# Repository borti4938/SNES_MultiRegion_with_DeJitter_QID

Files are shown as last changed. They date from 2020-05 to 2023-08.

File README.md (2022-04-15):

## Multi-Region Mod for any SNES

**Free your SNES**

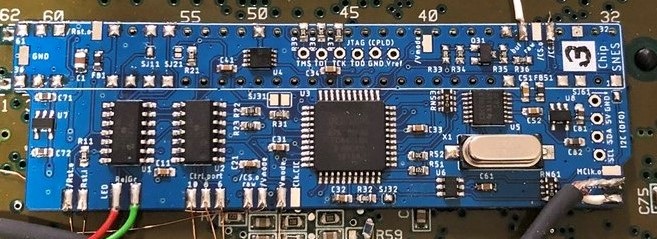
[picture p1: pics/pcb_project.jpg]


(picture shows last prototype PCB installed on a SNS-CPU-RGB-01)

### Acknowledgement and Licensing

This PCB, its idea and design, is a confluence of multiple projects. All credits and rights are going to their respective creators:

- **SuperCIC-lock** by Ikari_01
  Copyright (c) 2010 by Maximilian Rehkopf under GNU GPLv2
  Source: [sd2snes homepage](https://sd2snes.de/blog/cool-stuff/supercic)
- **uIGR** by Ikari_01 and borti4938
  Copyright (c) 2010 by Maximilian Rehkopf under GNU GPLv2,
  and modifications copyright (c) 2015 by Peter Bartmann under GNU GPLv2
  Source: [sd2snes homepage](https://sd2snes.de/blog/cool-stuff/in-game-reset), [this repository](./fw/uIGR)
- **Region Patch** built in SNES by Ikari_01 (initial idea and detection using SuperCIC-lock) and borti4938 (schematic refinement and CPLD implementation)
  Initial idea (c) 2012 ikari_01, CPLD implementation as used here covered in DeJitter license
  Source: [sd2snes homepage](https://sd2snes.de/files/supercic-213f.pdf)
- **DeJitter** by marqs85
  Copyright (c) 2017-2018 Markus Hiienkari under MIT
  and modifications and additions copyright (c) 2019 Peter Bartmann under MIT
  Source: [Original GitHub Repository](https://github.com/marqs85/snes_dejitter), [this repository](./fw/Logic)
- **DFO** by micro
  Copyright / created 2015 by Jakob Schäfer without licensing (but given to retro community)
  Source: mirror in [this repository](./fw/dfo), with minor adaptations and with several original sources noted [in the Source.md file](./fw/dfo/SOURCE.md)
- **PCB design** by borti4938
  Copyright (c) 2019 by Peter Bartmann under GNU GPLv3

### Features and Functions

##### In short

- **SuperCIC:** lockout chip replacement 50Hz/60Hz switch cabability
- **uIGR:** controller input sniffing to perform certain actions like reset or 60Hz and 50Hz switch up on certain combinations
- **Region Patch:** overrides region protection based on picture processing status reads
- **DeJitter:** removes jitter on sync for NTSC mode
- **DFO:** dual frequency oscillator, here used to switch between base clocks for 50Hz, 60Hz video-modes

##### SuperCIC

Hold down the reset button in order to swipe through 50Hz (green LED), 60Hz (red LED) or Auto-Region (yellow LED).

With the sd2snes you are able to pair the SuperCIC with the flash card. Then you'll be able to switch between 60Hz and 50Hz mode. However, you need to have the uIGR, which is master for the region setting, in SuperCIC pass through mode. Some more information is given [below](https://github.com/borti4938/SNES_MultiRegion_with_DeJitter_QID#using-a-modded-snes-with-flashcards).

##### uIGR

The uIGR sniffs the controller inputs directly at the controller port. Therefor it is able to detect certain button combinations. All button combinations are collected in an overview PDF, which is available in [German](https://github.com/borti4938/SNES_MultiRegion_with_DeJitter_QID/blob/master/fw/uIGR/Manuals/uIGR_Anleitung.pdf) and [English](https://github.com/borti4938/SNES_MultiRegion_with_DeJitter_QID/blob/master/fw/uIGR/Manuals/uIGR_Manual.pdf). Here are the most important ones:

- Region forcing:
  - 60Hz: L + R + Select + A
  - 50Hz: L + R + Select + Y
  - Auto: L + R + Select + B
  - S-CIC pass through: L + R + Select + D-pad left OR L + R + Select + D-pad right
- Reset:
  - simple reset: L + R + Select + Start
  - double reset (back to main menu of sd2snes): L + R + Select + X

##### Region Patch

Overwrites region if game request register $213F, where bit 4 represents the region. Region patching can be disabled (see [uIGR PDFs](https://github.com/borti4938/SNES_MultiRegion_with_DeJitter_QID/tree/master/fw/uIGR/Manuals)). You also have to consider switching off the region patch if using non-original cartridges or [flash cards](https://github.com/borti4938/SNES_MultiRegion_with_DeJitter_QID#using-a-modded-snes-with-flashcards) (sd2snes with Pairmode with SuperCIC is not a problem).

##### DeJitter

In NTSC mode the SNES outputs a shorter scanline in non-visible area. This might be an issue for certain TVs if you use pure analog to digital conversion without frame buffer like the OSSC does. DeJitter 'removes' this shorter line by pausing the clock for a few cycles.

As drawback this mechanic varies output timing a bit, however the inaccuracy is neglectable when comparing it to clock variations throughout different consoles.

At the moment, DeJitter is enabled by default and can only be disabled by setting jumper _SJ31_.

##### DFO

Short for dual frequency oscillator. Actually in combination with the CPLD this allows to switch between three output clocks plus two color carrier clocks. If modding board is correctly installed, there is nothing special to consider here.

### PCB Description

#### Solder Pads

These are just general descriptions of the in- and outputs. Please refer to the installation instructions for each [specific mainboard version](./installation/) (if exists) for suitable connections.

- **/Rst.o:** (output (2x))
  Low-active reset output. This has to be connected with CIC-lock pad 10 / S-APU pin 100. Connect either pad.
- **Rst.i:** (input)
  High-active reset input. This pad has to be connected with the CIC-lock pad 8 (reset button).
- **LED.Re:** (output)
  LED driver for replacement LED; usually red. Output is active on 60Hz and auto video mode and off on 50Hz (or vice versa if SJ21 is set (common anode LED))
- **LED.Gr:** (output)
  LED driver for replacement LED; usually green. Output is active on 50Hz and auto video mode and off on 60Hz (or vice versa if SJ21 is set (common anode LED))
- **Ctrl.port.10:** (input)
  Input for controller 1 sniffing (data latch signal). _Port_ refers to flat cable connector of the whole controller panel, i.e. pin is equivalent for controller connector pin 3.
- **Ctrl.port.8:** (input)
  Input for controller 1 sniffing (data clock signal). _Port_ refers to flat cable connector of the whole controller panel, i.e. pin is equivalent for controller connector pin 2.
- **Ctrl.port.6:** (input)
  Input for controller 1 sniffing (serial data signal). _Port_ refers to flat cable connector of the whole controller panel, i.e. pin is equivalent for controller connector pin 4.
- **Vmode:** (output)
  Output sets the PPU video mode at S-PPU1 pin 24 and S-PPU2 pin 30 or at the S-CPUN pin 111. Output is active on 50Hz mode and inactive on 60Hz mode.
- **/Vmode:** (output (2x))
  Output sets the video encoding at the video encoder, which is pin 19 of the S-ENC and pin 9 of the S-RGB. Connect just on of the pads!
- **Clk.CIC:** (input)
  Input for the SuperCIC-lock clock, which comes from CIC pad 7.
- **MClk.o:** (output)
  Output for the (de-jittered) master clock of the SNES. This is approx. 21.477MHz in NTSC mode and appr. 17.734MHz (1Chip-SNES, SJ32 not set) or appr. 21.281MHz (non-1Chip, SJ32 set) in PAL mode. Please refer to the general installation note to see whether and how to connect this pad properly.
- **CClk.o:** (output)
  Output of the color carrier, which is appr. 3.380MHz in NTSC mode and appr. 4.433MHz in PAL mode. Please refer to the general installation note to see whether and how to connect this pad properly.
- **/CS.i:** (input (2x since SMR20190813)
  Input of the 'original' (non-de-jittered) composite sync. This comes from pin 100 S-PPU2 or pin 151 S-CPUN.
- **/CS.o buf:** (output)
  Buffered (de-jittered) composite sync output. This is meant to be connected directly to the multiout pin 3. Note: The PAL SNES has 12V connected to this pin, which has to be removed.
- **/CS.o raw:** (output (2x))
  Raw output of the CPLD, which has 3.3V high and 0V low level. Connect it to the video encode, which is pin 8 of the S-ENC or pin 7 of the S-RGB (both chips allows 2.0V for input high, so 3.3V high is sufficient.)

#### Jumper

- **SJ11:** alternative clock for the SuperCIC; close this jumper if you don't connect the _Clk.CIC_ pad in order to use the clock meant for the CIC-key
- **SJ21:** close this jumper if you use a LED with a common anode. Otherwise leave this jumper untouched
- **SJ31:** closing this jumper permanently disables the de-jitter function. This solder jumper is a bit larger to give the installer the option to connect a slide switch here (_speed-runner discussions_).  
   - There is also an issue opened in [marqs85 DeJitter repository](https://github.com/marqs85/snes_dejitter/issues/9) reported by [BambooShadow](https://github.com/BambooShadow), which states that composite video and s-video becomes flickery. This is probably related to the S-RGB encoder chip on SNS-CPU-RGB-01 and later models (PAL: SNSP-CPU-1CHIP-01 and later). In any case, you can disable DeJitter if this is also an issue for you.  
   - I personally recommend to turn DeJitter off. Turn DeJitter only on if you use simple line doublers like the OSSC and if you have any issue on getting a proper picture.
- **SJ32:** short this jumper if the board is installed in a non-1Chip-SNES (SNES Jr. / SNES2 are also 1Chip-SNES)
- **SJ61:** distributes clock output to cartridge slot pin 1. This jumper **must not** be closed in 1Chip-SNES. Side note: if SJ32 is open, SJ61 has to open, too.
- **SJ63:** (since SMR20200323) decides which color carrier is forwarded to output. This jumper has two option; you must not close both jumpers!
  - SJ63.1: (marked with a dot) outputs color carrier derived from non-dejittered clock.  
    Use this if you have a problem with discoloring on composite video or S-Video ([issue thread at shmups](https://shmups.system11.org/viewtopic.php?p=1389666#p1389666))  
    Btw: this is default for all earlier version of the modding board flashed with the current firmware. If you need the other color carrier, just go back to a previous version.
  - SJ63.2: outputs color carrier derived from dejittered clock.  
    (I personally need to use this clock as my TV does not like the color carrier from non-dejittered clock)
  - Again: **You must not close both jumpers!**
- **SJ93**: (since SMR20200323) controls sync level of buffered csync output. Sync level:
  - opened: appr. 1.87V @ 75ohm termination i.e. needs a resistor inside the sync wire further attanuating the signal. Designed to work for cables with 470 ohm resistor inside resulting in appr. 450mV @ 75ohm termination
  - closed: appr. 300mV @ 75ohm termination suitable for pass through wired cables at sync, works with standard TV / scaler setup

#### Firmware

U1, U2, U3 and U5 need a firmware flashed to the chip. U1 and U2 have to be programmed prior to assembly whereas the PCB provides ICSP headers for the other ones.

- **U1:** PIC 16F630 microcontroller with - [SuperCIC-lock firmware](http://sd2snes.de/files/supercic.zip)
- **U2:** PIC 16F684 microcontroller with [uIGR firmware](https://raw.githubusercontent.com/borti4938/SNES_MultiRegion_with_DeJitter_QID/master/fw/uIGR/snes_uigr_684_with_lock.hex)

Use a PICKit, TL866CS or similar programmer.

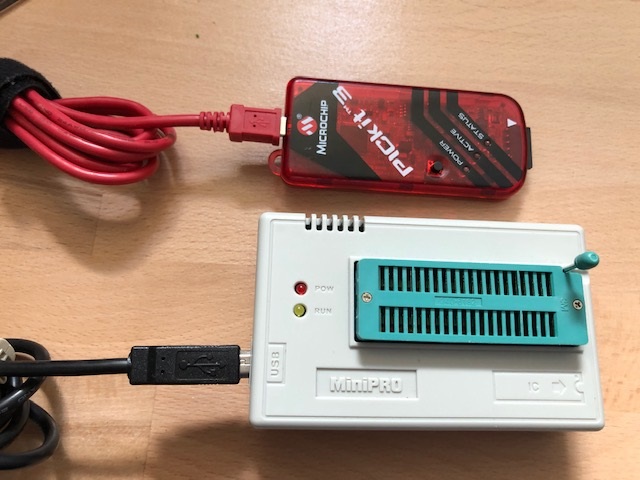
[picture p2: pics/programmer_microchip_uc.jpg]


- **U3:** _ATMEL_ CPLDs: ATF1502ASV or ATF1504ASV(L) CPLD with clock switch, region patch and de-jitter firmware. Pre-build firmware only supports SMR20190813 (and later) modding boards.

  - [ATF1502ASV](https://github.com/borti4938/SNES_MultiRegion_with_DeJitter_QID/raw/master/fw/Logic/output_files/multi_func_atmel/multi_function.svf)
  - [ATF1504ASV(L)](https://github.com/borti4938/SNES_MultiRegion_with_DeJitter_QID/raw/master/fw/Logic/output_files/multi_func_atmel/multi_function_64.svf)
  
Use an OpenOCD compatible JTAG programmer. I tested the workflow with an [Adafruit FT232H Breakout Board](https://www.adafruit.com/product/2264), yet you can use any other JTAG programmer that supports 3.3V IO signal levels.

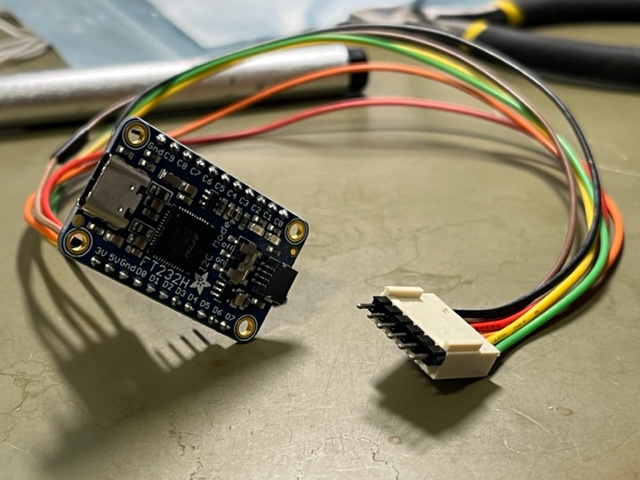
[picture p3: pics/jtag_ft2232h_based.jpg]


1. Create an openocd.conf that matches your JTAG programmer. A configuration files for FT2232-based and FT2232H programmers are found in the [firmware folder](./fw/Logic/output_files/multi_func_atmel/). They use following standard pinout for data signals:  
  - ADBUS0 -> TCK
  - ADBUS1 -> TDI
  - ADBUS2 -> TDO
  - ADBUS3 -> TMS
2. Connect the JTAG programmer the modding board, except for Vref! Power the board via 5V during programming.  This can be done by using the DFO programmer connected with V_target set to 5V (or 3.3V) if the modding board is not installed yet (other power solutions are possible, but please use the 5V power supply rail to not harm the DC converters. Or you can simply switch on the SNES for programming. Of course, the CPLD can be also flashed prior to assembly if you have a proper adapter at hand.
3. Initialize the JTAG connection:  
~~~~
openocd -f openocd-ft2232h.conf
~~~~  
OpenOCD should detect the JTAG chain without any errors. If you have any, just double-check if everything is well connected and the CPLD is powered.

4. When successful, open another terminal to interact with openocd and program the chip:  
~~~~
telnet localhost 4444
> svf <full_path_to_svf_file>
~~~~  
Wait for the program to be finished.

- **U3:** _obsolete Altera / intelFPGA CPLDs_: EPM7032 or EPM7064 CPLD with clock switch, region patch and de-jitter firmware. You have to choose the right one depending on your modding board version.

  - [Version SMR20190813 (and later), EPM7032](https://github.com/borti4938/SNES_MultiRegion_with_DeJitter_QID/raw/master/fw/Logic/output_files/multi_func/multi_function.pof)
  - [Version SMR20190813 (and later), EPM7032](https://github.com/borti4938/SNES_MultiRegion_with_DeJitter_QID/raw/master/fw/Logic/output_files/multi_func/multi_function_64.pof)
  - [Version SMR20190603 and earlier](https://github.com/borti4938/SNES_MultiRegion_with_DeJitter_QID/raw/master/fw/Logic/output_files/multi_func_legacy/multi_func_legacy.pof)

Use an Altera USB Blaster (or clone) for flashing the firmware.

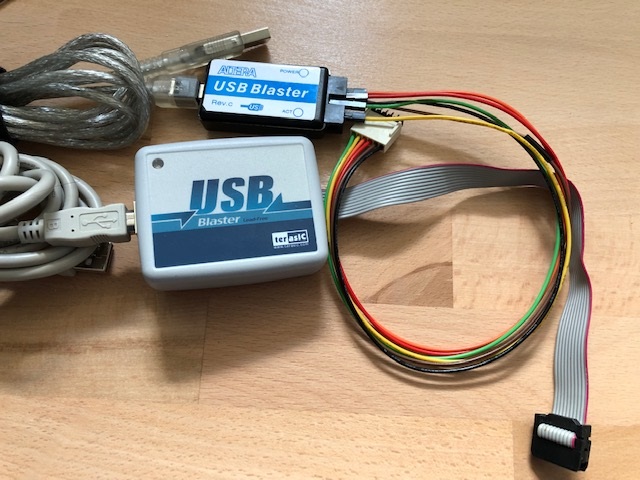
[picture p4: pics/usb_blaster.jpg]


After assembly, the modding board has to be powered for flashing the firmware. This can be done by using the DFO programmer connected with V_target set to 5V (or 3.3V) if the modding board is not installed yet (other power solutions are possible, but please use the 5V power supply rail to not harm the DC converters. Or you can simply switch on the SNES for programming. Of course, the CPLD can be also flashed prior to assembly if you have a proper adapter at hand.

- **U5:** CDCE913 with [appropriate configuration](https://raw.githubusercontent.com/borti4938/SNES_MultiRegion_with_DeJitter_QID/master/fw/dfo/clockpro/snes_multi_region.hex)

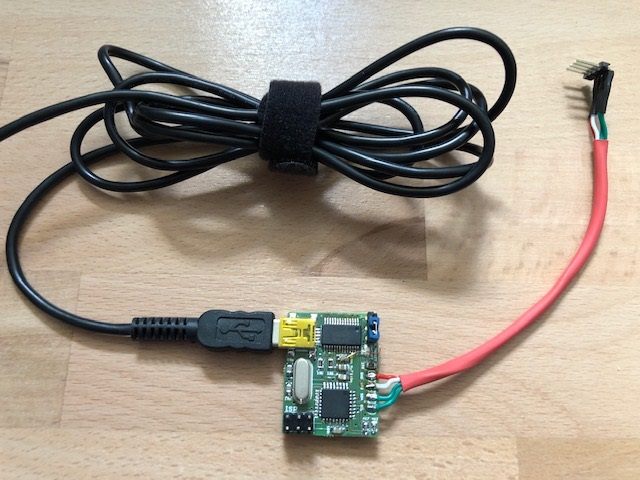
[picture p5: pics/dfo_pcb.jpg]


Use the DFO programmer to flash the PLL. The [DFO readme](./fw/dfo/SOURCE.md) describes how to properly perform the flashing.
I alternatively wrote a [program for Arduino boards](./fw/dfo/arduino/) to flash the CDCE913 with the I2C interface of the Arduino.
I tested the code with an Arduino Nano and Arduino Nano Every.

### Installation Notes

#### Manufacturing the PCB

You can choose any manufacturer which you prefer. All files for manufacturing including the design files are provided in subfolder [pcb/gerber/pcb/](./pcb/gerber/pcb/). As the PCB is designed in EAGLE (current version 7.4.2), gerbers are exported in the actual format. However, some services have problem while automatically analyze those like OSHPark or JCLPCB. Please try the older format in [pcb/gerber/pcb.eagle_legacy_export/](./pcb/gerber/pcb.eagle_legacy_export/).

**IMPORTANT**
Please use a substrate thickness of 0.8mm in order to make installation easier.

#### Assembly

##### Sourcing the Parts

For sourcing the parts, please be referred to the [Bill Of Materials](https://github.com/borti4938/SNES_MultiRegion_with_DeJitter_QID/blob/master/pcb/BOM.xlsx?raw=true)

##### Soldering

The PCB is designed with having hand soldering in mind. Most complicated footprints are probably the 44TQFP package of the CPLD or the 14TSSOP of the CDCE913.

However, if you plan to use a stencil, you can use the [stencil gerber file](./pcb/gerber/stencil/SNES_MR_DeJitter_QID.GTP). All SMDs are placed in top layer.

**IMPORTANT**
SuperCIC (PIC16F630-I/SL) and uIGR (PIC16F684-I/SL) need firmware flashed prior to soldering as mentioned later in this document.

#### Installation

This is not a complete installation manual. It's moreover a general overview on _'HowTo'_. Installation manuals are provided in the [subfolder installation](./installation/) once ready. I cannot test every single mainboard revision (there are too many out there), so the installation folder will grow from time to time once I see a proper report of an installation or I did an installation on a specific mainboard version on my own.

##### Preparation of SNES

###### General Steps

- remove original CIC-lock (or at least lift pins 1, 2, 10 and 11)
- remove LED from front panel (large SNES only)

###### Specific Steps for 1Chip-SNES

- lift pin 111 from S-CPUN
- remove X1
- lift pin 9 from S-RGB (or cut encoding mode jumper at bottom side of SNES mainboard (NTSC board revisions))

###### Specific Steps for Non-1Chip-SNES

- lift pin 24 of S-PPU1 and pin 30 of S-PPU2
- disconnect Master-Clock
  - SNSP-CPU-01/02: lift pin 4 of the S-CLK or remove R73 (0ohm jumper)
  - different methods for NTSC mainboards
- lift CSYNC input pin of the video encoder
  - pin 8 of S-ENC
  - pin 7 of S-RGB
- if you want to switch color carrier:
  - PAL: lift pin 5 of the S-CLK
  - NTSC: lift pin 3 of the S-PPU2
  - SNES with S-ENC: lift pin 19 (or cut encoding mode jumper at bottom side of SNES mainboard (NTSC board revisions))
  - SNES with S-RGB: lift pin 9 (or cut encoding mode jumper at bottom side of SNES mainboard (NTSC board revisions)) 

##### Installation of PCB

###### General Steps

- Solder PCB in place under the cartridge slot. Be aware of the orientation (pin marking must match)
- put the replacement dual LED where the original was (use a small piece of hot glue if needed)...  
... or in SNES2 / Jr. think of a good place where the replacement LED can be if you want to use it...  
... and connect the common pole to either _Ground_ or _Vcc_ (common cathod or anode, respectively)
- connect pads _Rst.o, Rst.i, LED.Re, LED.Gr, Ctrl.port.10-6, Vmode, /CS.i, /CS.o (raw)_ according to their description
- either connect _Clk.CIC_ pad (preferable) or close jumper _SJ11_
- close jumper _SJ21_ if you use a LED with common anode

###### Specific Step for 1Chip-SNES

- connect _MCLK.o_ to X1 (the side which is connected to S-CPUN pin 9)
- connect _/Vmode_ to S-RGB pin 9
- (color carrier is switched by S-CPUN so there is no need to connect _CClk.o_)

###### Specific Step for Non-1Chip-SNES 

- close _SJ32_ and _SJ61_
- if you plan to switch color carrier:
  - connect _CClk.o_ to either pad 3 of S-PPU2 (NTSC) or to pad 5 of S-CLK (PAL)
  - connect _/Vmode_ to S-ENC pin 19 / S-RGB pin 9 

### Using a Modded SNES with Flashcards

In general, using flashcards like the sd2snes, SuperEverdrive and PowerPak together with the **region patching** activated is not a good idea. I try to explain why!

First of all, one has to understand how a region patch works. In the S-PPU2 register $213F bit 4 shows whether the SNES is running in NTSC-mode or in PAL-mode (set up using S-PPU2 pin 30 or S-CPUN pin 111). Many games are checking this register on start-up (or during the gameplay) and check the value on bit 4. NTSC-games expect a '0' whereas PAL-games a '1'. If the bit does not return the required value, the game ends with _'This gamepak is not designed for your SFC/SNES'_ or similar.
A region patch observes the address bus B and recognizes a request of $213F. Then the patch forces on the data bus bit 4 GND or Vcc by simply 'beating'/'overdriving' the output of the S-PPU2.

An important point is how the region patch 'knows' which value has to be written.
On this modding PCB the SuperCIC-lock outputs the value on pin 3. The bit is determined using the CIC-key found on the cartridge. And this is the point where flash-cards become 'critical' for the region patch. As the SuperCIC-lock only checks the region of the cartridge using the CIC-key, the SuperCIC-lock CANNOT know which region the loaded ROM is. The overwritten value on bit 4 during a $213F request might be incorrect!
As flashcards have there own region patching (at least the sd2snes; I don't own a SuperEverdrive or PowerPak) you can simply switch off the region patch of the modding PCB (using Sel+L+R+Dw; LED-code: red-off-red).

#### A very last remark to the sd2snes:
As the SuperCIC-lock is part of the sd2snes project, there is another solution: the so-called 'Pairmode'.
The pairmode is available with the firmware v0.1.7 preview 4 or later. In the Pairmode the SuperCIC-lock goes into a pairmode-loop with the sd2snes. In this loop, forced region, LED status and the ROM region is constantly updated.

To change the forced region (and thus the LED-state) using the sd2snes (via the config.yml or the option GUI -> SuperCIC Settings), the uIGR has to be in the SuperCIC-mode (using Sel+L+R+Le / Sel+L+R+Ri) as the uIGR is master and the SuperCIC-lock slave regarding the region set to the SNES.
As the ROM region is updated constantly, the region patch on the modding PCB can be left on. I recommend to switch the sd2snes-own region patch off in this case (via the config.yml or the option GUI -> In-game Settings).

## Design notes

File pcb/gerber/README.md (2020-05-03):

(text copied from main [README](../README.md))

#### Manufacturing the PCB

You can choose any manufacturer which you prefer. All files for manufacturing including the design files are provided in subfolder [pcb/](./pcb/). As the PCB is designed in EAGLE (current version 7.4.2), gerbers are exported in the actual format. However, some services have problem while automatically analyze those like OSHPark or JCLPCB. Please try the older format in [pcb.eagle_legacy_export/](./pcb.eagle_legacy_export/).

For using the OSHPark service, you can also use my [uploaded project](https://oshpark.com/shared_projects/6n0e1VDd).

##### Soldering

The PCB is designed with having hand soldering in mind. Most complicated footprints are probably the 44TQFP package of the CPLD or the 14TSSOP of the CDCE913.

However, if you plan to use a stencil, you can use the [stencil gerber file](./stencil/SNES_MR_DeJitter_QID.GTP). All SMD are placed in top layer.

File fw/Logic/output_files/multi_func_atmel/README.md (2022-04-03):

Use this firmware for SNES [Multi Region Boards](https://github.com/borti4938/SNES-AddOn-PCBs/tree/master/MultiRegion_with_DeJitter_QID) of version V20190813 (and later).

These firmware files are for the Atmel CPLD equivalents and introduced in this repository as the Altera CPLDs became obsolete.

Conversion of the Altera firmware build to the Atmel ATF1502ASV or ATF1504ASV(L):

- Use [pof2jed](http://www.microchip.com/design-centers/programmable-logic/spld-cpld/tools/software/pof2jed) conversion tool to convert \*.pof from Quartus output to \*.jed usable with the Atmel CPLD. Use the settings as shown
- Use [ATMISP](http://www.microchip.com/design-centers/programmable-logic/spld-cpld/tools/software/atmisp) software to convert the JED file to a SVF file, which can be used with OpenOCD
  - Create a new device chain via File->New
  - Set number of devices to 1
  - Set device to ATF1502ASV or ATF1504ASV(L)
  - Set JTAG instruction to "Program/Verify"
  -  Select .jed file from previous step as JEDEC file
  - Click "OK"
  - Tick "Write SVF file" and click "Run"

##### Setting for WinPOF2JED tool:

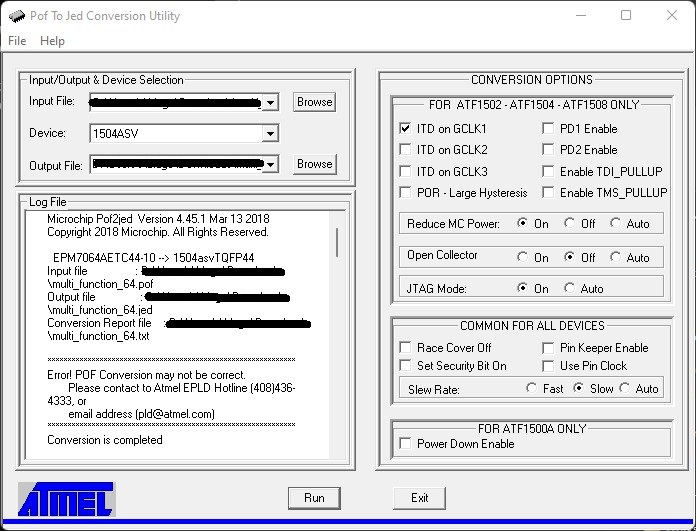
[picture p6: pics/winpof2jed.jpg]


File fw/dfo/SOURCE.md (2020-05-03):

### DFO

#### Acknowledgement and Licensing

Original source by community user _micro_. All rights goes to him.

- Source @ Circuit-Board.de: [Link](https://circuit-board.de/forum/index.php/Thread/18016-DFO-Dual-Frequency-Oscillator/)
- Source @ NFGgames: [Link](https://nfggames.com/forum2/index.php?topic=5744.0)
- Source @ OSHPark: [Link](https://oshpark.com/shared_projects/SeJLCY52)

Source links will forward you to original source codes. Source codes provided in this repository are just mirrors.

#### Modifications Compared to Original Source

Modifications made by Peter Bartmann aka borti4938 in 2019:

- PCB: remove slide switch and replace it with pin header
- Allow V_target to be at 5V (right position shorted)

#### Firmware for Programmer

Microcontroller on the programmer PCB needs a firmware (written by micro) in order to work properly. Use the firmware provided in [this subfolder](./CDCE9XX_PROGRAMMER_FW_v1) or the one in the original source. Please make sure to set the [fusebytes](./CDCE9XX_PROGRAMMER_FW_v1/fusebytes.txt) correctly. 

#### Program the CDCE913 (DFO) on the MultiRegion PCB

Use the [GUI](./CDCE9XX_Programmer_GUI_v1.1/CDCE9XX_PROGRAMMER.exe) (software written by micro) in order to program the PLL. This is required in order to get the DeJitter and on-board color carrier switch working. To program the PLL perform the following steps:

##### modding board not installed

- Set V-target jumper on programmer to 5V
- Connect programmer to modding board
  (make sure that the connector is matched otherwise you may harm your modding board!)
- Connect USB cable to Windows PC
- Launch [programmer app](./CDCE9XX_Programmer_GUI_v1.1/CDCE9XX_PROGRAMMER.exe)
- Load [hex-file](./clockpro/snes_multi_region.hex) for the CDCE913 by clicking on _Load Configuration File_
- Click on _Program CDCE9xx_ button
- Disconnect everything once finished

##### modding board installed in SNES

- Leave V-target jumper open
- Connect programmer to modding board
  (make sure that the connector is matched otherwise you may harm your modding board and/or the DFO programmer!)
- Connect USB cable to Windows PC
- Switch on SNES
- Launch [programmer app](./CDCE9XX_Programmer_GUI_v1.1/CDCE9XX_PROGRAMMER.exe)
- Load [hex-file](./clockpro/snes_multi_region.hex) for the CDCE913 by clicking on _Load Configuration File_
- Click on _Program CDCE9xx_ button
- Disconnect everything once finished

#### Picture



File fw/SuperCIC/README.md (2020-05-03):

##### Source Code

... can be downloaded at [sd2snes.de](https://sd2snes.de/blog/cool-stuff/supercic) [direct download link](http://sd2snes.de/files/supercic.zip)

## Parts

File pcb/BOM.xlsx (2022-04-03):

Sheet: SMR20200325
Version: | SMR20200325
Number of PCBs: |  |  | 3
Designator | MPN | QTY/PCB | QTY | DESCRIPTION | VALUE | PACKAGE | NOTES | Digikey | Mouser | Firmware
U1 | PIC16F630-I/SL | 1 | 3 | 8bit Microcontroller |  | SOIC-14 | needs SuperCIC-lock firmware preflashed |  |  | http://sd2snes.de/files/supercic.zip
U2 | PIC16F684-I/SL | 1 | 3 | 8bit Microcontroller |  | SOIC-14 | needs uIGR FW preflashed |  |  | https://github.com/borti4938/Switchless-Mods/tree/master/SNES/uigr_16f684
U3 | ATF1502ASV-15AU44 | 1 | 3 | CPLD, 32MCs, 3.3Vcc, 5V tolerant I/Os |  |  | fw can be flashed using JTAG header |  |  | https://github.com/borti4938/snes_dejitter/tree/regionpatch%2Bdejitter/output_files/multi_func_atmel/multi_function.svf
 | ATF1504ASV-15AU44 / ATF1504ASVL-20AU44 |  |  | CPLD, 64MCs, 3.3Vcc, 5V tolerant I/Os |  |  | alternative for U3 / fw can be flashed using JTAG header |  |  | https://github.com/borti4938/snes_dejitter/tree/regionpatch%2Bdejitter/output_files/multi_func_atmel/multi_function_64.svf
 | EPM7032AETC44-10N |  |  | CPLD, 32MCs, 3.3Vcc, 5V tolerant I/Os |  | TQFP44 | alternative for U3, obsolete cpld, yet can be found on Aliexpress / fw can be flashed using JTAG header |  |  | https://github.com/borti4938/SNES_MultiRegion_with_DeJitter_QID/blob/master/fw/Logic/output_files/multi_func/multi_function.pof
 | EPM7064AETC44-10N |  |  | CPLD, 64MCs, 3.3Vcc, 5V tolerant I/Os |  | TQFP44 | alternative for U3, obsolete cpld, yet can be found on Aliexpress / fw can be flashed using JTAG header |  |  | https://github.com/borti4938/SNES_MultiRegion_with_DeJitter_QID/blob/master/fw/Logic/output_files/multi_func/multi_function_64.pof
U4 | 74HCT2G125DP | 1 | 3 | IC BUFFER NON-INVERT with /OE |  | TSSOP8, SOT505-2
U5 | CDCE913PWR | 1 | 3 | IC PROG PLL VCXO CLK SYN |  | 14TSSOP | I2C accessable over PCB header |  |  | https://github.com/borti4938/SNES-AddOn-PCBs/tree/master/MultiRegion_with_DeJitter_QID/dfo/clockpro
U6 | SN74LVC2G17DBVR | 1 | 3 | IC BUFFER NON-INVERT, Schmitt Trigger |  | SOT-23-6
U7 | TLV70033DDCR | 1 | 3 | LDO 3.3V |  | SOT-23-5
U8 | TLV70018DDCR | 1 | 3 | LDO 1.8V |  | SOT-23-5
U9 | TSH122ICT | 1 | 3 | Video Driver, 6dB, 1 Ch. |  | SC-70-6
X1 | 9C-27.000MAAJ-T | 1 | 3 | CRYSTAL 27.0000MHZ 18PF | 27MHz | HC-49/US
C1,C94 | (22uF cap 0603) | 2 | 6 | Ceramic capacitor, X5R | 22uF / 16V | SMD0603
C11,C21,C31,C32,C33,C34,C41,C51,C52,C61 | (100nF cap 0603) | 10 | 30 | Ceramic capacitor, X7R | 0.1uF / 50V | SMD0603
C71,C72,C81,C82 | (1uF cap 0603) | 4 | 12 | Ceramic capacitor, X5R | 1uF / 6.3V | SMD0603
C91 | (10uF cap 0603) | 1 | 3 | Ceramic capacitor, X5R | 10uF / 25V | SMD0603
C92 | (10nF cap 0603) | 1 | 3 | Ceramic capacitor, X7R | 0.01uF / 50V | SMD0603
C93 | (33uF cap 0805) | 1 | 3 | Ceramic capacitor, X5R | 33uF / 5V | SMD0805
FB1,FB51 | MPZ1608S221A | 2 | 6 | Ferrit bead, power line |  | SMD0603
R11,R21,R32,R38,R39,R52,R63 | RC0603FR-0710KL | 7 | 21 | Resistor | 10k | SMD0603
R22,R23 | RC0603FR-07180RL | 2 | 6 | Resistor | 180 | SMD0603
R31,R37 | RC0603FR-071KL | 2 | 6 | Resistor | 1k | SMD0603
R51 | RC0603FR-0722KL | 1 | 3 | Resistor | 22k | SMD0603
R53,R54,R61 | RC0603FR-0739RL | 3 | 9 | Resistor | 39 | SMD0603
R62 |  | 0 | 0 | Resistor / Jumper |  | SMD0805 | resistor taken from SNES mainboard / jumper closed, if CClk.o directly connected to SNES
R91 | RC0603FR-074K7L | 1 | 3 | Resistor | 4.7k | SMD0603
R92 | RC0603FR-076K19L | 1 | 3 | Resistor | 6.19k | SMD0603
R93 | RC0603FR-07523RL | 1 | 3 | Resistor | 523 | SMD0603
R94 | RC0603FR-0775RL | 1 | 3 | Resistor | 75 | SMD0603
Optional components
(LED) | WP59SURKSGW | 1 | 3 | example replacement LED bi-color with common cathode | red / green
(pin header for LED connection) | 61900211021 | 1 | 3 | pin header for LED connection
 | 61900211621 | 1 | 3 | connector housing 2-pos. Female 2.54mm
 | 61900113722DEC | 2 | 6 | connector socket for 22-28AWG crimp

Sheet: SMR20190813
Version: | SMR20190813
Number of PCBs: |  |  | 3
Designator | MPN | QTY/PCB | QTY | DESCRIPTION | VALUE | PACKAGE | NOTES | Digikey | Mouser | Firmware
U1 | PIC16F630-I/SL | 1 | 3 | 8bit Microcontroller |  | SOIC-14 | needs SuperCIC-lock firmware preflashed |  |  | http://sd2snes.de/files/supercic.zip
U2 | PIC16F684-I/SL | 1 | 3 | 8bit Microcontroller |  | SOIC-14 | needs uIGR FW preflashed |  |  | https://github.com/borti4938/Switchless-Mods/tree/master/SNES/uigr_16f684
U3 | ATF1502ASV-15AU44 | 1 | 3 | CPLD, 32MCs, 3.3Vcc, 5V tolerant I/Os |  |  | fw can be flashed using JTAG header |  |  | https://github.com/borti4938/snes_dejitter/tree/regionpatch%2Bdejitter/output_files/multi_func_atmel/multi_function.svf
 | ATF1504ASV-15AU44 / ATF1504ASVL-20AU44 |  |  | CPLD, 64MCs, 3.3Vcc, 5V tolerant I/Os |  |  | alternative for U3 / fw can be flashed using JTAG header |  |  | https://github.com/borti4938/snes_dejitter/tree/regionpatch%2Bdejitter/output_files/multi_func_atmel/multi_function_64.svf
 | EPM7032AETC44-10N |  |  | CPLD, 32MCs, 3.3Vcc, 5V tolerant I/Os |  | TQFP44 | alternative for U3, obsolete cpld, yet can be found on Aliexpress / fw can be flashed using JTAG header |  |  | https://github.com/borti4938/SNES_MultiRegion_with_DeJitter_QID/blob/master/fw/Logic/output_files/multi_func/multi_function.pof
 | EPM7064AETC44-10N |  |  | CPLD, 64MCs, 3.3Vcc, 5V tolerant I/Os |  | TQFP44 | alternative for U3, obsolete cpld, yet can be found on Aliexpress / fw can be flashed using JTAG header |  |  | https://github.com/borti4938/SNES_MultiRegion_with_DeJitter_QID/blob/master/fw/Logic/output_files/multi_func/multi_function_64.pof
U4 | 74HCT2G125DP | 1 | 3 | IC BUFFER NON-INVERT with /OE |  | TSSOP8, SOT505-2
U5 | CDCE913PWR | 1 | 3 | IC PROG PLL VCXO CLK SYN |  | 14TSSOP | I2C accessable over PCB header |  |  | https://github.com/borti4938/SNES-AddOn-PCBs/tree/master/MultiRegion_with_DeJitter_QID/dfo/clockpro
U6 | SN74LVC2G17DBVR | 1 | 3 | IC BUFFER NON-INVERT, Schmitt Trigger |  | SOT-23-6
U7 | TLV70033DDCR | 1 | 3 | LDO 3.3V |  | SOT-23-5
U8 | TLV70018DDCR | 1 | 3 | LDO 1.8V |  | SOT-23-5
Q31 | 2SC2412KT146R | 1 | 3 | TRANS NPN 50V 0.15A |  | TO-236-3, SC-59, SOT-23-3
X1 | 9C-27.000MAAJ-T | 1 | 3 | CRYSTAL 27.0000MHZ 18PF | 27MHz | HC-49/US
C1 | (22uF cap 0805) | 1 | 3 | Ceramic capacitor, X5R | 22uF / 16V | SMD0805
C11,C21,C31,C32,C33,C34,C41,C51,C52,C61 | (100nF cap 0603) | 10 | 30 | Ceramic capacitor, X7R | 0.1uF / 50V | SMD0603
C71,C72,C81,C82 | (1uF cap 0603) | 4 | 12 | Ceramic capacitor, X5R | 1uF / 6.3V | SMD0603
FB1,FB51 | MPZ1608S221A | 2 | 6 | Ferrit bead, power line |  | SMD0603
R11,R21,R32,R34,R38,R39,R52 | RC0603FR-0710KL | 7 | 21 | Resistor | 10k | SMD0603
R22,R23 | RC0603FR-07180RL | 2 | 6 | Resistor | 180 | SMD0603
R31,R33,R37 | RC0603FR-071KL | 3 | 9 | Resistor | 1k | SMD0603
R35 | RC0603FR-07300RL | 1 | 3 | Resistor | 300 | SMD0603
R36 | RC0603FR-07100RL | 1 | 3 | Resistor | 100 | SMD0603
R51 | RC0603FR-0722KL | 1 | 3 | Resistor | 22k | SMD0603
R53,R54,R61 | RC0603FR-0739RL | 3 | 9 | Resistor | 39 | SMD0603
R62 |  | 0 | 0 | Resistor / Jumper |  | SMD0805 | resistor taken from SNES mainboard / jumper closed, if CClk.o directly connected to SNES
Optional components
(LED) | WP59SURKSGW | 1 | 3 | example replacement LED bi-color with common cathode | red / green
(pin header for LED connection) | 61900211021 | 1 | 3 | pin header for LED connection
 | 61900211621 | 1 | 3 | connector housing 2-pos. Female 2.54mm
 | 61900113722DEC | 2 | 6 | connector socket for 22-28AWG crimp

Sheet: SMR20190603
Version: | SMR20190603 | (and earlier)
Number of PCBs: |  |  | 3
Designator | MPN | QTY/PCB | QTY | DESCRIPTION | VALUE | PACKAGE | NOTES | Digikey | Mouser | Firmware
U1 | PIC16F630-I/SL | 1 | 3 | 8bit Microcontroller |  | SOIC-14 | needs SuperCIC-lock firmware preflashed |  |  | http://sd2snes.de/files/supercic.zip
U2 | PIC16F684-I/SL | 1 | 3 | 8bit Microcontroller |  | SOIC-14 | needs uIGR FW preflashed |  |  | https://github.com/borti4938/Switchless-Mods/tree/master/SNES/uigr_16f684
U3 | EPM7032AETC44-10N | 1 | 3 | CPLD, 32MCs, 3.3Vcc, 5V tolerant I/Os |  | TQFP44 | fw can be flashed using JTAG header |  |  | https://github.com/borti4938/SNES_MultiRegion_with_DeJitter_QID/blob/master/fw/Logic/output_files/multi_func_legacy/multi_func_legacy.pof
U4 | 74HCT2G125DP | 1 | 3 | IC BUFFER NON-INVERT with /OE |  | TSSOP8, SOT505-2
U5 | CDCE913PWR | 1 | 3 | IC PROG PLL VCXO CLK SYN |  | 14TSSOP | I2C accessable over PCB header |  |  | https://github.com/borti4938/SNES-AddOn-PCBs/tree/master/MultiRegion_with_DeJitter_QID/dfo/clockpro
U6 | SN74LVC2G17DBVR | 1 | 3 | IC BUFFER NON-INVERT, Schmitt Trigger |  | SOT-23-6
U7 | TLV70033DDCR | 1 | 3 | LDO 3.3V |  | SOT-23-5
U8 | TLV70018DDCR | 1 | 3 | LDO 1.8V |  | SOT-23-5
Q31 | 2SC2412KT146R | 1 | 3 | TRANS NPN 50V 0.15A |  | TO-236-3, SC-59, SOT-23-3
X1 | 9C-27.000MAAJ-T | 1 | 3 | CRYSTAL 27.0000MHZ 18PF | 27MHz | HC-49/US
C1 | (22uF cap 0805) | 1 | 3 | Ceramic capacitor, X5R | 22uF / 16V | SMD0805
C11,C21,C31,C32,C33,C34,C41,C51,C52,C61 | (100nF cap 0603) | 10 | 30 | Ceramic capacitor, X7R | 0.1uF / 50V | SMD0603
C71,C72,C81,C82 | (1uF cap 0603) | 4 | 12 | Ceramic capacitor, X5R | 1uF / 6.3V | SMD0603
FB1,FB51 | MPZ1608S221A | 2 | 6 | Ferrit bead, power line |  | SMD0603
R11,R21,R32,R34,R38,R39,R52 | RC0603FR-0710KL | 7 | 21 | Resistor | 10k | SMD0603
R22,R23 | RC0603FR-07180RL | 2 | 6 | Resistor | 180 | SMD0603
R31,R33,R37 | RC0603FR-071KL | 3 | 9 | Resistor | 1k | SMD0603
R35 | RC0603FR-07300RL | 1 | 3 | Resistor | 300 | SMD0603
R36 | RC0603FR-07100RL | 1 | 3 | Resistor | 100 | SMD0603
R51 | RC0603FR-0722KL | 1 | 3 | Resistor | 22k | SMD0603
RN53,RN61 | CAY16-39R0F4LF | 2 | 6 | Resistor-Array | 39 | SMD1206 | Alternatives with 5% tolerance are sufficient
Optional components
(LED) | WP59SURKSGW | 1 | 3 | example replacement LED bi-color with common cathode | red / green
(pin header for LED connection) | 61900211021 | 1 | 3 | pin header for LED connection
 | 61900211621 | 1 | 3 | connector housing 2-pos. Female 2.54mm
 | 61900113722DEC | 2 | 6 | connector socket for 22-28AWG crimp

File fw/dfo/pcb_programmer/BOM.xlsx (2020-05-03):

QTY | Description | mouser.com part-no | optional
1x | FT232RL USB UART interface IC | 895-FT232RL
1x | ATMEGA48A microcontroller | 556-ATMEGA48A-AU
1x | Mini USB socket | 587-690-005-299-143
1x | Vt pin header 3pos. 2.54mm | 571-826936-3 | x
1x | Vt shunt 2pos. 2.54mm | 571-8815452 | x
1x | Prog pin header 4pos. 2.54mm | 571-826936-4 | x
1x | uC ICSP pin header 2x3pos. 2.54mm | 571-4-146262-1 | x
1x | 8 MHz crystal | 774-ATS080B
3x | 100 nF capacitor | 80-C0805C104K5R
1x | 4.7 uF capacitor | 581-08053D475K
2x | 18 pF capacitor | 77-VJ0805A180GXJCBC
1x | 330 Ohm resistor | 71-CRCW0805-330-E3
2x | 10 kOhm resistor | 71-CRCW0805J-10K-E3
2x | 4.7 kOhm resistor | 71-CRCW0805-4.7K-E3
1x | LED | 720-LSR976-NR-1
EXAMPLES

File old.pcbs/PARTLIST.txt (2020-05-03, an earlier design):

List of parts needed  
====================  
  
common parts (both designs):  
----------------------------  
- 1x PIC16F630-I/SL (SOIC14 package; flashed with program for the SuperCIC-Lock)  
- 1x PIC16F684-I/SL (SOIC14 package; flashed with program for the uIGR V2)  
  
- 74*27 (SOIC14 package; * = LS, HC or HCT family)  
- 74*30 (SOIC14 package; * = LS, HC or HCT family)  
- 74HC(T)125 (SOIC14 package; use HC or HCT family)  
  
- 5x 0.1uF ceramic capacitor (SMD 0805 package; rated 25V or more)  
  
- 2x 180 Ohms resistor (SMD 0805 package; 1/8 watts should be fine)  
- 1x 10k Ohms resistor (SMD 0805 package; 1/8 watts should be fine)  
  
- 1x Dual-LED (replacement for the red LED; a red/green-LED with 5mm diffuse lens is recommended)  
  
additional parts for the 1Chip-SNES design:  
-------------------------------------------  
- 74*00 (SOIC14 package; * = LS, HC or HCT family)  
- 74HCU04 (SOIC14 package; U = unbuffered!!!)  
  
- 4x 22pF ceramic capacitor (SMD 0805 package; rated 25V or more)  
- 2x 0.1uF ceramic capacitor (SMD 0805 package; rated 25V or more)  
  
- 2x 330 Ohms resistor (SMD 0805 package; 1/8 watts should be fine)  
- 2x 1M Ohms resistor (SMD 0805 package; 1/8 watts should be fine)  
  
- 1x 17.734475MHz crystal (HC49 package; either SMD or THT) [*]
- 1x 21.477273MHz crystal (HC49 package; either SMD or THT) [*]  

[*] Small Hint:  
Isolate the bottom of the crystals if you use a THT resistor without an isolator attached. This avoids a short between both pins.

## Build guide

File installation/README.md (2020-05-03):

### Some General Notes

- Installation guides might be incomplete
- Guides does not include _open_ and _close_ the SNES housing
- When routing wires, keep in mind that the SNES housing might not allow the shortest route especially if you route a wire from bottom to top side
- Take your time
- Please read the main [readme](../README.md) first for general notes and explanations.

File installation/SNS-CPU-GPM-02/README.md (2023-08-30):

## SNS-CPU-GPM-02

The following instructions are specifically tailored towards the SNS-CPU-GPM-02
mainboard version of the Super Famicom (Japanese SNES).

While they should also apply to the SNS-CPU-GPM-01 version for the most part
(if not entirely), I do not have that version at hand to verify.

### Disassembly

- Open the case and carefully remove all moving parts of the cartridge eject
  mechanism.
- Unscrew the power slide switch. You may leave it connected, but be careful
  while handling the mainboard.
- Unscrew and remove the metal shield covering the lower half of the mainboard
  near the controller panel.
- Unscrew and remove the cartridge slot as it also holds the mainboard in place.
- Disconnect the ribbon cable to the controller panel from the mainboard.
- Unscrew and remove the mainboard from the case.

### Mainboard Preparation

- Remove the original CIC-lock (or just lift pins 1, 2, 10 and 11).  
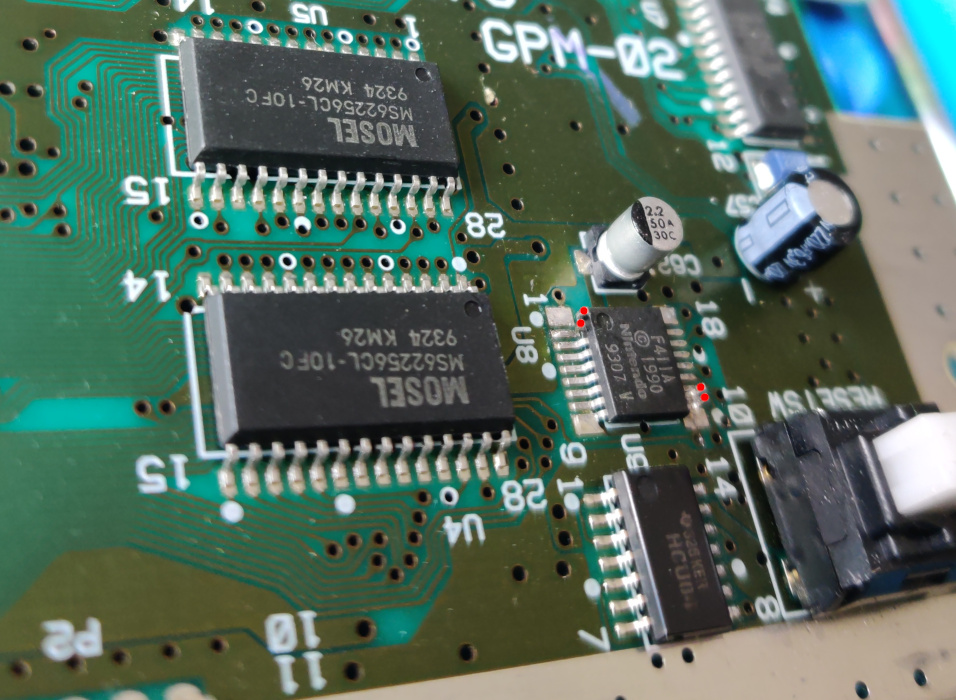
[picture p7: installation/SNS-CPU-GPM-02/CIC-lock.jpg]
  
- Lift pin 24 of S-PPU1 and pin 30 of S-PPU2. See the picture at the very end
  for additional reference.
- Disconnect the Master-Clock by removing R5, which is located near the reset
  switch. You can solder one leg back for easier mod-reverse. 
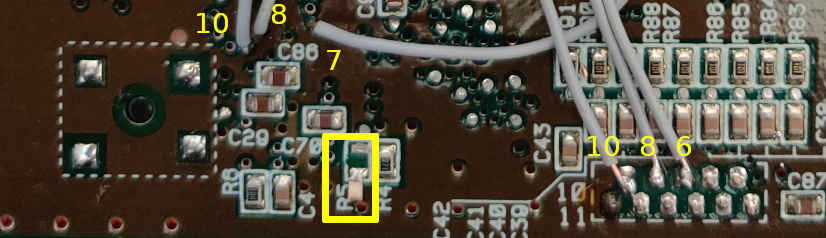
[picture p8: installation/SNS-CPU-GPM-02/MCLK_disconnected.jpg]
    
  (Disregard the wires and numbers for now, they are covered in later steps)
- Lift pin 8 of S-ENC.  
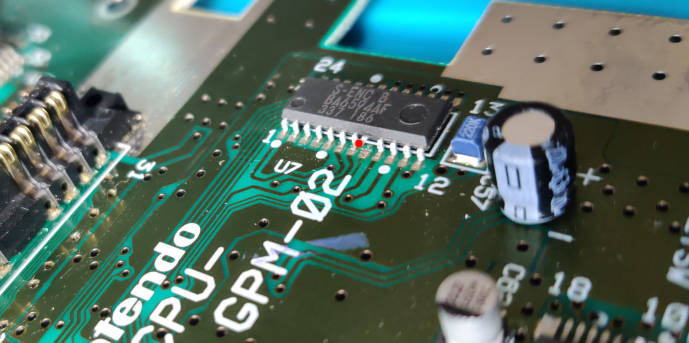
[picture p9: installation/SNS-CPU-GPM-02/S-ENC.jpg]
  
- Remove R25, which is located slightly below the MultiOut on the right, **if**
  you are going to use a RGB cable with sync on raw CSYNC (if you are using an
  RGB SCART cable, that is probably the case). Again, consider soldering one leg
  back for easier mod-reverse.  
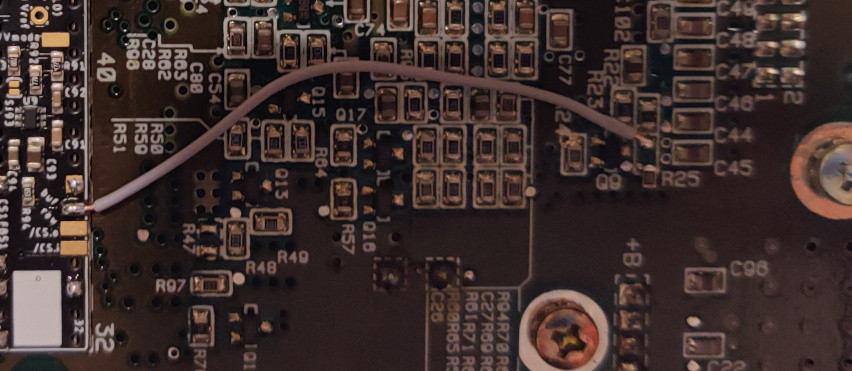
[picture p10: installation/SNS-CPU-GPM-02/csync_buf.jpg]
    
  (Note that the wire is attached in a later step)
- If you plan on moving R29, consider doing so now. Check the section on
  [Switching](#Switching) below for more details.

### Installation of PCB

- Place the PCB under the cartridge slot. Ensure that the pin markings match and
  pins 31 and 63 remain uncovered.
- Solder the PCB to the top of the slot pins so that there is a small gap
  between the PCB and the mainboard. If your PCB is thicker than 0.8 mm or you
  just wish to be on the safe side, insulate the bottom of the PCB with tape.
- Ensure all connections are well flowed. Especially pin 5 and 36 might be
  difficult or need more power due to the large heat capacity of the underlying
  GND plane.
- Connect _Rst.i_ and _/Rst.o_ (either pad) to CIC-lock footprint pin 8 and 10,
  respectively. There are vias to access them from the other side, see below.
  Ensure they are properly attached.
- Connect _Clk.CIC_ to CIC-lock footprint pin 7. There is via to access it from
  the other side, see below. Alternatively, close _SJ11_ (not preferable).
- Connect _Ctrl.port.6_, _Ctrl.port.8_, and _Ctrl.port.10_ to the respective
  controller panel connector pins, see below.  
    
  (CIC-lock vias and controller panel connectors. Disregard R5 from earlier.)
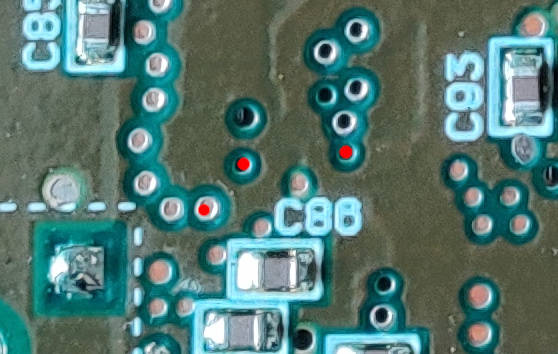
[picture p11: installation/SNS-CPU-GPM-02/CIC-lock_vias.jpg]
    
  (Exact location of the CIC-lock vias)
- Connect _Vmode_ to **both** S-PPU1 lifted pin 24 and S-PPU2 lifted pin 30.
  Running one wire around the mainboard to one pin and then connecting that pin
  to the other using a shorter wire is sufficient. See the picture at the very
  end for a possible routing solution.
- Connect _/CS.i_ (either pad since SMR20190813) to S-PPU2 pin 100. Make sure to
  leave enough room for the cartridge slot when reinstalled.
- Connect either _/CS.o raw_ pad to S-ENC lifted pin 8. See the picture at the
  very end for a possible routing solution.
- Connect _/CS.o buf_ to the left footprint of R25 as shown in the photo of
  the R25 removal above.
- Close _SJ93_ **only** if you plan on using an RGB cable that does **not** have
  a 470 ohm resistor to lower the voltage built in. If you leave the jumper open
  and use a cable without one, you could damage SCART equipment. Note however
  that since the higher voltage is the default for NTSC models, all cables
  designed for those should have one. If you want to be really sure your cable
  works as intended, check the voltage on your cable's CSYNC (SCART: pin 20): if
  it is approx. 450 mV, you are fine. If it is around 1.87 V, you want a
  different cable or to close the jumper.
  You also have to close this jumper if you opt for having _CS.o buf_ replace
  luma (pin 7 of MultiOut) or composite video (pin 9 of MultiOut), but likely
  you don't (also not covered here).
- Leave _SJ31_ open unless you wish to disable the dejitter function. If you
  are using a zero-lag upscaler like the OSSC with HDMI output in your setup,
  chances are you wish to keep the dejitter function enabled to fix lost signal
  or image issues you may encounter with this mainboard version. If however you
  are using a CRT, there is not really anything to gain from it.
  You may wish to connect a slide switch to allow toggling it on and off. See
  [top-level README](../../README.md) for more details.
- Close _SJ32_ since this mainboard version is not a 1-chip model.
- Close _SJ61_ since this mainboard version is not a 1-chip model.

### Switching

With the help of the modding PCB you can switch between PAL and NTSC color
carriers. I highly suggest using a shielded cable for connecting the color
carrier as described below.

- Cut the SCLN jumper in the middle and verify with a multimeter that the two
  pads are no longer connected.
- Connect one _/Vmode_ pad to the lower/left pad of SCLN (which itself is
  connected to S-ENC pin 19).  
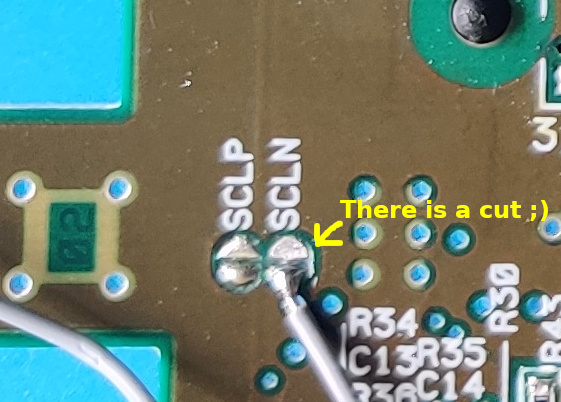
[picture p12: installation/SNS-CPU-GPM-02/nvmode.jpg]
  
- Modding boards **with** _R62_ footprint (since SMR20190813) only:
  - Move R29 (located above the reset switch) from the mainboard to the modding
  board _R62_ footprint.
  - Connect _CClk.o_ using a shielded cable to the **left** footprint of R29
    (former location). Note that this is different from models where another
    resistor is removed instead.
- Modding boards **without** _R62_ footprint only:
  - Lift S-PPU pin 3.
  - Connect _CClk.o_ using a shielded cable with the pad below S-PPU pin 3.
- Solder the GND shielding of the cable to _GND_ of the modding board. You may
  also connect the GND shielding on the other end to the right footprint of R29
  (former location), but this is not needed.  
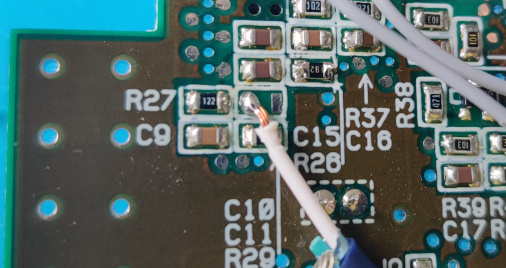
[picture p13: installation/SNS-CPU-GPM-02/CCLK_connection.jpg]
    
  (Picture shows the installation with R29 moved to the PCB and without GND
  shielding soldered to the other footprint)
- Modding boards **with** _SJ63_ (since SMR20200323):
  Close **exactly one** of _SJ63.1_ (marked with a dot) **or** _SJ63.2_. You may
  want to close _SJ63.2_ (no dot) to derive the color carrier signal from the
  dejittered clock. See [top-level README](../../README.md) for more details.

### Power LED

- Determine whether your replacement power LED has a common anode or cathode.
  If the middle pole must always be connected to ground for either color, it is
  the common cathode. If it is the other way round, it is the common anode.
- Note down which pole responds to which color.
- Close _SJ21_ *only* if you are using an LED with a common anode.
- Remove the original power LED. Desolder its legs to detach it and then pull it
  out. You may have to shorten and bend its legs quite a bit to get it out.
- Put the replacement power LED where the original was. Use a little bit of hot
  glue, if needed, but soldering the middle pole should give it enough hold, see
  the picture below.
- Connect the common pole to either Ground or Vcc of the power LED pads (common
  cathode or anode, respectively).  
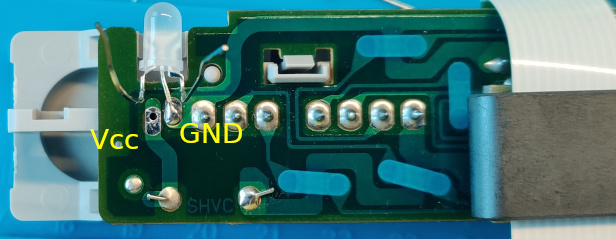
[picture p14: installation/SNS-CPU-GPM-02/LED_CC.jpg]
    
  (Picture shows a bi-color LED with a common cathode)
- Connect _LED.Re_ and _LED.Gr_ to the respective poles of the LED. You may wish
  to add resistors to lower its brightness. Note that once assembled again, the
  case only leaves a gap right below the controller panel connector. It might be
  helpful to solder colored or marked wires to the pads first and put the
  mainboard back into the case before connecting the LED.
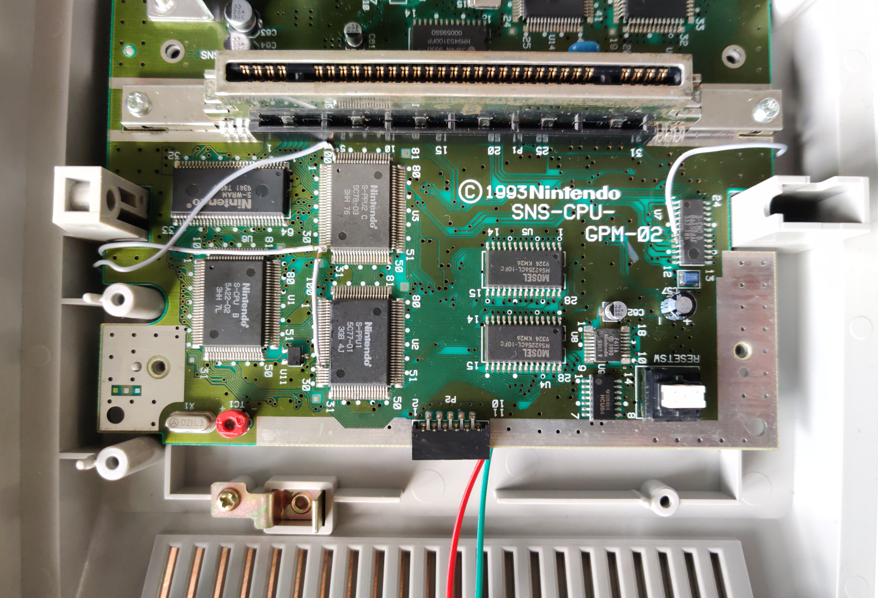
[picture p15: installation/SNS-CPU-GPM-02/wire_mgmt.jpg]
    
  (Picture shows the console partially assembled again but before connecting the
  LED or re-attaching the controller panel ribbon cable)

### Closing Remarks

- Leave _MClk.o_ unconnected since this mainboard version is not a 1-chip model.
- When experimenting with the uIGR button combinations, note that these may not
  work while you are in a game's region incompatibility screen.

**Have fun!!!**

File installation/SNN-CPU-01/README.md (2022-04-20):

## SNN-CPU-01

### Preparation

- remove original CIC-lock (or at least lift pins 1, 2, 10 and 11), which sits behind the cartridge port between S-RGB and S-MIX  
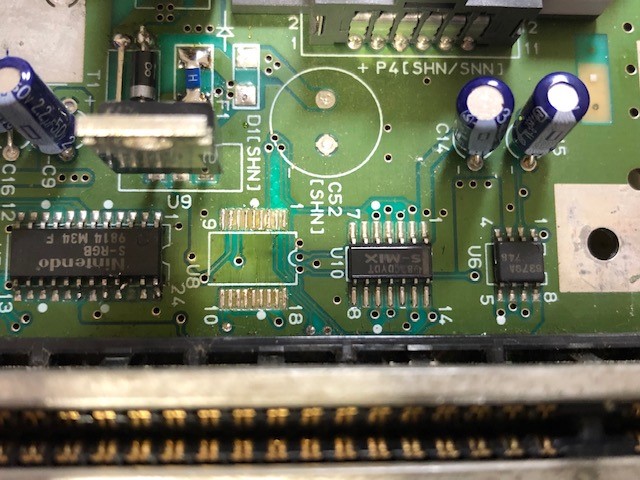
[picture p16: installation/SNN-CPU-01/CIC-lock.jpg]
  
  - if you remove the CIC-lock, you can also remove C9  
  - **Please note that the picture shows the US version and not the Jap. version of the console.** The US version does not have the large 1000uF capacitor C52 installed - the picture might be confusing. **Do not remove C52 if you have a Jap. console!**

- lift pin 111 of S-CPUN  
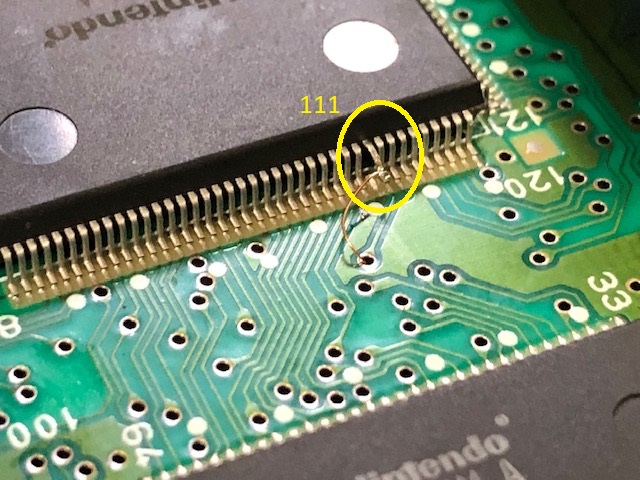
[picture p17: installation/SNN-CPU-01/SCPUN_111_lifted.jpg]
  

- remove X1  
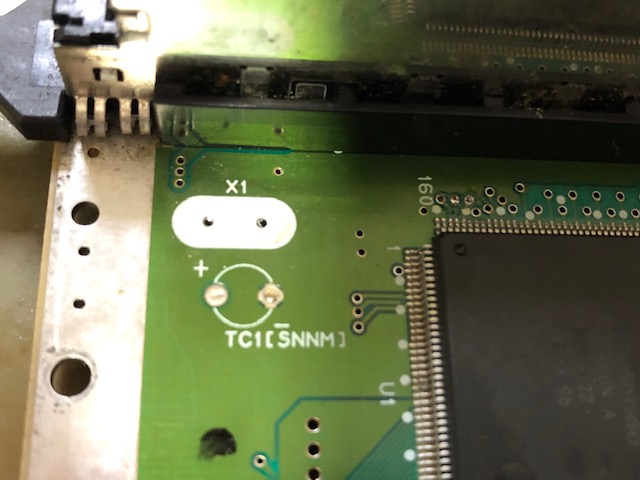
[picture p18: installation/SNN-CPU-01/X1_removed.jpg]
  

- lift pin 7 and pin 9 of S-RGB  
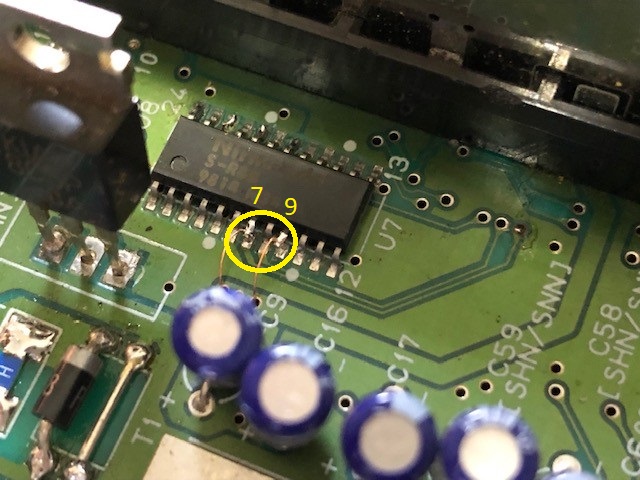
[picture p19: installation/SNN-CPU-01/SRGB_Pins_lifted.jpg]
  

### Installation of PCB

- Solder PCB in place under the cartridge slot. Be aware of the orientation (pin marking must match)
  
  - If you have large brightness correcting resistors installed, you may have to reinstall / reroute due to possible fitting collisions. I personally removed them (it's not mine SNES2) and replaced [R3](https://github.com/borti4938/SNES-AddOn-PCBs/tree/master/RGB%20Bypass#brightness-and-ghosting-issues) instead
  - solder the PCB to the top of the slot pins such that there is a small between SNES mainboard and modding board  
    (which is easy to do if you ordered the PCB in 0.8mm thickness)  
    (or simply insulate the PCB with some tape at the bottom)
  - make sure that all connections are well flowed
  - especially pin 5 and 36 might be difficult or need more power due to large heat capacity of the underlying GND plane
- connect _Rst.i_  to CIC-lock footprint pin 8; connect _/Rst.o_ (either pad) to CIC-lock footprint pin 10. There are two vias directly above the cartridge slot, which you can use  
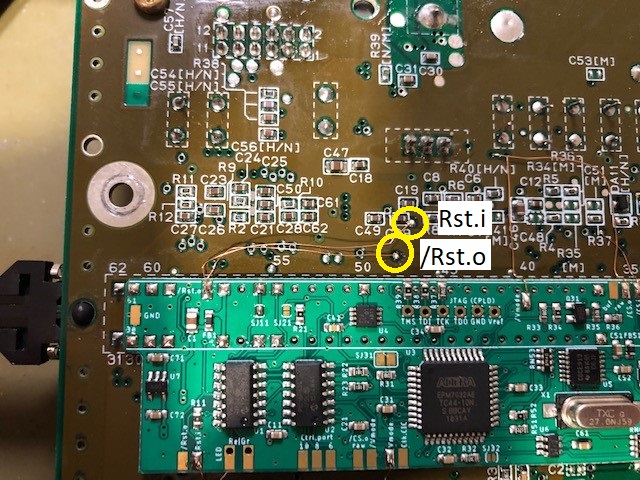
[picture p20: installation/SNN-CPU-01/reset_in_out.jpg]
    
- connect _Ctrl.port.10, 8_ and _6_ to controller one connector pin 3, 2 and 4 respectively  
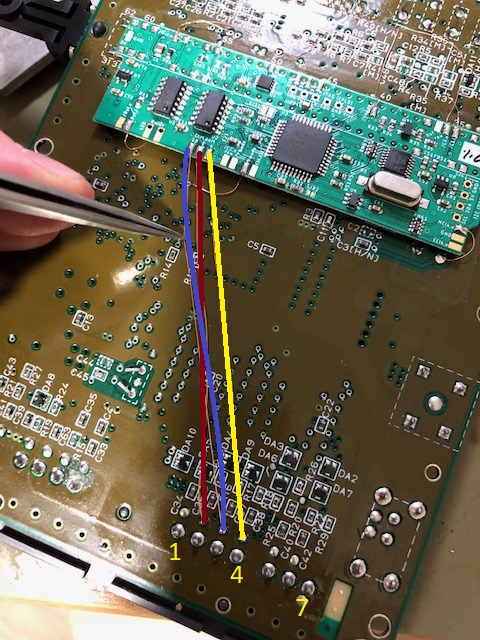
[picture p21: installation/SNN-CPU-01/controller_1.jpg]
     
  Note that the term _Ctrl.port_ on the silkscreen corresponds to the panel connector of the big model SNES 
- connect _Vmode_ to lifted pin 111 of the S-CPUN  
  Be aware of the housing if you route the wire around the housing
- either close _SJ11_ or connect _Clk.CIC_ to the via between C49 and C29  
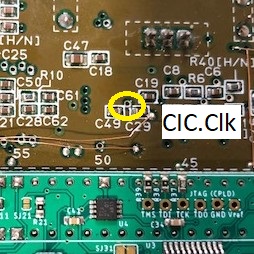
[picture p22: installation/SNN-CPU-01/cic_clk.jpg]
  
- connect _MCLK.o_ to X1 (the side, which goes to S-CPUN pin 9)  
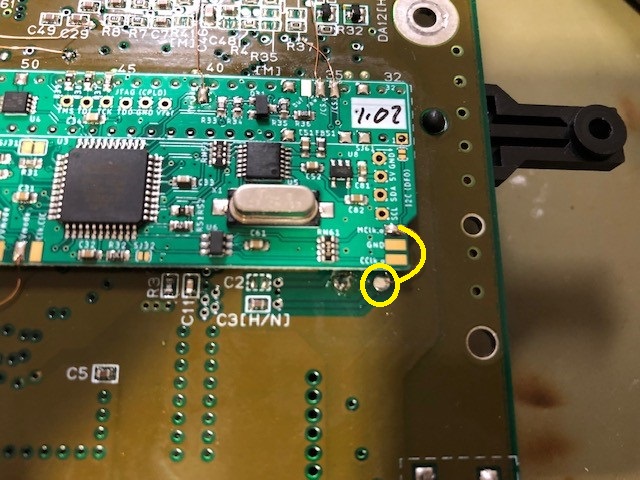
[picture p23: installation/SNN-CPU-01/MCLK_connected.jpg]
  
- connect _/CS.i_ to the pad of the lifted pin 7 of the S-RGB; connect one of the _/CS.o (raw)_ pads to the lifted pin 7 of the S-RGB  
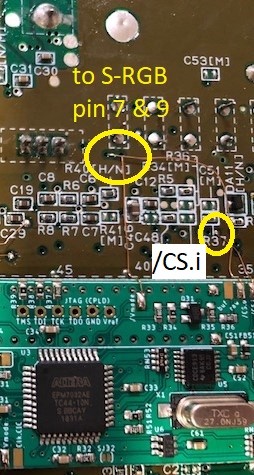
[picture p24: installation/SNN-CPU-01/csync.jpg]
  
- connect one of the _/Vmode_ pad to the lifted pin 9 of the S-RGB
- Connect _/CS.o (buf)_ to pin 3 of the MultiOut
  - leave _SJ93_ open if you have an attenuation resistor in your RGB cable for csync (which is usually the case in CSYNC cables)
  - (not documented) close _SJ93_ if you opt for having _CS.o (buf)_ replacing luma (pin 7 of MultiOut) or composite video (pin 9 of MultiOut)
- leave _SJ32_ and _SJ61_  open!

### Color Carrier

Color carrier is switched within the S-CPUN. There is no need to do anything in addition to the steps above.

### CSYNC and 'my' RGB bypass PCB

I do have an RGB bypass PCB in this repository. Just take a [look](../../../RGB Bypass/). If you use a version with CSYNC you can connect _/CS.o (raw)_ to this PCB to use it. However, you have to adopt some resistor values:

- R41: 4.7kohm
- R42:
  - 475ohm for 39ohm/75ohm compatible setup
  - 10.7kohm for TTL compatible setup

Please also take a look into the [readme](../../../RGB Bypass/README.md) and the [BOM](../../../RGB Bypass/BOM_SNES_RGB_bypass.xlsx) of that project.

### Have fun!!!

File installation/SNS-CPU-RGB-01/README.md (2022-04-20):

## SNS-CPU-RGB-01

### Preparation

- remove power LED
- remove original CIC-lock (or at least lift pins 1, 2, 10 and 11)  
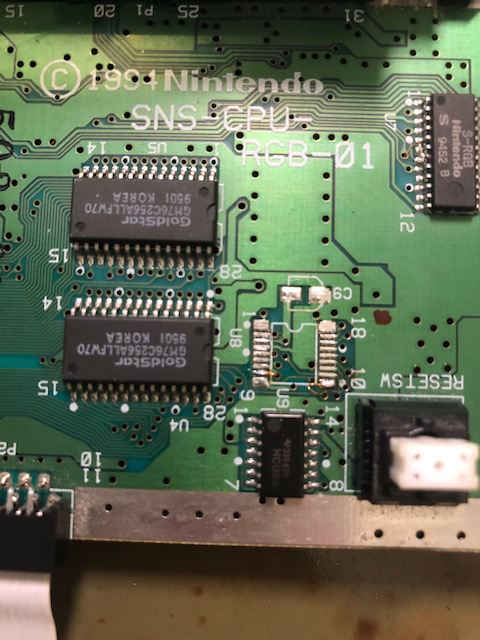
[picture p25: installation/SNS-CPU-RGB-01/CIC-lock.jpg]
  
  
- if you remove the CIC-lock, you can also remove C9
  
- lift pin 24 of S-PPU1 and pin 30 of S-PPU2  
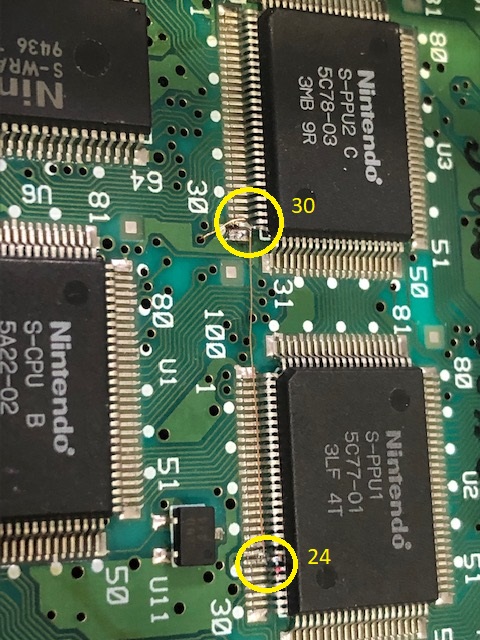
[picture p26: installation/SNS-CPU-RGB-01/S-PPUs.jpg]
  

- disconnect Master-Clock by remove R55  
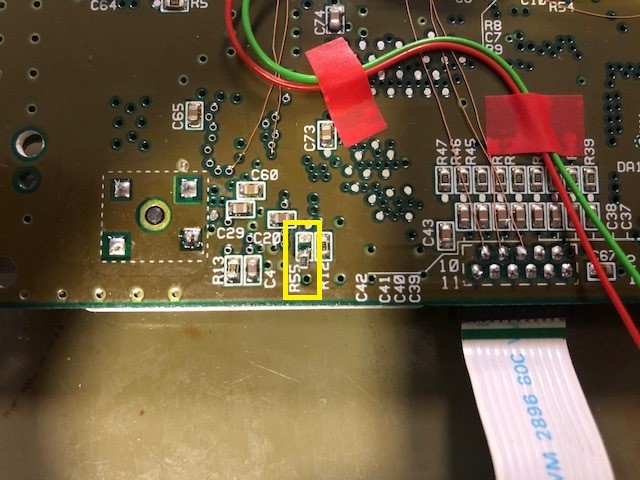
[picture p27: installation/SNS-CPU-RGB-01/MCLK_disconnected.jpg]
  

  (I soldered one leg of the resistor back to a footprint side to save it for possible mod-reverse)

- lift pin 7 of S-RGB  
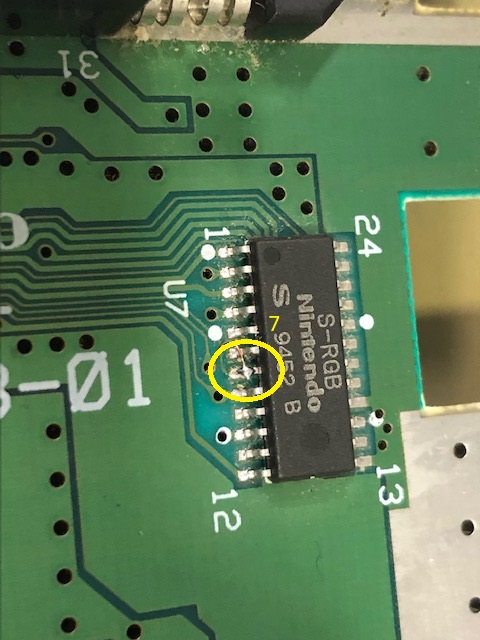
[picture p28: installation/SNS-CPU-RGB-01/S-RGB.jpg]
  

- remove R17 if you are going to use a RGB cable with sync on raw csync  
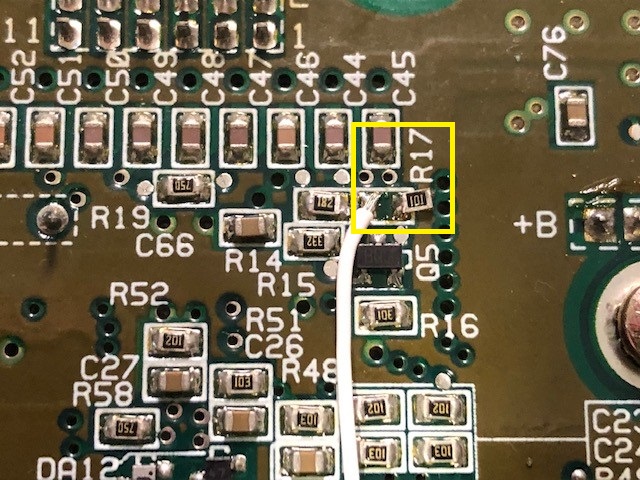
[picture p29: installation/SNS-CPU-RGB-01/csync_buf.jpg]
  

### Installation of PCB

- Solder PCB in place under the cartridge slot. Be aware of the orientation (pin marking must match)
  - solder the PCB to the top of the slot pins such that there is a small between SNES mainboard and modding board  
    (which is easy to do if you ordered the PCB in 0.8mm thickness)  
    (or simply insulate the PCB with some tape at the bottom)
  - make sure that all connections are well flowed
  - especially pin 5 and 36 might be difficult or need more power due to large heat capacity of the underlying GND plane
- put the replacement dual LED where the original was (use a small piece of hot glue if needed) and connect the common pole to either _Ground_ or _Vcc_ (common cathod or anode, respectively)  
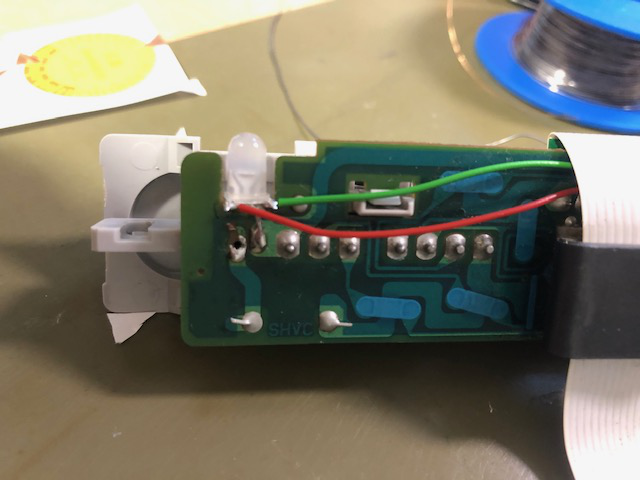
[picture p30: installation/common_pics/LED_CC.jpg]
    
  (Picture shows a bi-color LED with common cathode and cables for red and green attached)
  - it's a good idea to connect red and green to _LED.Re_ and _LED.Gr_ once everything is finished
  - be aware of the SNES housing (if you still use the original one of this SNES mainboard), where a stability bridge is placed at the SNES mainboard front with just a cut out under the front panel connector
- connect _Rst.i_ and _Rst.o_ (either pad) to CIC-lock footprint pin 8 and 10, respectively
- connect _Ctrl.port.10-6_ to front panel connector pins 10 - 6
- connect _Vmode_ to lifted pins 24 and 30 of the S-PPUs
- connect _/CS.i_ to pin 100 of S-PPU2  
  (since SMR20190813 you have a second _/CS.i_ pad which you can use)
- connect one of the _/CS.o (raw)_ pads to the lifted pin 7 of the S-RGB
- connect _/CS.o (buf)_ to left footprint of R17 as shown in picture of R17 removal above
- either close _SJ11_ or connect _Clk.CIC_ to CIC-lock footprint pin 7
  - leave _SJ93_ open if you have an attenuation resistor in your RGB cable for csync (which is usually the case in CSYNC cables)
  - (not documented on preparation part) close _SJ93_ if you opt for having _CS.o (buf)_ replacing luma (pin 7 of MultiOut) or composite video (pin 9 of MultiOut)
- close _SJ32_ and _SJ61_  
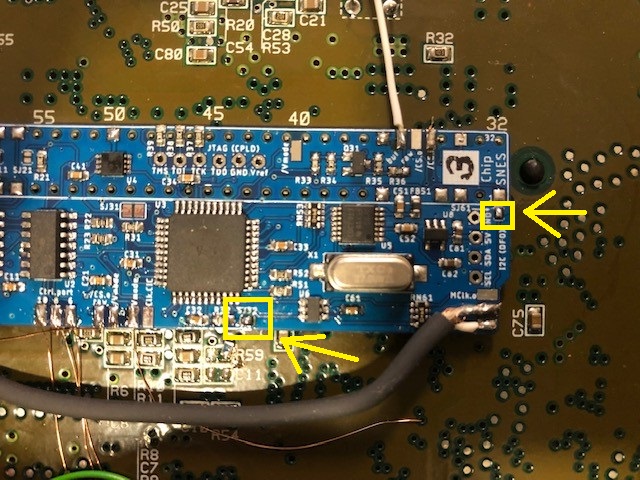
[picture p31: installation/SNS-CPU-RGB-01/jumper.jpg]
  

### Color Carrier

#### Remove 

Often it is suggested to remove the color carrier completely as this type of SNES mainboard. It interferes to the RGB output. To do so

- either lift pin 3 of the S-PPU2...
- or remove R59 from SNES mainboard (a 470ohm resistor)  
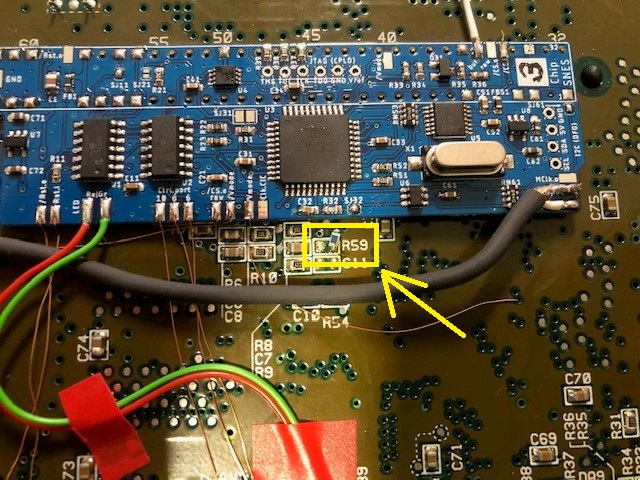
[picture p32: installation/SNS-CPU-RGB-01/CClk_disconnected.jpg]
    
  (note that in the picture a 0ohm jumper is placed as I exchanged it with R4)

### Switching

With the help of the modding PCB you can switch between PAL and NTSC color carrier. I highly suggest you to use a shielded cable for connecting the color carrier.

- cut SCLN jumper in the middle and connect one _/Vmode_ pad as shown  
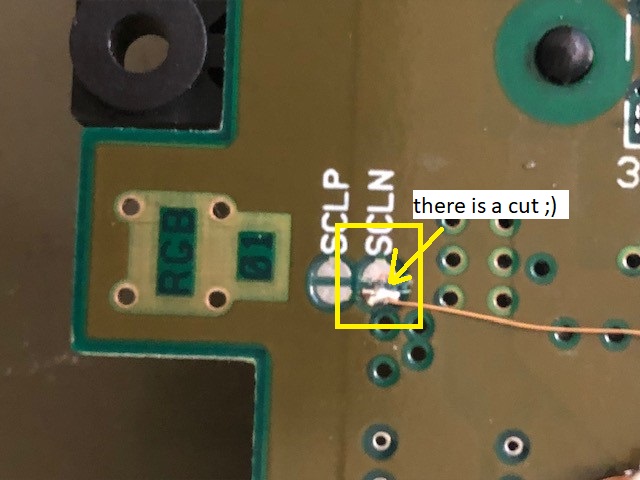
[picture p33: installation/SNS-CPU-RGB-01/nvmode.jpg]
  
- remove R4 and R59, which are a 0ohm jumper and a 470ohm resistor. You need the 470ohm resistor of R59
- connect the _CClk.o_ pad over the 470ohm resistor (or any replacement resistor) to the right pad of R4 footprint as shown  
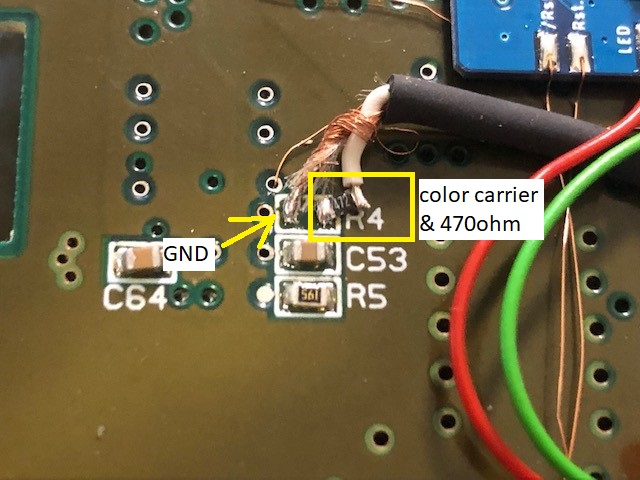
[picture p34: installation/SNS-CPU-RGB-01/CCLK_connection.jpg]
    
  **Note:** Since modding board version SMR20190813 you can place the 470ohm resistor on the modding board. The footprint it labeled _R62_.
- solder the GND shielding to _GND_ pad of the modding board
  (I also soldered the GND shielding to the left pin of R4, which is not needed at all (it's just the connection between R4 and R59))

### Have fun!!!

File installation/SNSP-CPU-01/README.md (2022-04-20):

## SNSP-CPU-01 and SNSP-CPU-02

### Preparation

- remove power LED
- remove original CIC-lock (or at least lift pins 1, 2, 10 and 11)  
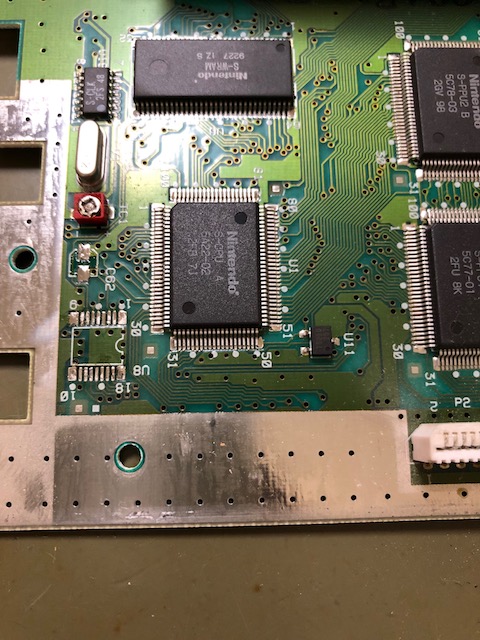
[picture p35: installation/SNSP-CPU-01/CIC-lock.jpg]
  
  
- if you remove the CIC-lock, you can also remove C62
  
- lift pin 24 of S-PPU1 and pin 30 of S-PPU2  
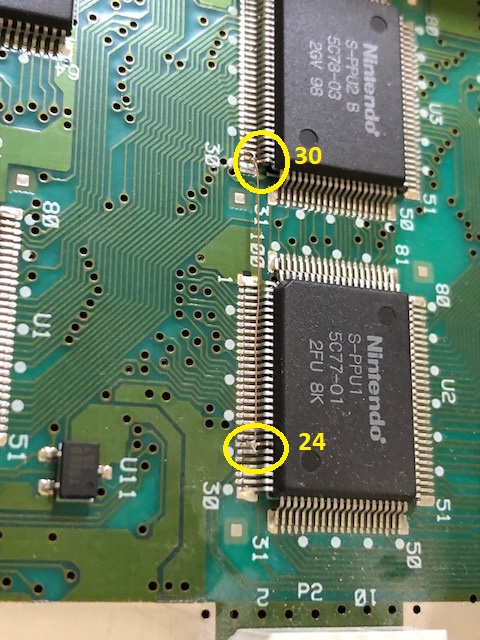
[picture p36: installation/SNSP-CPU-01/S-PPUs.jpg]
  

- disconnect Master-Clock by remove R73, which is just a jumper  
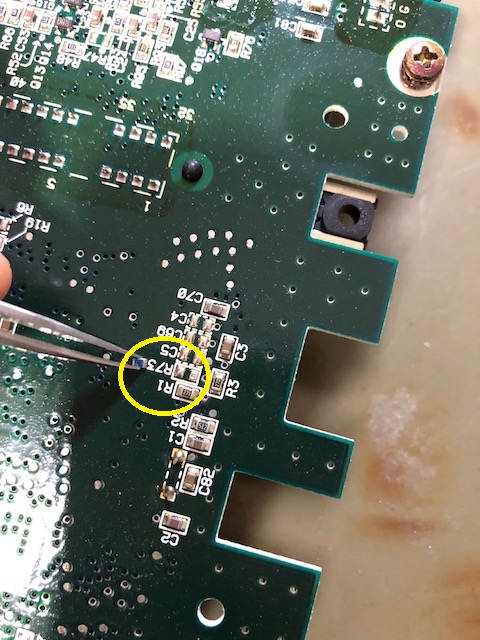
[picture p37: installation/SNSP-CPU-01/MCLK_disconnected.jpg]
  

  (I soldered one leg of the resistor back to a footprint side to save it for possible mod-reverse)

- lift pin 8 of S-ENC   
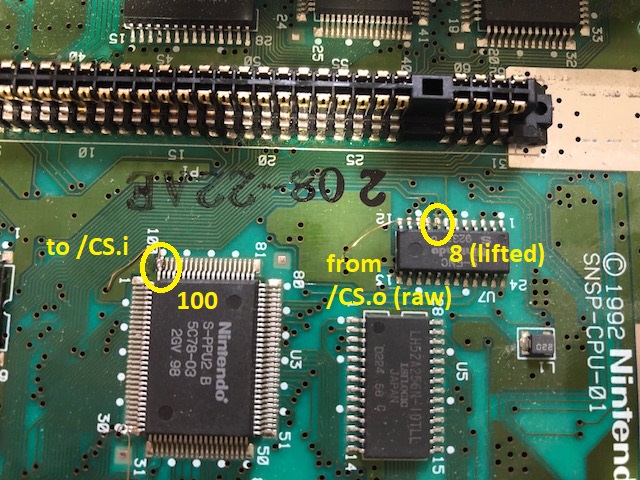
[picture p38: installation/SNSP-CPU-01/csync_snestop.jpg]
  

### Installation of PCB

- Solder PCB in place under the cartridge slot. Be aware of the orientation (pin marking must match)
  - solder the PCB to the top of the slot pins such that there is a small between SNES mainboard and modding board  
    (which is easy to do if you ordered the PCB in 0.8mm thickness)  
    (or simply insulate the PCB with some tape at the bottom)
  - make sure that all connections are well flowed
  - especially pin 5 and 36 might be difficult or need more power due to large heat capacity of the underlying GND plane
- put the replacement dual LED where the original was (use a small piece of hot glue if needed) and connect the common pole to either _Ground_ or _Vcc_ (common cathod or anode, respectively)  
    
  (Picture shows a bi-color LED with common cathode and cables for red and green attached)
  - it's a good idea to connect red and green to _LED.Re_ and _LED.Gr_ once everything is finished
  - be aware of the SNES housing (if you still use the original one of this SNES mainboard), where a stability bridge is placed at the SNES mainboard front with just a cut out under the front panel connector
- connect _Rst.i_ and _Rst.o_ (either pad) to CIC-lock footprint pin 8 and 10, respectively  
  on this mainboard version, it's a good idea to connect _Rst.i_ and _Rst.o_ to the reset button and a test-point as shown
- connect _Ctrl.port.10-6_ to front panel connector pins 10 - 6
- connect _Vmode_ to lifted pins 24 and 30 of the S-PPUs
- connect _/CS.i_ to pin 100 of S-PPU2 (see picture above)  
  (since SMR20190813 you have a second _/CS.i_ pad which you can use)
- connect one of the _/CS.o (raw)_ pads to the lifted pin 8 of the S-ENC (see picture above)
- either close _SJ11_ or connect _Clk.CIC_ to CIC-lock footprint pin 7 or right pad of C4 as shown  
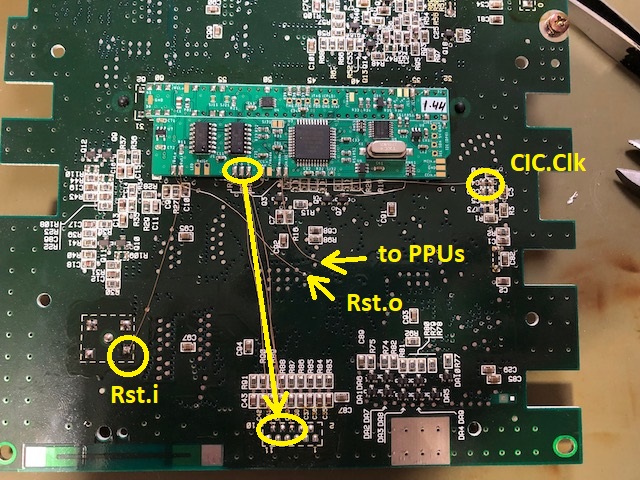
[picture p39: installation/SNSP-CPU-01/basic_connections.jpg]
  
- close _SJ32_ and _SJ61_  
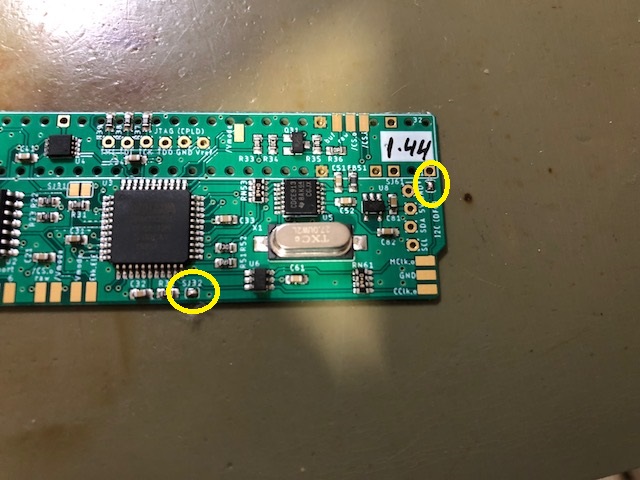
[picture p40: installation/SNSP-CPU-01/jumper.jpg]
  

### CSYNC at the MultiOut

Personally, I prefer having csync at pin 7 of the MultiOut. By default, this is the luma-output. However, S-Video is hardly used in PAL region.

- remove R25 from the SNES mainboard  
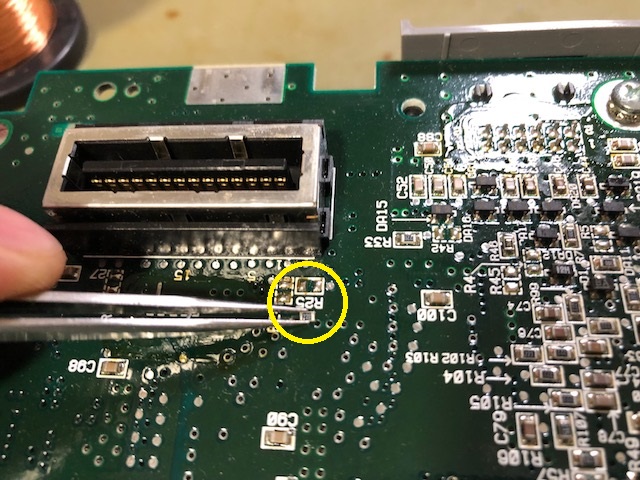
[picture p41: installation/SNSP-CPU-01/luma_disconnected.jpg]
  
- Connect _/CS.o (buf)_ to the MultiOut pin 7  
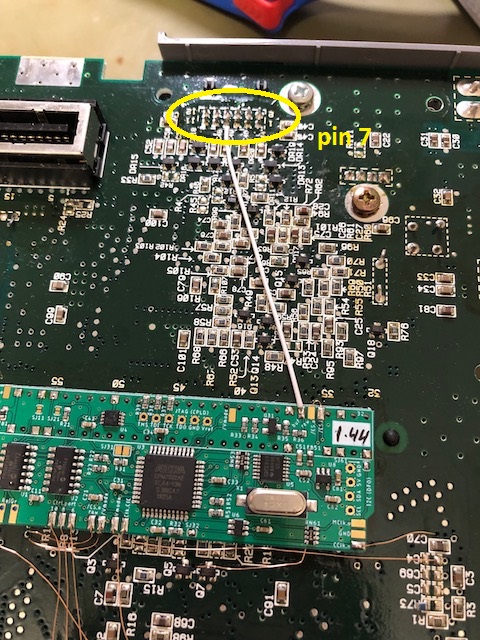
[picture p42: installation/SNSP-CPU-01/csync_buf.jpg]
  
- close _SJ93_ for proper signal attenuation

### Switching Color Carrier

With the help of the modding PCB you can switch between PAL and NTSC color carrier. 

- lift pin 19 of the S-ENC
- connect either  _/Vmode_ pad to the lifted pin as shown  
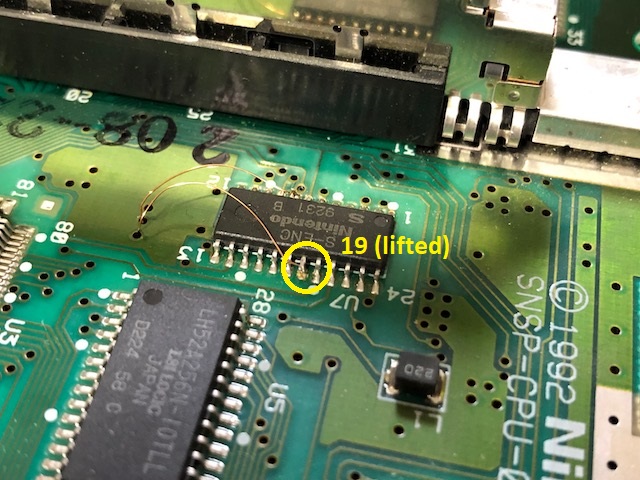
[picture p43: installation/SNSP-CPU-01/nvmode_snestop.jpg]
  
- lift pin 5 of the S-CLK
- connect the _CClk.o_ pad to the pad of the lifted pin  
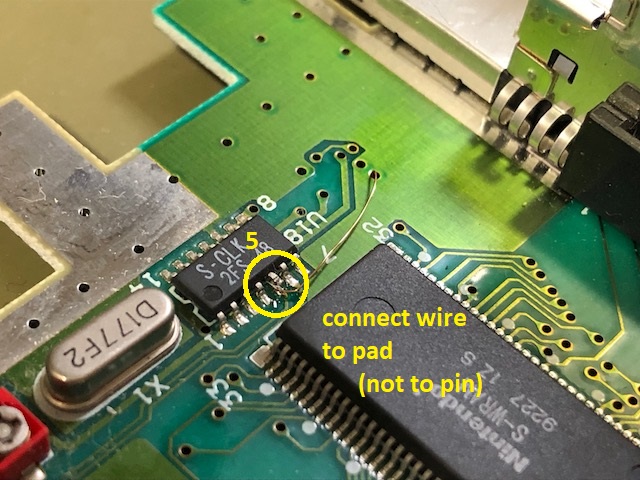
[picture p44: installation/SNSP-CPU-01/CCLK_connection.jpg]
  
- since SMR20190813 you have to short R62

### C59 Fix on SNSP-CPU-01 Mainboard

SNSP-CPU-01 mainboards have a 'normal' polarized electrolyte capacitor at C59 (10uF/50V). However, this is a design mistake. I highly recommend to replace it with a non-polatized bipolar electrolyte capacitor (10uF/25V)!

### Use of NTSC Game Pads

Earlier PAL models were equipped with special game pad connector panels, which does not allow the user to use NTSC game pads. There are four diodes placed inside the traces of pad 1 and 2, which need PAL game pads to have two additional resistors inside. However, there is an easy fix to make it universal for all game pads. 

- Just short all diodes on the panel  
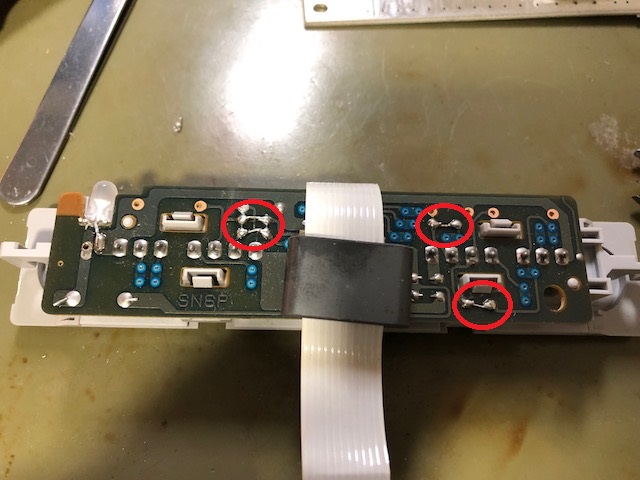
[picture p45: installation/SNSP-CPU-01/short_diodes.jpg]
  

### Have fun!!!

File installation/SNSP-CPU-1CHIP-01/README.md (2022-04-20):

## SNSP-CPU-1CHIP-01 and SNSP-CPU-1CHIP-02

Note that this installation guide shows pictures with a prototype version of the modding PCB where some pads are placed differently and others are simply not present compared to the final version.

### Preparation

- remove power LED
- remove original CIC-lock (or at least lift pins 1, 2, 10 and 11)  
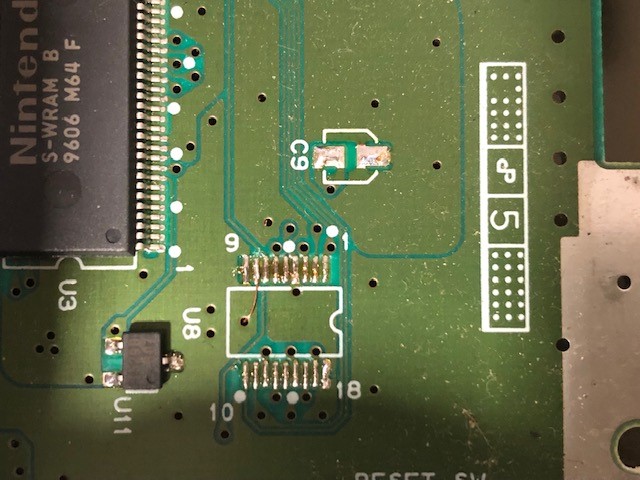
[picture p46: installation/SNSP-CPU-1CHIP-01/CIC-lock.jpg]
  
  - if you remove the CIC-lock, you can also remove C9

- lift pin 111 of S-CPUN  
  

- remove X1  
  

- lift pin 7 and pin 9 of S-RGB  
  

### Installation of PCB

- Solder PCB in place under the cartridge slot. Be aware of the orientation (pin marking must match)
  - solder the PCB to the top of the slot pins such that there is a small between SNES mainboard and modding board  
    (which is easy to do if you ordered the PCB in 0.8mm thickness)  
    (or simply insulate the PCB with some tape at the bottom)
  - make sure that all connections are well flowed
  - especially pin 5 and 36 might be difficult or need more power due to large heat capacity of the underlying GND plane
- put the replacement dual LED where the original was (use a small piece of hot glue if needed) and connect the common pole to either _Ground_ or _Vcc_ (common cathod or anode, respectively)  
    
  (Picture shows a bi-color LED with common cathode and cables for red and green attached)
  - it's a good idea to connect red and green to _LED.Re_ and _LED.Gr_ once everything is finished
  - be aware of the SNES housing (if you still use the original one of this SNES mainboard), where a stability bridge is placed at the SNES mainboard front with just a cut out under the front panel connector
- connect _Rst.i_  to CIC-lock footprint pin 8
- connect _Rst.o_ (either pad) to S-APU pin 100 / CIC-lock footprint pin 10. There is a via directly in front of the S-APU pin 100  
    
  
- connect _Ctrl.port.10-6_ to front panel connector pins 10 - 6
- connect _Vmode_ to lifted pin 111 of the S-CPUN
- either close _SJ11_ or connect _Clk.CIC_ to the footprint of C74 (left pad)  
  
- connect _MCLK.o_ to X1 (the side, which goes to S-CPUN pin 9)  
  
- connect _/CS.i_ to the pad of the lifted pin 7 of the S-RGB  
  (there is a via next to it - just follow the trace)   
  (from bottom the silk screen mark of C6 is next to the via; see picture below (section csync to multiout))
- connect one of the _/CS.o (raw)_ pads to the lifted pin 7 of the S-RGB
- connect _/Vmode_ to the lifted pin 9 of the S-RGB
- leave _SJ32_ and _SJ61_  open!

### Color Carrier

Color carrier is switched within the S-CPUN. There is no need to do anything in addition to the steps above.

However, if you wish to use the color carrier derived from the continuous clock, you have to perform the following steps:

- move R4 from SNES mainboard to _R62_ on the modding board
- connect pad _CClk.o_ with right pad of R4 footprint
- Close SJ63.2 jumper



### Buffered CSYNC to the MultiOut

Other than the NTSC variant of the SNES, the PAL version has 12V at the MultiOut pin 3 instead of CSYNC. However, it's not a big deal to change that.

- remove R28 and optionally D1
- Connect the upper pin of _/CS.o (buf)_ to the top footprint pad of R28 (or to the MultiOut pin 3)  
  - leave _SJ93_ open if you have an attenuation resistor in your RGB cable for csync (which is usually the case in CSYNC cables)   
  

You can also connect the buffered output to pin 7 (for use with _sync-on-luma_ cables). Just remove R19 instead of R28. Same if you want to wire the buffered output to pin 9 (for use with _sync-on-composite video_ cables). Just remove R18 instead of R28.  
In both cases, close _SJ93_ for proper signal attenuation.

### CSYNC and 'my' RGB bypass PCB

I do have an RGB bypass PCB in this repository. Just take a [look](../../../RGB Bypass/). If you use a version with CSYNC you can connect _/CS.o (raw)_ to this PCB to use it. However, you have to adopt some resistor values:

- R41: 4.7kohm
- R42:
  - 475ohm for 39ohm/75ohm compatible setup
  - 10.7kohm for TTL compatible setup

Please also take a look into the [readme](../../../RGB Bypass/README.md) and the [BOM](../../../RGB Bypass/BOM_SNES_RGB_bypass.xlsx) of that project.

### Have fun!!!

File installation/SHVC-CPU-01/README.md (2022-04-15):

## SNSP-CPU-01 and SNSP-CPU-02

### Preparation

- remove power LED
- remove original CIC-lock (or at least lift pins 1, 2, 10 and 11)  
  
  
- if you remove the CIC-lock, you can also remove C62
  
- lift pin 24 of S-PPU1 and pin 30 of S-PPU2  
  

- disconnect Master-Clock by removing R6  
  

  (I soldered one leg of the resistor back to a footprint side to save it for possible mod-reverse)

- lift pin 8 of S-ENC   
  

### Installation of PCB

- Solder PCB in place under the cartridge slot. Be aware of the orientation (pin marking must match)
  - solder the PCB to the top of the slot pins such that there is a small gap between SNES mainboard and modding board  
    (which is easy to do if you ordered the PCB in 0.8mm thickness)  
    (or simply insulate the PCB with some tape at the bottom)
  - make sure that all connections are well flowed
  - especially pin 5 and 36 might be difficult or need more power due to large heat capacity of the underlying GND plane
- put the replacement dual LED where the original was (use a small piece of hot glue if needed) and connect the common pole to either _Ground_ or _Vcc_ (common cathod or anode, respectively)  
    
  (Picture shows a bi-color LED with common cathode and cables for red and green attached)
  - it's a good idea to connect red and green to _LED.Re_ and _LED.Gr_ once everything is finished
  - be aware of the SNES housing (if you still use the original one of this SNES mainboard), where a stability bridge is placed at the SNES mainboard front with just a cut out under the front panel connector
- connect _Rst.i_ and _Rst.o_ (either pad) to CIC-lock footprint pin 8 and 10, respectively  
  on this mainboard version, it's a good idea to connect _Rst.i_ and _Rst.o_ to the test-points as shown below
- connect _Ctrl.port.10-6_ to front panel connector pins 10 - 6
- connect _Vmode_ to lifted pins 24 and 30 of the S-PPUs
- connect _/CS.i_ to pin 100 of S-PPU2 (see picture above)  
  (since SMR20190813 you have a second _/CS.i_ pad which you can use)
- connect one of the _/CS.o (raw)_ pads to the lifted pin 8 of the S-ENC (see picture above)
- either close _SJ11_ or connect _Clk.CIC_ to CIC-lock footprint pin 7 or to the test point close to the reset button   
    
    
- close _SJ32_ and _SJ61_  
  

### CSYNC at the MultiOut

#### Pin 3 (CSYNC Pin)
In NTSC regions it is common to use cables with raw CSYNC, which is pin 3 on the MultiOut. Here is how to connect CSYNC buf to pin 3.

- remove R25 from the SNES mainboard  
- Connect _/CS.o (buf)_ to the MultiOut pin 3 
- Leave SJ93 untouched as virtually all cables using pin 3 CSYNC sync have attenuation resistors inside

#### Pin 7 (Luma Pin)
Personally, I prefer having csync at pin 7 of the MultiOut. By default, this is the luma-output. However, S-Video is hardly used in PAL region.

- remove R42 from the SNES mainboard  
- Connect _/CS.o (buf)_ to the MultiOut pin 7  
- Close _SJ93_ for proper sync attenuation

  
(picture shows pin 7 method)

### Switching Color Carrier (optional)

With the help of the modding PCB you can switch between PAL and NTSC color carrier. 

- lift pin 19 of the S-ENC
- connect either  _/Vmode_ pad to the lifted pin as shown  
  
- since SMR20190813:
  - move R29 from SNES mainboard to modding board footprint R62
  - Connect _CClk.o_ with the R29 footprint top pad
  - Close on of _SJ63_ jumper
- earlier modding boards:
  - lift pin 3 of the S-PPU2
  - short footprint R62 on the modding board
  - Connect CClk.o to C69 on the SNES mainboard (right below the modding board / CPLD U3) top pad



### Have fun!!!

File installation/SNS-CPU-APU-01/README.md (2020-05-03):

## SNS-CPU-APU-01

This SNES mainboard version is very similar to the [SNS-CPU-RGB-01](../SNS-CPU-RGB-01/), which is one of the predecessor model. Consequentially, installation is very similar. Except for the optional Color Carrier Switching part, the reader is referred to the installation manual on a [SNS-CPU-RGB-01](../SNS-CPU-RGB-01/) mainboard.

### Color Carrier

#### Remove 

Often it is suggested to remove the color carrier completely as this type of SNES mainboard. It interferes to the RGB output. To do so

- either lift pin 3 of the S-PPU2...
- or remove R59 from SNES mainboard (a 470ohm resistor)  
    
  (note that this resistor can be used at R4 in the following)

### Switching

With the help of the modding PCB you can switch between PAL and NTSC color carrier. I highly suggest you to use a shielded cable for connecting the color carrier.

- cut SCLN jumper in the middle and connect one _/Vmode_ pad as shown  
  
- remove R4 and R59, which are a 0ohm jumper and a 470ohm resistor. You need the 470ohm resistor of R59
- connect the _CClk.o_ pad over the 470ohm resistor (or any replacement resistor) to the right pad of R4 footprint as shown  
    
  **Note:** Since modding board version SMR20190813 you can place the 470ohm resistor on the modding board. The footprint it labeled _R62_.
- solder the GND shielding to _GND_ pad of the modding board
  (I also soldered the GND shielding to the left pin of R4, which is not needed at all (it's just the connection between R4 and R59))

### Overview

Once you are done, the installation may look like that.  


### Have fun!!!

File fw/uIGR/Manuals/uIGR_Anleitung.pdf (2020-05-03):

# Super Nintendo – InGameReset Kurzanleitung

L + R + Select + Y; L + R + Select + A; L + R + Select + B

Region 50Hz (PAL) (LED Grün)

Region 60Hz (NTSC) (LED Rot)

Region des Moduls (LED Gelb)

Umschalten zum Modus des SCIC (für kommendes Feature des sd2snes)

L + R + Select + Pfeil nach links oder rechts

### Normaler Reset der Konsole

### L + R + Select + Start


### Doppel-Reset der Konsole (Zurück ins sd2snes-Hauptmenü)

### L + R + Select + X


### Regionentimeout ein-/ausschalten

- Regionentimeout: Bei Start der Konsole, nach Reset und nach dem Long-Reset wird 9s die Region des Moduls genommen, danach auf den zuletzt eingestellten Modus gewechselt
- LED bestätigt bei Einschalten mit: aus -> rot -> gelb -> grün -> aus -> "LED Farbe vom aktuellen Modus"
- LED bestätigt bei Ausschalten mit: aus -> grün -> gelb -> rot -> aus -> "LED Farbe vom aktuellen Modus"

### L + R + Select + Pfeil nach oben


### Regionenpatch ein-/ausschalten

- Regionenpatch, auch $213f-D4-Patch: verhindert, dass „This Gamepack is not designed for […]“ angezeigt wird, wenn das Register $213f vom eingestecktem Modul gelesen wird
- LED bestätigt mit bei Einschalten: aus -> grün -> aus -> grün -> aus -> "LED Farbe vom aktuellen Modus" LED bestätigt mit bei Ausschalten: aus -> rot -> aus -> rot -> aus -> "LED Farbe vom aktuellen Modus"

### L + R + Select + Pfeil nach unten


### Sperre (Typ 1) ein-/ausschalten

- Sperre (Typ 1): Alle anderen Kombinationen werden gesperrt. Entsperren ist nur durch die gleiche Tastenkombi möglich. Die Sperre (Typ 1) wird gespeichert und ist auch nach Neustart oder Reset der Konsole vorhanden.
- LED bestätigt bei Einschalten mit schnellem Auf- und Abblinken von rot
- LED bestätigt bei Ausschalten mit schnellem Auf- und Abblinken von grün

### Pfeil nach links + Pfeil nach oben + L + R + X + A


### Sperre (Typ 2) einschalten

- Sperre (Typ 2):Alle Tastenkombinationen werden gesperrt. Ein Wechsel des Modis ist damit nur noch über den SuperCIC möglich (Resetknopf oder sd2snes-Menü). Entsperren ist nur durch Reset (über Resetknopf, nicht durch sd2snes-IGRs) oder durch Aus- und wieder Einschalten der Konsole möglich
- LED bestätigt bei Einschalten mit schnellem Auf- und Abblinken von rot

### Pfeil nach unten + Pfeil nach links + L + R + A+ B


(Die Sperrkombinationen sind nur vorhanden, wenn das entsprechende *with_lock.hex-file auf den PIC-Microcontroller geflasht wurde)

### Support von drahtlosen Controller Retro-Bit ein-/ausschalten

- Der drahtlose Controller von Retro-Bit hat eine große Verzögerung beim Umschalten der Daten. Also muss der PIC im allgemeinen ‚langsamer‘ auslesen. Bei Spielen, die nicht das AJR (Auto Joypad Read) Feature des SNES nutzen, könnte es zu Problemen kommen, wenn der PIC immer so langsam ausliest (muss nicht). Deswegen ist der Support von diesen Controllern optional.
- LED bestätigt bei Einschalten mit: aus -> grün -> gelb -> grün -> aus -> "LED Farbe vom aktuellen Modus"
- LED bestätigt bei Ausschalten mit: aus -> rot -> gelb -> rot -> aus -> "LED Farbe vom aktuellen Modus"

### L + R + Start + A+ B + Y + X


Defaultwerte: 60Hz, Regiontimeout: aus, Regionpatch: an, Sperren: aus, Support von WRBC: aus

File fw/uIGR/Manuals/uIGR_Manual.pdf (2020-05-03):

# Super Nintendo – InGameReset Functionalities

L + R + Select + Y; L + R + Select + A; L + R + Select + B

Force region 50Hz (PAL) (LED green)

Force region 60Hz (NTSC) (LED red)

Force region of cartridge (LED yellow)

Change to SCICs forced region (e.g. for pairmode with sd2snes)

L + R + Select + D-Pad left OR right

### Simple reset of console

### L + R + Select + Start


### Double reset (change to main menu of sd2snes)

### L + R + Select + X


### Toggle region timeout on and off

- Regionen timeout:force cartridge region after consoles start-up, reset and double reset for approximately 9s afterwards change to forced region
- LED confirms with off -> red -> yellow -> green -> off -> "LED normal" on switching on
- LED confirms with off -> green -> yellow -> red -> off -> "LED normal" on switching off

### L + R + Select + D-Pad up


### Toggle region patching on and off

- Region patching, also $213f-D4-Patch:suppresses cartridge error "This Gamepack is not designed for […]" after reading register $213f by overriding bit 4 (region bit)
- LED confirms with off -> green -> off -> green -> off -> "LED normal" on switching on
- LED confirms with off -> red -> off -> red -> off -> "LED normal" on switching off

### L + R + Select + D-Pad down


### Toggle lock (type 1) on and off

- Lock (type 1): locks all combinations except this one. Lock can be removed using the same combination again. This lock state is stored during powering off and on the SNES.
- LED confirms with fast flashing red on switching lock on
- LED confirms with fast flashing green on switching the lock off

### D-Pad left + D-Pad up + L + R + X + A


### Set lock (type 2)

- Lock (type 2): locks all combinations. The lock can only be unset using a reset or switching off and on the console. Reset using the sd2snes’ IGRs is not supported; one has to use the reset button.
- LED confirms with fast flashing red

### D-Pad down + D-Pad left + L + R + A+ B


(These locking combinations are only available if you have flashed the right *.hex-file to the PIC-microcontroller)

### Toggle support of wireless controller by Retro-Bit on and off

- These controllers have a long delay for switching the serial date. Hence the PIC microcontroller has to read slower than normal. Some games, which do not use the AJR (Auto Joypad Read) feature of the SNES, might cause problems if the PIC reads that slow (or not). Thus the support is optional.
- LED confirms with off -> green -> yellow -> green -> off -> "LED normal" on switching on
- LED confirms with off -> red -> yellow -> red -> off -> "LED normal" on switching off

### L + R + Start + A+ B + Y + X


### Defaults: 60Hz, Regiontimeout: off, Regionpatch: on, Locks: off, Support of WRBC: off

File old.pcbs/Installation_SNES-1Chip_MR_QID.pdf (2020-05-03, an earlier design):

Preparation of the SNES:
- Remove X1
- Remove CIC (or lift at least pin 1, 2, 10 and 11)
- Lift pin 111 at the S-‐CPUN
- Remove LED from the controller panel (normal SNES only)
- Optional: lift pin 9 at the S-‐RGB
(in NTSC-‐systems, there is a jumper on bottom side of the mainboard, which can be cutted)

to CIC pad 10
or S-‐APU pin 100

to S-‐RGB
lifted pin 9


10
11

2
1
Port of the ribbon cable
(normal SNES)

to S-‐CPUN
lifted pin 111
1 | 7
4

5

Controller Jack Player 1 (SNES mini / SFC Jr.)

Installation:
- Solder the PCB directly to the bottom side of the cartridge port (be aware of the orientation)
- Place wires as depicted here (pad-‐design is optimized for the normal SNES):

to CIC
pad 8

to X1 / S-‐CPUN pin 9
(from bottom side with controller port facing you it is the
- Left solder joint of X1 in normal SNES
- Right solder joint of X1
in SNES mini / SFC Jr.)

Installation (continue):
* LED *
- Close jumper EITHERon left for using a LED with common anode (e.g. typical for RGB-‐LEDs) OR on right for using a LED with common cathode (e.g. typical for RG-‐LEDs)
- NEVER close both together!!!
- Solder the common base to the controller port where the old LED took place (normal SNES only)
- Short the old pre-‐resistor if you use a common anode LED type
- Connect the red pin with the LED-‐60Hz pad and the green one with LED-‐50Hz pad
(or use another color combination)

# J:SCIC and Pad SCIC Clk #

- Close EITHER the jumper OR wire the pad to CIC pad 7
(tip for normal SNES: there is a capacitor place on bottom marked with C72 (NTSC system) or C74 (PAL system), where you can get the connection to CIC pad 7 (left solder joint))
- NEVER close the jumper and wire the pad!!!
- If you close the jumper, the SuperCIC uses the clock source for the CIC-‐key
- If you wire the pad to CIC pad 7, the SuperCIC uses the clock source for the CIC-‐lock (use this option if you observe problems with closing the jumper; e.g. SA-‐1 game doesn‘t boot or SuperCICs cannot go into pairmode)

(tip for normal SNES:
there is a via right in front of the pad; you may find it if you follow the wire comming from S-‐APU pin 100)

(tip for normal SNES (NTSC): use the jumper instead of
lifting the pin)

Tip:
CIC pad 8 is connected with
the reset button
(of course – the pad says Rst (in) ;) from bottom side with controller port facing you it is the
- Lower right pin in normal SNES
- Upper left pin in SNES mini / SFC Jr.)

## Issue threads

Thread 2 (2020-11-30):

DFO programming via Arduino verify fails.

ArcadeTV, 2020-11-30:
I get this error on both UNO and NANO boards, testing with 2 different PCBs.
Of course this could be a user issue.
Value read at reg 0x1E: 0x2 (0x72 expected) looks suspicious.

This is my first SNES_MultiRegion_with_DeJitter_QID install and I wanted to say thanks and give a big hug!

```
Wait for CDCE913: ... Found! (CDCE913 I2C Address: 0x65)
Write registers: ................................ done!
Verify registers: ...
 - Number of bytes returned: 32
 - Value read at reg 0x0: 0x81 (not evaluated as reg is read only)
 - Value read at reg 0x1: 0x1 (0x1 expected)
 - Value read at reg 0x2: 0xBC (0xBC expected)
 - Value read at reg 0x3: 0x6 (0x6 expected)
 - Value read at reg 0x4: 0x1 (0x1 expected)
 - Value read at reg 0x5: 0x90 (0x90 expected)
 - Value read at reg 0x6: 0x40 (0x40 expected)
 - Value read at reg 0x7: 0x40 (not evaluated as reg is read only)
 - Value read at reg 0x8: 0x40 (not evaluated as reg is read only)
 - Value read at reg 0x9: 0xCF (not evaluated as reg is read only)
 - Value read at reg 0xA: 0xFF (not evaluated as reg is read only)
 - Value read at reg 0xB: 0xFF (not evaluated as reg is read only)
 - Value read at reg 0xC: 0xFF (not evaluated as reg is read only)
 - Value read at reg 0xD: 0xFF (not evaluated as reg is read only)
 - Value read at reg 0xE: 0xFF (not evaluated as reg is read only)
 - Value read at reg 0xF: 0xFF (not evaluated as reg is read only)
 - Value read at reg 0x10: 0x0 (0x0 expected)
 - Value read at reg 0x11: 0x0 (0x0 expected)
 - Value read at reg 0x12: 0x0 (0x0 expected)
 - Value read at reg 0x13: 0x1 (0x1 expected)
 - Value read at reg 0x14: 0x6B (0x6B expected)
 - Value read at reg 0x15: 0x1 (0x1 expected)
 - Value read at reg 0x16: 0x18 (0x18 expected)
 - Value read at reg 0x17: 0x5 (0x5 expected)
 - Value read at reg 0x18: 0x4F (0x4F expected)
 - Value read at reg 0x19: 0x55 (0x55 expected)
 - Value read at reg 0x1A: 0x53 (0x53 expected)
 - Value read at reg 0x1B: 0xEC (0xEC expected)
 - Value read at reg 0x1C: 0x96 (0x96 expected)
 - Value read at reg 0x1D: 0xF1 (0xF1 expected)
 - Value read at reg 0x1E: 0x2 (0x72 expected)
... VERIFICATION ERROR!
Number of Bytes not as expected!
First register error at 0x1E!
```

ArcadeTV, 2020-12-01:
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

Getting the same failure with any combination of arduinos and dfo's.

borti4938, 2020-12-01:
I'm not very experienced with Arduino either. So I'm not quite sure what's exactly going on. Just a broad guess, which might be completely wrong: It seems like that the total number of values read and write with the Wire library is limited. (which was not the case when I tested it..???).
Could you please try the following implementation where I cut both writes and reads in half pieces.

[Test code for Alex](https://1drv.ms/u/s!AosQhmNoM7qSjVq8mv0kHfOZXwAa?e=feOmjE)

Not sure if it runs correctly as I cannot test it at the moment.

Good luck!

ArcadeTV, 2020-12-01:
That did the trick :-)
It's soo nice to have this alternative for programming!
Thanks my dear!

```
Wait for CDCE913: ... Found! (CDCE913 I2C Address: 0x65)
Write registers: ................................ done!
Verify registers: ...
 - Value read at reg 0x0: 0x81 (not evaluated as reg is read only)
 - Value read at reg 0x1: 0x1 (0x1 expected)
 - Value read at reg 0x2: 0xBC (0xBC expected)
 - Value read at reg 0x3: 0x6 (0x6 expected)
 - Value read at reg 0x4: 0x1 (0x1 expected)
 - Value read at reg 0x5: 0x90 (0x90 expected)
 - Value read at reg 0x6: 0x40 (0x40 expected)
 - Value read at reg 0x7: 0x40 (not evaluated as reg is read only)
 - Value read at reg 0x8: 0x40 (not evaluated as reg is read only)
 - Value read at reg 0x9: 0x40 (not evaluated as reg is read only)
 - Value read at reg 0xA: 0x0 (not evaluated as reg is read only)
 - Value read at reg 0xB: 0x0 (not evaluated as reg is read only)
 - Value read at reg 0xC: 0x0 (not evaluated as reg is read only)
 - Value read at reg 0xD: 0x0 (not evaluated as reg is read only)
 - Value read at reg 0xE: 0x0 (not evaluated as reg is read only)
 - Value read at reg 0xF: 0x0 (not evaluated as reg is read only)
 - Value read at reg 0x10: 0x0 (0x0 expected)
 - Value read at reg 0x11: 0x0 (0x0 expected)
 - Value read at reg 0x12: 0x0 (0x0 expected)
 - Value read at reg 0x13: 0x1 (0x1 expected)
 - Value read at reg 0x14: 0x6B (0x6B expected)
 - Value read at reg 0x15: 0x1 (0x1 expected)
 - Value read at reg 0x16: 0x18 (0x18 expected)
 - Value read at reg 0x17: 0x5 (0x5 expected)
 - Value read at reg 0x18: 0x4F (0x4F expected)
 - Value read at reg 0x19: 0x55 (0x55 expected)
 - Value read at reg 0x1A: 0x53 (0x53 expected)
 - Value read at reg 0x1B: 0xEC (0xEC expected)
 - Value read at reg 0x1C: 0x96 (0x96 expected)
 - Value read at reg 0x1D: 0xF1 (0xF1 expected)
 - Value read at reg 0x1E: 0x72 (0x72 expected)
 - Value read at reg 0x1F: 0x69 (0x69 expected)
... done!
Store registers in EEPROM: ... requested ... done!
SUCCESS!
```

borti4938, 2020-12-01:
thank you for your feedback 👍
fix is in commit 0936e4b19fc30c70eed8a8d232697d76a9ff9820

Closed 2020-12-01.

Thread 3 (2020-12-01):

Flashing the CPLD with 3.3V

ArcadeTV, 2020-12-01:
This is more of a question than an issue...
I have an Altera USB-Blaster that I kept for flashing updated firmwares to the nesrgb. On my DIY-adapter I connect a 3.3V power supply.
Since you mentioned "please use the 5V power supply rail to not harm the DC converters" in the readme I'm unsure if it's safe to use the 3.3V instead of 5V while the pcb is not installed into the console yet.

ArcadeTV, 2020-12-01:
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

The flashing was reported successful, while powering with 3.3V and pcb not installed yet.

borti4938, 2020-12-01:
Personally I power the board over the I2C header of the CDCE913. It is 5V 'global' board power there.
By doing so, you will have the reference voltage of the CPLD set and can use the USB Blaster.

Powering the board just over the JTAG header might dagerous as you are 'behind' the 3.3V LDO. I cannot recommend that.

ArcadeTV, 2020-12-01:
I will do so, thanks for clearing that up!

Closed 2020-12-01.

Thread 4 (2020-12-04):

Documentation help offer

ArcadeTV, 2020-12-04:
I had a hard time figuring out all possible combinations of parts and connections when using the SMR20200325 and SNES_RGBAmp_wCSYNC into a SNSP-CPU-1CHIP-02, so I made this flowChart:

https://www.dropbox.com/s/7jbngqexuoay9ys/FlowChart_-_SMR20200325_and_SNES_RGBAmp_wCSYNC.pdf?dl=1

_alternative download/view link:
https://drive.google.com/file/d/19KD6h5U29KIDaIiM5uR2cwm81-4a2RUT/view?usp=sharing_

If you find the time to review it and leave some feedback for improvements, I'd like to offer to make a chart for all SNES models, so you can add them to the repository for others that may have trouble gathering all the info on both projects.

ArcadeTV, 2020-12-04:
I just updated the PDF to fix some typos and fixed some alignment.

ArcadeTV, 2020-12-06:
Also I found that google forms is a great tool for conditional steps of an install guide.

https://forms.gle/T5UTCCGdLv6wvKRK8 (mockup, incomplete)

duncan1111, 2021-05-25:
on your documentation, when you talk about the RGB bypass. You say:
NTSC > Populate R13,R23,R33 with 39Ω
PAL > Populate R13,R23,R33 with 75Ω

Should this not be the other way around, in the BOM its 75Ω for NTSC and 39Ω for PAL?

borti4938, 2024-04-24:
Thank you my lovely Alex :)

Closed 2024-04-24.

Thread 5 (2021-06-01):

DFO programmer 5V?

whf789, 2021-06-01:
When programming the DFO, the readme says "Set V-target jumper on programmer to 5V"
(here: https://github.com/borti4938/SNES_MultiRegion_with_DeJitter_QID/blob/master/fw/dfo/SOURCE.md)

I am using this DFO programmer https://oshpark.com/shared_projects/SeJLCY52 which is recommended, but it only outputs 3.3V. How did you modify the DFO programmer output 5V for this process?

Thanks for this project! 👍

borti4938, 2021-06-02:
Hey :)

If I were you I would simply test with 3.3V first. If you are lucky it works. At least you cannot break anything.
If it does not work, you can get 5V from the 100nF ceramic capacitor right next to the FT232 chip (lower pad). Make sure that the slider is turned off and then connect 5V from the cap with Vtg (LED should turn on although slider is off).

Best Regards and good luck :)

whf789, 2021-06-02:
Hi Borti,

I have tried with 3.3V and it said "CDCE913 successfully programmed" in the CDCEXX Programmer, so I assume it worked :)

Thanks for your reply & help.

borti4938, 2021-06-02:
Great 👍 Good luck with installation and have fun with the mod 😃

Closed 2021-06-02.

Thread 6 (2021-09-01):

Feature Request: Enable/Disable dejitter with ulGR

FixingGlobe, 2021-09-01:
Adding a sliding switch is not always an elegant solution to enable/disable dejitter via SJ31.
I think it should be possible to add a transistor to enable/disable dejitter. SJ31 should still remain because of backwards compatibility. Of course it will need a circuit to prevent SJ31 and the transistor to both be enabled and disabled at the same time. In any case if SJ31 is closed, this should count as master. This will require a new pcb.
For the button combination I would suggest the retrobit combination and switch Start with Select.
This is mostly for speedrunners and I even try to come up with a circuit and software by myself.

borti4938, 2022-04-15:
This needs redesign as the PIC does not have a pin free for that. Sorry - no chance at the moment. But it is on my todo since I was designing this board. But my personal interest was not high enough ;)

borti4938, 2024-04-24:
May never happen... Closed for the moment

Closed 2024-04-24.

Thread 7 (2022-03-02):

CPLD (U3) replacement?

whf789, 2022-03-02:
Hello,

Is there any suitable replacement for U3 = EPM7032AETC44-10N ?

The chip is now obsolete.

Thanks!

borti4938, 2022-03-29:
As far as I see it, the ATF15xx series by microchip should be a drop in replacement.
There are 3.3V Vcc varaints (ATF1502ASV), which can be used directly, and 5V variants (ATF1502AS), which need a slight PCB modification.
I bought some ATF1504ASV (ATF1502ASV was not available) and see how it goes. Afterwards I can update instructions.

duncan1111, 2022-03-30:
https://www.digikey.co.uk/en/products/detail/microchip-technology/ATF1504ASVL-20AU44/1008357

this one?

borti4938, 2022-03-31:
> https://www.digikey.co.uk/en/products/detail/microchip-technology/ATF1504ASVL-20AU44/1008357
>
> this one?

exactly. They arrived today. I will let you know once I found the time.

> Now to find some CDCE913... They're out of stock everywhere and there seems to be no suitable replacement without changing the package.

Actually, I don't know if I have some spares at home. But I defenitely have some spare CPLDs (ten or so) if this helps.

duncan1111, 2022-03-31:
Is the "marqs85" dejitter code the same as your one?

I ask as i want to know if i can take the ATF1502AS off a marqs85 snes dejitter and install on the AIO cic board?

I also have some EPM7032STC44-10N. are these suitable also?

borti4938, 2022-04-03:
> I ask as i want to know if i can take the ATF1502AS off a marqs85 snes dejitter and install on the AIO cic board?

Unfortunately, marqs85 uses the 5V variant, I use the 3.3V variant as I initially went for the Altera CPLDs, which were only available in 3.3V. Using the 5V variants would need to modify the PCB a bit.

> EPM7032STC44

Same here, also a 5V chip.

> exactly. They arrived today. I will let you know once I found the time.

Good news: I successfully tested one :) Just have to write instructions - maybe this evening.

borti4938, 2022-04-03:
fw builds and instructions are ready

Closed 2022-04-03.

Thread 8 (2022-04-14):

SHVC-CPU-01 installation

RamsesUTL, 2022-04-14:
Hi ... I bought the mod from VGP and did not check upfront which board version I have (stupid I know).
Turns out I have a first generation US SNES (with the discrete audio card) and the SHVC-CPU-01 board and there is no installation guide listed here for that :-(
Because it was my first own console back in the days I'm emotionally attached to that US device and would really love to use it with the mod, but I'm not sure if I'm good enough to just follow the general installation instructions and figure everything out by myself.

Has anyone experience with the installation in that SNES model and can provide instructions or pictures?
Or is there maybe someone in Germany that could offer installation service?
Thanks!

borti4938, 2022-04-14:
OK, good news I guess. I also bought the mod from VGP and successfully modded today a SHVC-CPU-01 board today. I think I will have the description ready in a few days. So you should be good to go then such that you can try it on your own. :) Otherwise I can also offer installation service. Just contact me if you like to take that offer.
Best regards :)

RamsesUTL, 2022-04-14:
You are a lifesaver. Thanks for the offer. I'll take a look at your instructions and if I'm not starting to sweat right away I'll give it a try. Otherwise you'll get a cry for help mail from me ;-)

borti4938, 2022-04-15:
Here you are :) [Installation for SHVC-CPU-01](https://github.com/borti4938/SNES_MultiRegion_with_DeJitter_QID/tree/master/installation/SHVC-CPU-01)

Closed 2022-04-15.

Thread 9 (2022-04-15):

Help with Color Carrier Switching on Non-Documented Models

borti4938, 2022-04-15:
Someone wrote me on Twitter the following.

> I still trying install that board on SNS-CPU-GPM-02. And i almost finished. But not sure about CCLK_output. Due to [schematics](https://wiki.superfamicom.org/uploads/snes_schematic_color.pdf) i should be in chain before 14 pin of S-Enc (VCXO Input), right?
> Can you help me what i should?
> Same as with SNS-CPU-RGB-01 remove R29 or R27, and solder through 470 ohm resistor? P.S. I use 8 pin of s-enc, not 7 as in s-rgb. Others seems the same.

> Or if you have good schematics of SNS-CPU-RGB-01, with s-rgb and right names of caps and res, please share. Thanks.

>Or just explain, where in schematic R4 from your installation manual on SNS-CPU-RGB-01. Right after 3 pin of S-PPU2, or right before VCXO input on S-RGB?

> I need to know where exactly R4 in chain between PPU2 and S-RGB.

Later I also received this picture
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

borti4938, 2022-04-15:
First of all - I also do not have any other schematics out of nowhere. It also seems to me that the requester mixed up **S-ENC** and **S-RGB**. These two chips are completely different encoders and have different connections from PPU to encoder.

### SNS-CPU-GPM-02
The picture shows a model with **S-ENC** (probably SNS-CPU-GPM-02), however, he referenced to an instruction (SNS-CPU-RGB-01) with an S-RGB encoder.

Ok, by his picture, the following things have to be done
- modding boards with R62 footprint:
  - move R29 from SNES mainboard to the modding board R62 footprint.
  - Check, which footprint side of R29 is connected to S-PPU2 pin 3
  - Connect _CClk.o_ pad on the modding board to the R29 footprint pad, which is NOT connected to S-PPU pin 3
  - Solder _SJ63_
- modding boards without R62 footprint:
  - lift S-PPU pin 3
  - Connect _CClk.o_ pad on the modding board with the pad below S-PPU pin 3

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

### SNS-CPU-RGB-01
On the mentioned SNS-CPU-RGB-01 mainboard R4 directly connected to S-PPU2 pin 3. In the [instructions](https://github.com/borti4938/SNES_MultiRegion_with_DeJitter_QID/tree/master/installation/SNS-CPU-RGB-01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) I already mentioned R59, but this 'resistor' does not count as it is just a 0 ohm jumper.

R59 is removed to clear up the picture on this model. R4 is actually the first resistor which is part of the color carrier circuit to the S-RGB chip. By the instructions it is rerouted such that R4 will sit between modding board and S-RGB instead of between S-PPU2 and S-RGB.

As mentioned, I don't have a schematic on that. I found that by checking with a continuity test (digital multimeter; never draw a cicrcuit diagram for that) and comparing with [PCB scans](https://www.dropbox.com/sh/33886pwfi08kvxg/AAA2sP6PGiJ3dz11Phxk48-Ea/NINTENDO/SNES_SFC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).

Hope this helps!

borti4938, 2022-04-15:
Closed for the moment - reopen for any additional questions possible :)

Closed 2022-04-15.

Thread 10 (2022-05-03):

CSYNC / RGB Bypass Board Clarification

bryanveloso, 2022-05-03:
I just got my board and I'm attempting to install it in a SNES Mini (following the SNN-CPU-01 instructions) that already has Voultar's RGB Bypass. According to the instructions:

> I do have an RGB bypass PCB in this repository. Just take a [look](../../../RGB Bypass/). If you use a version with CSYNC you can connect /CS.o (raw) to this PCB to use it.

I can connect `/CS.o (raw)` to the bypass board. If I do this, am I taking CSYNC from the CPUN? Or am I taking it from S-Video as per the provided instructions?

borti4938, 2023-08-30:
Sorry for the late reply.

I'm actually not 100% sure how Voultars board deals with CSync. But working with the /CS.o (raw) output should work.
As input for the modding board, use CSync from CPUN, yes.

Closed 2024-04-24.

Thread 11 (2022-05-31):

SMR20190813 Questions

SonnoOcea, 2022-05-31:
Hi,
I have some SMR20190813 boards left since I made one some time ago.
Since I want to make another pair but don't want to throw the left over PCBs away, am I missing some major features/fixes?
Like, looking at the BOM I've seen that it's missing Video Drivers.

Also, I need to install it to a PAL 1CHIP, do I need to do something else since it's PAL?

Have a nice day,
Sonno

borti4938, 2023-08-30:
Sorry for the late reply.
There were no major changes. You can still use your old PCBs. IIRC the only difference should be the replacement of a transistor with a TSH122 as video driver for buffer csync. Not a big deal.

Closed 2023-08-30.

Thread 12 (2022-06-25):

New Atmel CPLD Issue

whf789, 2022-06-25:
Hi,
I am trying to program the new ATMEL CPLD part no. ATF1504ASV(L) as per the instructions on the GitHub page but am having a bit of trouble.

When initializing the jtag connection, I get the error:

`C:\Users\X>openocd -f openocd-ft2232h.conf
Open On-Chip Debugger 0.11.0
Licensed under GNU GPL v2
For bug reports, read
        http://openocd.org/doc/doxygen/bugs.html
C:/msys64/mingw64/bin/../share/openocd/scripts/openocd-ft2232h.conf:3: Error: invalid command name "ftdi"
in procedure 'script'
at file "embedded:startup.tcl", line 26
at file "C:/msys64/mingw64/bin/../share/openocd/scripts/openocd-ft2232h.conf", line 3`

I was told elsewhere to "Not to use some out-of-tree way to init JTAG adapter and instead source ftdi/minimodule.cfg."

Moreover, I was also told "This odd script isn't suitable for this version of OpenOCD, use scripts that come with the binary you got there."

Any help would be appreciated, I must say it was much more straightforward when I programmed two boards in the past using the EPM7032.

borti4938, 2022-06-25:
Can you use a build later than July 29th 2021? At least this version works for me. Afaik some commands were changed.

This is my first project where I worked with opencd. I didn't want to write "please go and buy an expensive Atmel programmer" in the documentation.

Side note:

> I was told elsewhere to "Not to use some out-of-tree way to init JTAG adapter and instead source ftdi/minimodule.cfg."
>
> Moreover, I was also told "This odd script isn't suitable for this version of OpenOCD, use scripts that come with the binary you got there."

I know that I'm not an expert, but at least I think that I'm somehow not a noob. I cannot understand what the two trolls want you to do. The first one is somehow ok, but he should have mentioned where to source and what to do then (use out of box, some adaptations needed, what ever)

The second is just a troll. Sounds to me: "The script is odd or just crap, but I don't say why..."

whf789, 2022-06-26:
Borti, thanks for your reply.

Firstly please allow me to apologize. I simply copied and pasted their reply as I thought it may somewhat be helpful incase there was a problem with the .conf file, but it seems that is not the problem at all.

Back to the issue on hand... I followed your advice as I was previously using the "latest"/stable release 07 Mar 2021 v0.11.0. After updating to the pre-release from two days ago, it seems to have now detected successfully!

However, when following your instructions to open another terminal to interact with openocd:

`telnet localhost 4444
> svf <full_path_to_svf_file>`

I cannot get it to work. Here is what it says on my command prompt:

Command prompt to initialize JTAG:

`C:\Users\X>openocd -f openocd-ft2232h.conf
Open On-Chip Debugger 0.11.0+dev-00748-ga70bab9e5 (2022-06-24-21:57)
Licensed under GNU GPL v2
For bug reports, read
        http://openocd.org/doc/doxygen/bugs.html
adapter speed: 1000 kHz

Info : Listening on port 6666 for tcl connections
Info : Listening on port 4444 for telnet connections
Info : clock speed 1000 kHz
Warn : There are no enabled taps.  AUTO PROBING MIGHT NOT WORK!!
Info : JTAG tap: auto0.tap tap/device found: 0x0151403f (mfg: 0x01f (Atmel), part: 0x1514, ver: 0x0)
Warn : AUTO auto0.tap - use "jtag newtap auto0 tap -irlen 3 -expected-id 0x0151403f"
Warn : gdb services need one or more targets defined
Info : accepting 'telnet' connection on tcp/4444
svf [-tap device.tap] <file> [quiet] [nil] [progress] [ignore_error]
xsvf (tapname|'plain') filename ['virt2'] ['quiet']`

telnet localhost 4444 command prompt:

`C:\Users\Will>telnet localhost 4444
Trying ::1...
Connection failed: Connection refused
Trying 127.0.0.1...
Connected to localhost.
Escape character is '^]'.
Open On-Chip Debugger
> svf <C:\Users\X\Downloads\SNES_MultiRegion_with_DeJitter_QID-master (3)\SNES_MultiRegion_with_DeJitter_QID-master\fw\Logic\output_files\multi_func_atmel\multi_function_64.svf>
svf [-tap device.tap] <file> [quiet] [nil] [progress] [ignore_error]
xsvf (tapname|'plain') filename ['virt2'] ['quiet']`

Any ideas what to try next? I cannot get it to initiate the programming.

whf789, 2022-07-17:
Worked this out btw.
If anyone using windows has the same issue, before openocd, cd to the path then use svf <filename> directly and it will work.

borti4938, 2022-07-18:
Sorry that I missed that. Glad that you found a solution for you. Otherwise you have to use the slash " /" in the path name instead of backslash "\" when connected to the OpenOCD although you are running it on Windows.

Closed 2022-07-17.

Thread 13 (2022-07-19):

BOM Substitutions

meisenbarth, 2022-07-19:
Is the CDCEL913 a valid substitute for CDCE913? The main differences appears to be Vddout max.

I'm also assuming the PIC16F18324 will be a valid sub for the older PIC16F684.

borti4938, 2022-07-21:
You cannot use the CDCEL913 as VDDOUT is connected to 3.3V.

For the 16F18324: you can go ahead and port the code. The hex file for the 16F684 will probably not work.

Razer41, 2022-08-02:
A follow up question on BOM substitutions if that's ok... Is there any drop in replacements for the following?
TSH122ICT
9C-27.000MAAJ-T

borti4938, 2022-08-07:
For thd TSH122ICT you can use the OPA360AIDCKR. For the 9C-27.000MAAJ-T you may use the HC49USM-FF3F18-27.000MHZ or HC49USM-FF5F18-27.000MHZ.

I should update the BOM, I know

meisenbarth, 2022-09-17:
For the TSH122ICT can you confirm the part orientation on the newest board (pin1)? I tried to view the brd file and was unable to get it to load.

borti4938, 2022-09-17:
Pin 1 is bottom left

~~~~
        +-------+
R92 <-  | 6 5 4 |  -> to C93
SJ93 <- | 1 2 3 |  -> to C94
        +-------+
~~~~

Razer41, 2022-09-21:
There is no other substitutions for ATF1502ASV or ATF1504ASV(L)? Both sadly out of stock until next years.
Only package remaining for this parts is PLCC variant which has different pin pitch so cannot be used

borti4938, 2022-09-25:
It is possbily suitable to replace the CPLD with a XCR3064XL. But it is also difficult to source one, here.

Scenz, 2023-01-27:
@borti4938 do you think a EPM3064A could also work as they are good available and also 5V tolerant

borti4938, 2023-01-28:
Might be possible, but you have to change the PCB layout first

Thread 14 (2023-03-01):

Is the TSH122ICT required?

Nidhoegger, 2023-03-01:
I cannot get my hand on TSH122ICT Chips. Are they required if I do not use the bufferd output line? I am fine with the raw line, can I just leave the Chip out of the design? I cannot see why not when looking at the schematics, but I am not too familiar with it.

borti4938, 2023-08-30:
The TSH122 buffers the CSync output. It is recommended if you want to forward sync through an RGB cable. A good pinout compatible replacement is the OPA360, which should be easier to get.

Last alternative is to go back in the history of this repository and build the PCB version with a transistor instead of the TSH122.

Closed 2023-08-30.

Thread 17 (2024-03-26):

Controller sniff suddenly stopped working

kirkegaard, 2024-03-26:
Hi, Ive had my board installed for a couple of weeks now and its been working great. But today while playing the key combinations stopped working. It wont let me region switch, or reset the console. I can still change the region using the reset button which makes me think the uIGR is good. As i understand it its both the input sniffer and what holds the region?

Is it possible to disable the input sniff accidentally maybe? Or do you have any other clues for what i need to check? Maybe theres a test point i can probe to see if the inputs are registered?

borti4938, 2024-04-01:
https://github.com/borti4938/SNES_MultiRegion_with_DeJitter_QID/blob/master/fw/uIGR/Manuals/uIGR_Manual.pdf

Page no. 3 - lock types

kirkegaard, 2024-04-01:
Oh my god! That was it! Thank you thank you thank you!

Ive been poking around for at least one week now and couldnt figure out what i did wrong. I cant believe i missed the lock types! The board has been working great on my SNSP-CPU-02 SNES! Thank you for all your work on this board

Closed 2024-04-01.

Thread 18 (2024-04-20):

SuperCIC + FXPAK PRO pairing mode not working

DerElefant69, 2024-04-20:
Hey, first of all thanks for this awesome work!

I have a PAL SNES with a SNSP-CPU-02 mainboard. Yesterday I put in the modchip according to the documentation on this site and everything seems to be okay. My PAL cartridges work fine and the modchip is detecting the Game as PAL 50Hz in Auto Mode (unfortunately I don't have NTSC cartridges to test with). I can also switch the modes manually with the reset button and with the Controller Inputs that come with the uIGR, so everything ok.

Now with my FXPAK PRO on the latest Firmware there is a strange behavior (didnt test other firmware). I have done all settings as described to turn on the pairing mode for the SuperCIC and the FXPAK PRO. Now when I turn on the console, I get 60Hz, but when I start a PAL rom it changes to 50Hz for some miliseconds and then jumps back to 60Hz. I can't switch the mode with the reset button anymore, only with Controller Inputs over uIGR, but this should normally not be necessary in pairing mode? Do you have any idea why this happens? I didn't find anything on the net and any help would be appreciated.

- I tested several PAL roms
- I turned off auto region patch in the FXPAK PRO
- Region patch from SuperCIC is active
- Turned on the SuperCIC mode for uIGR as described.

I checked the values of the frequency over a Retrotink to be sure.

Thanks in advance and greetings from Germany 🙂

PS: I bought the modchip from Retroupgrades.co.uk

borti4938, 2024-04-24:
Hi,

it is normal that switching modes via reset button does not work anymore as soon as the SuperCIC is in pairmode.
The other issue: I assume that you set the menu settings to auto. It sounds like that lock and key run out of sync somehow. But I'm not really sure about that. The only thing which you can check, is if the SuperCIC on the mod board is properly soldered (incl. clock line and pins on the cart slot pins 56, 55, 25 and 24). Also you may give the edge connector of the cart slor a clean...

Maybe it is also something completely different. One question: does the region patching works on PAL games? Please try e.g. MMX2 or MMX3 on PAL (playing through first level - if the game resets the region patching assumes a NTSC ROM being loaded...

Best regards (also from Germany)

DerElefant69, 2024-04-26:
Hi,

yes, the setting in the SuperCIC menu is set to auto.

I tried several things now, but I'm not getting any closer to solve the problem. Here are the things I tried:

- cleaned the cartridge connector and the cartridge pins with IPA
- resoldered every connection from the mod board to the cartridge pins
- measured continuity from the mod board cartridge connection to the outer pins of the cartridge connector -> OK
- measured continuity from mod board SuperCIC pin 14 to Original CIC pad 9 and cartridge slot pin 5 + 36-> OK
- measured continuity from mod board SuperCIC pin 13 to Original CIC pad 8 -> OK
- measured continuity from mod board SuperCIC pin 11 to Original CIC pad 10-> OK
- measured continuity from mod board SuperCIC pin 10 to Original CIC pad 1 and cartridge slot pin 55 -> OK
- measured continuity from mod board SuperCIC pin 9 to Original CIC pad 2 and cartridge slot pin 24 -> OK
- measured continuity from mod board SuperCIC pin 8 to Original CIC pad 11 and cartridge slot pin 25 -> OK
- measured continuity from mod board SuperCIC pin 2 to Original CIC pad 7 -> OK
- measured continuity from mod board SuperCIC pin 2 to cartridge slot pin 56 -> NOT OK(?) (because jumper SJ11 is open. I soldered the Clk.CIC to pin 6 from S-CLK, as described in the installation instructions)
- measured continuity from mod board SuperCIC pin 1 to Original CIC pad 18 and cartridge slot pin 27 + 58 -> OK
- tried to close jumper SJ11 without soldering Clk.CIC to pin 6 of S-CLK in the first place, but that didn't work either.

I also tried MMX2 NTSC ROM on FXPAK pro (with deactivated region patch in settings) with fixed PAL mode:

- mod board region patch activated: ROM is playing as expected in 50Hz, without warning that the game pak is not for PAL region and I also get further than the first level.

- mod board region patch deactivated: ROM starts with warning, that game pak is not for PAL region, and after the first level the game gets reset.

So I guess that the region patch is working fine.

And now, after I spent some hours, I run out of ideas :) Maybe you have another idea why this happens. If not, I will live with it as it is :)

jamieshaw, 2024-05-14:
I too have a similar issue with an SNSP-CPU-02 board, however with a SD2SNES Rev. X cart (I have an official FXPAK PRO on the way).

It seems that the pair mode is somewhat of [a known issue](https://github.com/mrehkopf/sd2snes/issues/186) with the latest SD2SNES firmware, and there are a couple of beta firmwares in the thread for fixing the issue.

I've had mixed success myself. Sometimes the console will boot into 50Hz mode (my menu setting), and correctly swap between 50/60 depending on ROM (with appropriate LED colour change). 95% of the time, it boots into 60Hz with the LED indicator on orange/yellow for "auto" mode (but is in passthrough).

I can confirm the region is automatically being detected with the only other two carts that I have: a PAL Super Mario World, and an NTSC-J Super Game Boy 2. Both flick 50/60 as expected, including LED.

I'm curious if it's a timing issue with my questionable cart. Will see once the FXPAK PRO is received.

jamieshaw, 2024-05-24:
Just to follow up — FXPAK PRO received, swapped the same SD card from the SD2SNES to the FXPAK with ["issue186-try2"](https://github.com/mrehkopf/sd2snes/issues/186#issuecomment-1436132225) firmware and it booted to 50Hz (matching my setting) straight away.  Power cycled a few times, all to green (50Hz).

In comparison, the SD2SNES Revision X would flick to green maybe 1 in 10 attempts.  So for me, yes, a bad "clone" (despite open-source) cart.

I'd definitely recommend using the ["issue186-try2"](https://github.com/mrehkopf/sd2snes/issues/186#issuecomment-1436132225) firmware, if you haven't already.

DerElefant69, 2024-05-24:
Hi, thank you for your informations. My FXPAK PRO is also new. I bought it two months ago. I will try your suggested Firmware when I get home and see If it gets better. Will report back after I tested it.

DerElefant69, 2024-05-24:
Thank you very much! With your suggested firmware it works like a charm now :) So it was a problem with the FXPAK PRO firmware and not the AIO SuperCIC.

Closed 2024-05-24.

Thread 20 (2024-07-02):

SFC 1CHIP, cartridge needs Reset Button Press before it boots

retrogamer70, 2024-07-02:
I'm using the old Switchless Modboard (https://github.com/borti4938/SNES_MultiRegion_with_DeJitter_QID/tree/master/old.pcbs/SNES-1Chip) in my Switchless modded 1CHIP Super Famicom.

The console ran perfectly well for the first 5-6 months, I've been playing a lot on it.
But since a couple of weeks, if I want to boot cartridges (or my FXPAK Pro), the console won't output a video signal after I turn it on. The screen just stays black. I already found a workaround: if I press the reset button (short), then the cartridge will boot. Sometimes I have to press the reset button twice, then it boots.

This doesn't annoy me much, since the workaround fixed the "problem" entirely. I was just wondering what kind of problem this could be. I haven't had this behaviour in the first couple of months, and now, all of a sudden this problem exists.

Thanks for and advice or help.

borti4938, 2024-07-25:
Haven't heard about something like that. However, it does not sound that this issue is connected to the region mod. It's more the SNES itself (maybe instable power on power cycle). It's just a wild guess... Have you tried another power brick? Maybe it is also worth to replace the electrolyt capacitors.

retrogamer70, 2024-07-26:
Thanks for your reply and your evaluation. I'll try to find fixes with the console then, rather than with the modboard.

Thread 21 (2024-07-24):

Dejitter Clarification

King007t, 2024-07-24:
Hi, is the cs.o raw (ttl) dejittered too, because it only says dejittered for the cs.o buff (75 ohm) in the readme file. If both are dejittered which one would you recommend to use. I'm using a RGB Bypass Amp from Tzorri Mahm.

Best regards

borti4938, 2024-07-25:
Some kind of sloppy documentation on that. Both outputs originate from same CPLD pin. So also the raw output is dejittered, if turned on.
With the RGB bypass you can either connect the raw directly to the RGB bypass. Or you lift pin 14 on the THS7374, remove C51 and then connect the buffered output to MultiOut pin 3.

Closed 2024-07-25.

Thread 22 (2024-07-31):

Static diagonal noise whilst in PAL mode.

jamieshaw, 2024-07-31:
Apologies to raise an issue on this project about an installation rather than the build of the mod itself, just looking for some advice and this seemed like a good place to start.  I'm experiencing some faint diagonal bars, most noticeable on grays, following installation of this mod — _but only in **PAL** mode_.

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

I've installed a recent version of this board into a SNSP-CPU-1CHIP-01 console following **all** the relevant instructions as detailed in this repo for that particular revision, including colour carrier and CSYNC on pin 3.

Along side this, I've completed the following:
- Recapped the entire console.
- Replaced the voltage regulator with a 78S05.
- Added a 750Ω resistor to each RGB line for brightness fix.
- Replaced C11 with a 470nF capacitor for ghosting fix.
- Replaced C61 with a 22µF capacitor for the "vertical line" fix.

For reference, the SNES is outputting via a [RetroGamingCables NTSC CSYNC (attenuated) cable](https://www.retrogamingcables.co.uk/SUPER-NINTENDO-SUPER-FAMICOM-GAMECUBE-WII-N64-SNES-NES-RGB-SCART-CSYNC-COMPONENT-YPBPR-HDTV-HDMI-VIDEO-CABLES-CORD/SUPER-NINTENDO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) to an OSSC 256 optimised.  I can see that the VMODE is correctly switching on the S-CPUN on pin 111, as sd2snes' system information view reports the correct Hz.  Similarly, I can see that the OSSC is also getting the same, so assume the correct mode is being set in S-RGB on pin 9.

Installation seems sound and everything is continuous as expected, so not sure what the issue could be.  Seems like some frequency is bleeding into a line somewhere, that's causing interference when in 50Hz.

What I do notice is that without any cart, switching on the SNES produces a very noisy black screen.  Not sure if that's expected or not…

Not sure if anyone has experienced a similar issue and might be able to provide some insight?

More comparisons:
https://files.sha.wtf/jamie/waNESebi11.jpg
https://files.sha.wtf/jamie/VoQIQONo49.jpg
https://files.sha.wtf/jamie/QOQuPodi10.jpg

jamieshaw, 2024-07-31:
Also noticed that the angle of the interference differs on different colour background — not sure if that's indicative of anything. (Screenshot is PAL again).

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

Yellow and grey seem to go from top left to bottom right (\\\\\\)
Red and magenta seem to go from top right to bottom left (///), at a shallower angle.
Green almost looks like a mix of both…

jamieshaw, 2024-08-04:
All fixed using an RGB bypass. Closing.

Closed 2024-08-04.

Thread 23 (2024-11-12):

D4 region patching - temperamental

duncan1111, 2024-11-12:
I have recently installed the super cic aio board on a pal 1 chip, sfc jr and snes jr and pal cpu-02.

all are experiencing the same temperamental d4 patching issue.

I put jap all stars in and start console In pal mode - I get the region lock out error message. I power on and off and then it boots. Sometimes it’s just goes back to the error message. Does the same with Dkc2 Japanese cart. And does the same when in 60hz with Mario all stars pal.

I have made sure region patching is enabled - cleaned the cartridge and slots, resoldered the aio board. Replaced the cic and uigr chips, swapped and reprogrammed the ATF1502ASV. Swapped the SN74HCT125Dr.

Consoles have been recapped and new voltage regulators installed.

All parts are from mouser.

It odd as i get this on all consoles I have mentioned. I’d if you power on and off enough times it starts to boot.

not sure what else to swap out?

any experienced this?

thanks

duncan1111, 2024-11-12:
Fixed it! Put a 470uf cap on the voltage regulator and it’s fixed! Never seen this before, but I’m guessing it was a power issue?

duncan1111, 2024-11-12:
Fixed

Closed 2024-11-12.

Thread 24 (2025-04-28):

SJ32 and SJ63.2 relation question

LauraLovesRaccoons, 2025-04-28:
Hello,
I'm asking a question because I have a specific use case.  _(latest pcb and fw)_
I want to use a sliding switch on SJ32 to disable dejitter on the fly.
I also bridged/enabled SJ63.2 (the dejittered colour carrier) and left SJ63.1 open (very important).
Now if my sliding switch closes SJ32 it disables the dejitter but does that also disable the dejittered colour carrier from SJ63.2 ?

_SJ31: closing this jumper permanently disables the de-jitter function._    **for ME** this means everything dejitter related is disabled

It's not 100 percent clear in your documentation so sorry for asking :/

If it does disable it, it would be perfect for my use case 🙏

Cheers

LauraLovesRaccoons, 2025-04-29:
**TL;DR**
If SJ32 is toggled does it also toggle the dejitter colour carrier with a bridged SJ63.2 ?
  or should I leave both SJ63 open?
    _(basically if dejitter is enabled it should also use the dejittered colour carrier and vice versa for disabled dejitter on SJ32)_
_(1 Chip Mini/Jr.)_

LauraLovesRaccoons, 2025-04-29:
Did a bit of digging and SJ63.1 XOR SJ63.2 needs to be bridged.
Still not sure if bridging SJ32 disables the dejittered colour carrier on SJ63.2.

LauraLovesRaccoons, 2025-05-01:
According to this video (with timestamp)
https://www.youtube.com/watch?v=6uFcSpkLgLc&t=2483s
Having dejitter disabled through SJ32 and having SJ63.2 bridged also disables the dejittered colour carrier for composite and s-video.
Which leads me to the conclusion that if you have an (easily accessible) sliding switch for SJ32 and you might wanna use composite or s-video in addition to rgb, you probably should bridge SJ63.2 instead of SJ63.1 since this ensure you'll always can switch between these two modes on the fly.
Correct me if I am wrong.

LauraLovesRaccoons, 2025-05-01:
edited all mentions of SJ32 to SJ31 since I made a pretty serious typo

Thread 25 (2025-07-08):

PAL color carrier related issue on SHVC-CPU-01

XFreedy23, 2025-07-08:
Hello,

I installed a multiregion board, but unfortunately I have issues with PAL composite video signal. On top of the screen there is a purplish discoloration.

I saw, that this is a known  issue with some systems using dejitter mod, but for the PAL clock there is no dejittering.
For NTSC signal, closing the sj63.1 instead of SJ63.2 jumper solved the issue(and was less pronounced compared to PAL), but for PAL it stayed the same, but no surprise as PAL CCLK is derived from the same clock source regardless sj63.1 or sj63.2 is the closed one.

I am using the latest pcb version, with the smaller Altera CPLD, programmed with the latest files.

Other than the PAL composite video (I couldn't test s-video, I do not have the proper cables/adapters for it) everything seems to work perfectly, RGB output looks great in PAL and NTSC mode as well.

Any ideas how the pal signal could be fixed? I do not really understand, I mean the clock signal created by cdce913 must be at least as clear as one created by an original pal system. Maybe faulty cpld?

SFC motherboard is freshly recapped with original Würth Elektronik and Panasonic capacitors

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

XFreedy23, 2025-08-05:
I replaced the CPLD just in case, although it is from the same batch as the first one. Unfortunately the discoloration is still present in PAL mode.
I am using a different crystal (9C-27.000MAAJ-T) compared to the one in the BOM, although it seems to me it is an equivalent part, but maybe I am missing something(the one in the BOM is obsolete)

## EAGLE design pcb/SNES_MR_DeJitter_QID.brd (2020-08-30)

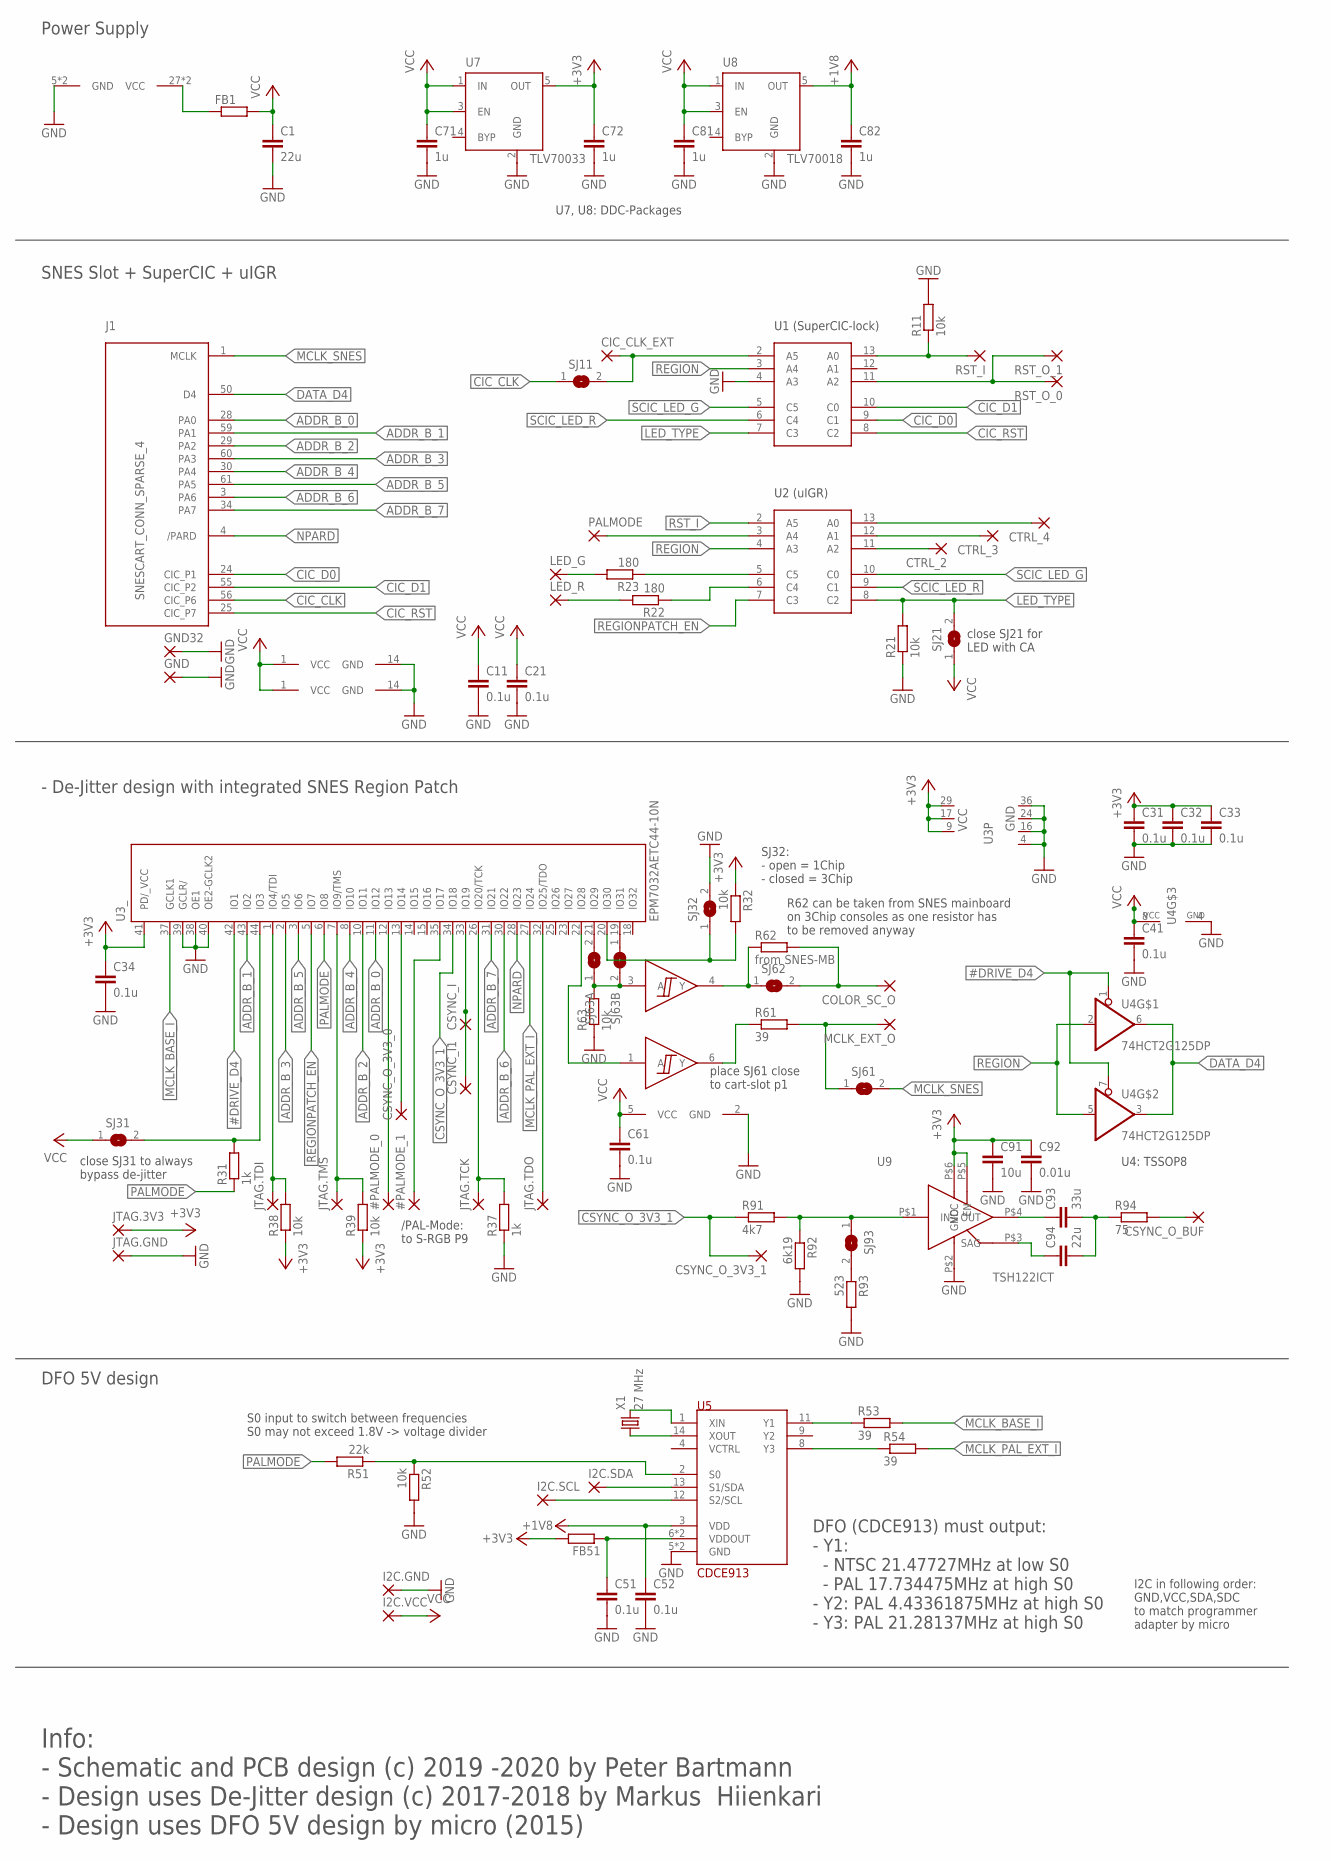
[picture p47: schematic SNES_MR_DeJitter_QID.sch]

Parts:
#PALMODE_0, #PALMODE_1: SMD2; SMD1,27-2,54
C1, C94: 22u; C0603
C11, C21, C31, C32, C33, C34, C41, C51, C52, C61: 0.1u; C0603
C71, C72, C81, C82: 1u; C0603
C91: 10u; C0603
C92: 0.01u; C0603
C93: 33u; C0805
CIC_CLK_EXT: SMD2; SMD1,27-2,54
COLOR_SC_O: SMD2; SMD1,27-2,54
CSYNC_I, CSYNC_I1: SMD2; SMD1,27-2,54
CSYNC_O_3V3_0, CSYNC_O_3V3_1: SMD2; SMD1,27-2,54
CSYNC_O_BUF: SMD2; SMD1,27-2,54
CTRL_2, CTRL_3, CTRL_4: SMD2; SMD1,27-2,54
FB1, FB51: R-EU_R0603; R0603
GND, GND32: SMD2; SMD1,27-2,54
I2C.GND, I2C.SCL, I2C.SDA, I2C.VCC: 1,6/0,8
J1: SNESCART_CONN_SPARSE_4
JTAG.3V3, JTAG.GND, JTAG.TCK, JTAG.TDI, JTAG.TDO, JTAG.TMS: 1,6/0,8
LED_G: SMD2; SMD1,27-2,54
LED_R: SMD2; SMD1,27-2,54
MCLK_EXT_O: SMD2; SMD1,27-2,54
PALMODE: SMD2; SMD1,27-2,54
R11, R21, R32, R38, R39, R52: 10k; R0603
R22, R23: 180; R0603
R31, R37: 1k; R0603
R51: 22k; R0603
R53, R54, R61: 39; R0603
R62: from SNES-MB; R0805
R63: 10k; R0805
R91: 4k7; R0603
R92: 6k19; R0603
R93: 523; R0603
R94: 75; R0603
RST_I: SMD2; SMD1,27-2,54
RST_O_0, RST_O_1: SMD2; SMD1,27-2,54
SJ11, SJ21, SJ32, SJ61, SJ62, SJ63A, SJ63B, SJ93: SJSMALL; SJ_SMALL
SJ31: SJ
U1: SuperCIC_lock; PIC16F630
U2: uIGR; PIC16F630
U3: EPM7032AETC44-10N; TQFP44
U4: 74HCT2G125DP; SSOP08
U5: CDCE913; TSSOP14
U6: 2G17TI_DBV; SOT-23-6
U7: TLV70033; SOT23-5
U8: TLV70018; SOT23-5
U9: TSH122ICT; SC70
X1: 27 MHz; HC49UP

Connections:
#DRIVE_D4: U3.42 (IO1), U4.1 (OE), U4.7 (OE)
+1V8: C52.1, C82.1, U5.3 (VDD), U8.5 (OUT)
+3V3: C31.1, C32.1, C33.1, C34.1, C72.1, C91.1, C92.1, FB51.2, JTAG.3V3.1, R32.1, R38.1, R39.1, U3.9 (VCC), U3.17 (VCC), U3.29 (VCC), U3.41 (PD/_VCC), U7.5 (OUT), U9.P$5 (EN), U9.P$6 (VCC)
+5V: C1.1, C11.1, C21.1, C41.1, C61.1, C71.1, C81.1, FB1.2, I2C.VCC.1, SJ21.1, SJ31.1, U1.1 (VCC), U2.1 (VCC), U4.8 (VCC), U6.5 (VCC), U7.1 (IN), U7.3 (EN), U8.1 (IN), U8.3 (EN)
+5V_SNES: FB1.1, J1.27 (VCC), J1.58 (VCC)
ADDR_B_0: J1.28 (PA0), U3.11 (IO12)
ADDR_B_1: J1.59 (PA1), U3.43 (IO2)
ADDR_B_2: J1.29 (PA2), U3.10 (IO11)
ADDR_B_3: J1.60 (PA3), U3.2 (IO5)
ADDR_B_4: J1.30 (PA4), U3.8 (IO10)
ADDR_B_5: J1.61 (PA5), U3.3 (IO6)
ADDR_B_6: J1.3 (PA6), U3.30 (IO22)
ADDR_B_7: J1.34 (PA7), U3.31 (IO21)
CIC_CLK: J1.56 (CIC_P6), SJ11.1
CIC_CLK_EXT: CIC_CLK_EXT.1, SJ11.2, U1.2 (A5)
CIC_D0: J1.24 (CIC_P1), U1.9 (C1)
CIC_D1: J1.55 (CIC_P2), U1.10 (C0)
CIC_RST: J1.25 (CIC_P7), U1.8 (C2)
COLOR_SC_OPT_O_PRE: SJ63B.1, U3.19 (IO31)
COLOR_SC_O_PRE: SJ63A.2, U3.21 (IO29)
COLOR_SC_PCB_O: COLOR_SC_O.1, R62.2, SJ62.2
COLOR_SC_PCB_O_PRE: R62.1, SJ62.1, U6.4 (Y)
COLOR_SC_PRE: R63.2, SJ63A.1, SJ63B.2, U6.3 (A)
CSYNC_I: CSYNC_I.1, CSYNC_I1.1, U3.33 (IO19)
CSYNC_O: CSYNC_O_BUF.1, R94.2
CSYNC_O_3V3_0: CSYNC_O_3V3_0.1, U3.13 (IO14)
CSYNC_O_3V3_1: CSYNC_O_3V3_1.1, R91.1, U3.34 (IO18)
CTRL2: CTRL_2.1, U2.11 (A2)
CTRL3: CTRL_3.1, U2.12 (A1)
CTRL4: CTRL_4.1, U2.13 (A0)
DATA_D4: J1.50 (D4), U4.3 (O), U4.6 (O)
DEJITTER_BYPASS: R31.2, SJ31.2, U3.44 (IO3)
GND: C1.2, C11.2, C21.2, C31.2, C32.2, C33.2, C34.2, C41.2, C51.2, C52.2, C61.2, C71.2, C72.2, C81.2, C82.2, C91.2, C92.2, GND.1, GND32.1, I2C.GND.1, J1.5 (GND), J1.36 (GND), JTAG.GND.1, R11.2, R21.1, R37.1, R52.2, R63.1, R92.2, R93.2, SJ32.2, U1.4 (A3), U1.14 (GND), U2.14 (GND), U3.4 (GND), U3.16 (GND), U3.24 (GND), U3.36 (GND), U3.38 (OE1), U3.39 (GCLR/), U3.40 (OE2-GCLK2), U4.4 (GND), U5.5 (GND), U5.10 (GND), U6.2 (GND), U7.2 (GND), U8.2 (GND), U9.P$2 (GND)
LED_G: LED_G.1, R23.2
LED_R: LED_R.1, R22.2
LED_TYPE: R21.2, SJ21.2, U1.7 (C3), U2.8 (C2)
MCLK_BASE_I: R53.2, U3.37 (GCLK1)
MCLK_BASE_I_PRE: R53.1, U5.11 (Y1)
MCLK_EXT_O: MCLK_EXT_O.1, R61.2, SJ61.1
MCLK_EXT_O_PRE: R61.1, U6.6 (Y)
MCLK_EXT_PRE: U3.22 (IO28), U6.1 (A)
MCLK_PAL_EXT_I: R54.2, U3.27 (IO24)
MCLK_PAL_EXT_I_PRE: R54.1, U5.8 (Y3)
MCLK_SNES: J1.1 (MCLK), SJ61.2
unnamed: R91.2, R92.1, SJ93.1, U9.P$1 (IN)
unnamed: U5.1 (XIN), X1.2
unnamed: U5.14 (XOUT), X1.1
unnamed: C94.1, U9.P$3 (SAG)
unnamed: C93.1, U9.P$4 (OUT)
unnamed: C93.2, C94.2, R94.1
unnamed: R93.1, SJ93.2
NPALMODE_0: #PALMODE_0.1, U3.12 (IO13)
NPALMODE_1: #PALMODE_1.1, U3.35 (IO17)
NPARD: J1.4 (/PARD), U3.28 (IO23)
PALMODE: PALMODE.1, R31.1, R51.2, U2.3 (A4), U3.6 (IO8)
PALMODE.1V8: R51.1, R52.1, U5.2 (S0)
REGION: U1.3 (A4), U2.4 (A3), U4.2 (I), U4.5 (I)
REGIONPATCH_EN: U2.7 (C3), U3.5 (IO7)
RST_I: R11.1, RST_I.1, U1.13 (A0), U2.2 (A5)
RST_O: RST_O_0.1, RST_O_1.1, U1.11 (A2)
SCIC_LED_G: U1.5 (C5), U2.10 (C0)
SCIC_LED_R: U1.6 (C4), U2.9 (C1)
SCL: I2C.SCL.1, U5.12 (S2/SCL)
SDA: I2C.SDA.1, U5.13 (S1/SDA)
SEL_SNES_1CHIP: R32.2, SJ32.1, U3.20 (IO30)
TCK: JTAG.TCK.1, R37.2, U3.26 (IO20/TCK)
TDI: JTAG.TDI.1, R38.2, U3.1 (IO4/TDI)
TDO: JTAG.TDO.1, U3.32 (IO25/TDO)
TMS: JTAG.TMS.1, R39.2, U3.7 (IO9/TMS)
UIGR_LED_G: R23.1, U2.5 (C5)
UIGR_LED_R: R22.1, U2.6 (C4)
VDDOUT: C51.1, FB51.1, U5.6 (VDDOUT), U5.7 (VDDOUT)

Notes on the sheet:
/PAL-Mode: to S-RGB P9
DFO (CDCE913) must output: - Y1: - NTSC 21.47727MHz at low S0 - PAL 17.734475MHz at high S0 - Y2: PAL 4.43361875MHz at high S0 - Y3: PAL 21.28137MHz at high S0
place SJ61 close to cart-slot p1
close SJ31 to always bypass de-jitter
close SJ21 for LED with CA
Info: - Schematic and PCB design (c) 2019 -2020 by Peter Bartmann - Design uses De-Jitter design (c) 2017-2018 by Markus Hiienkari - Design uses DFO 5V design by micro (2015)
S0 input to switch between frequencies S0 may not exceed 1.8V -> voltage divider
I2C in following order: GND,VCC,SDA,SDC to match programmer adapter by micro
U1 (SuperCIC-lock)
U2 (uIGR)
DFO 5V design
- De-Jitter design with integrated SNES Region Patch
SNES Slot + SuperCIC + uIGR
Power Supply
U7, U8: DDC-Packages
U4: TSSOP8
SJ32: - open = 1Chip - closed = 3Chip
R62 can be taken from SNES mainboard on 3Chip consoles as one resistor has to be removed anyway

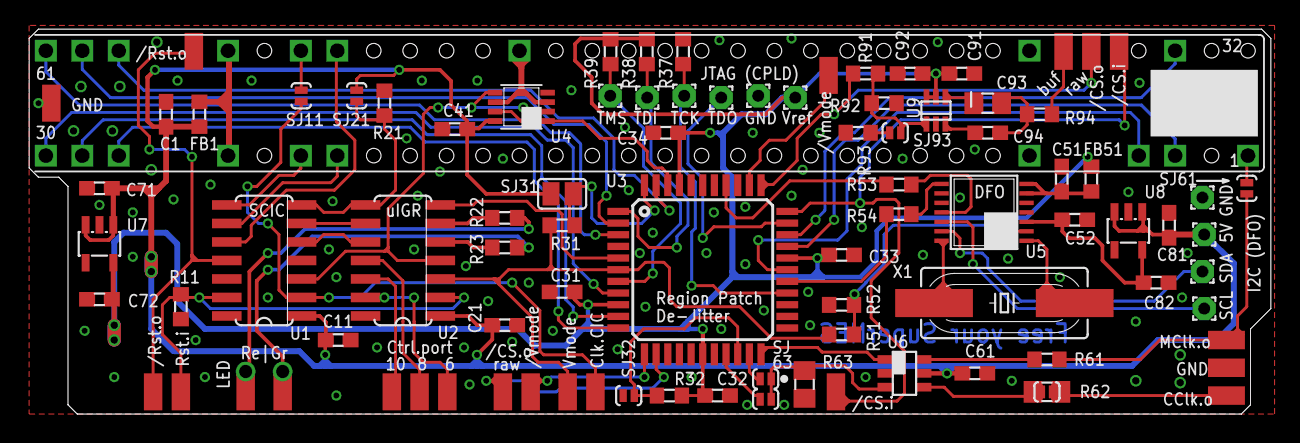
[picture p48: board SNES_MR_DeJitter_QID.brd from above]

Board: 2 copper layers, 85.2 x 26.4 mm, 92 parts (0 on the bottom side), 72 nets.

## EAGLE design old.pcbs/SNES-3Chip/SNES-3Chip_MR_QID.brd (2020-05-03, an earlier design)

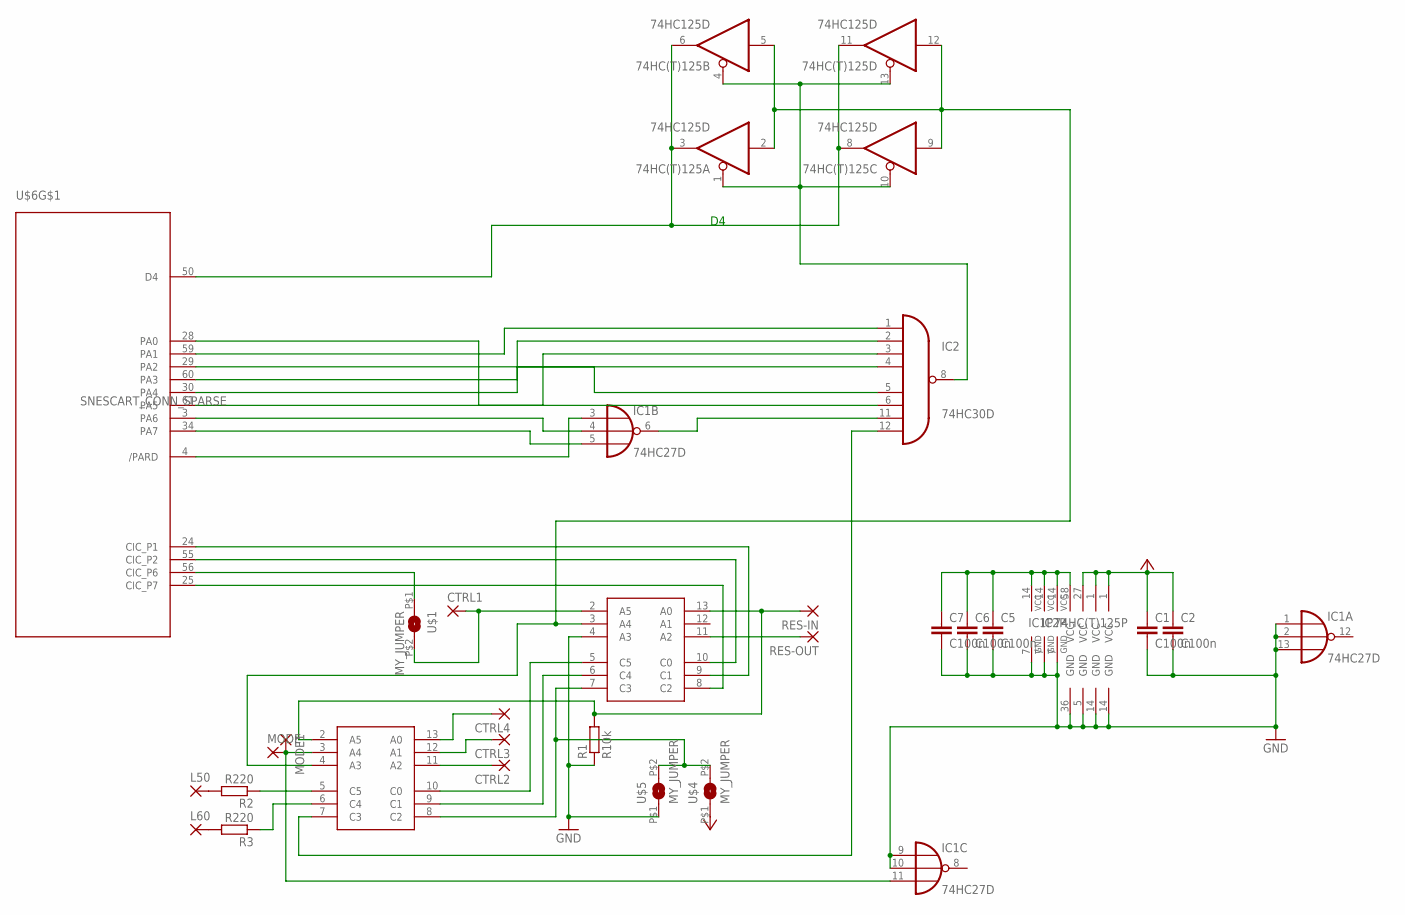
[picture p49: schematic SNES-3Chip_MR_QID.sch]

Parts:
74HC(T)125: 74HC125D; SO14
C1, C2, C5, C6, C7: C100n; Z0805
CTRL1, CTRL2, CTRL3, CTRL4: SMD2; SMD1,27-2,54
IC1: 74HC27D; SO14
IC2: 74HC30D; SO14
L50, L60: SMD2; SMD1,27-2,54
MODE, MODE1: SMD2; SMD1,27-2,54
R1: R10k; Z0805
R2, R3: R220; Z0805
RES-IN: SMD2; SMD1,27-2,54
RES-OUT: SMD2; SMD1,27-2,54
U$1, U$4, U$5: MY_JUMPER; MYJUMP
U$2, U$3: PIC16F630_SIMPLE; PIC16F630
U$6: SNESCART_CONN_SPARSE

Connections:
GND: 74HC(T)125.7 (GND), C1.2, C2.2, C5.2, C6.2, C7.2, IC1.1 (I0), IC1.2 (I1), IC1.7 (GND), IC1.9 (I0), IC1.10 (I1), IC1.13 (I2), IC2.7 (GND), R1.1, U$2.4 (A3), U$2.14 (GND), U$3.14 (GND), U$5.P$1 (1), U$6.5 (GND), U$6.36 (GND)
unnamed: 74HC(T)125.1 (OE), 74HC(T)125.4 (OE), 74HC(T)125.10 (OE), 74HC(T)125.13 (OE), IC2.8 (O)
unnamed: RES-OUT.1, U$2.11 (A2)
unnamed: IC2.3 (I2), U$6.61 (PA5)
unnamed: IC2.2 (I1), U$6.60 (PA3)
unnamed: IC1.3 (I0), U$6.4 (/PARD)
unnamed: IC1.4 (I1), U$6.3 (PA6)
unnamed: IC1.6 (O), IC2.11 (I6)
unnamed: IC2.6 (I5), U$6.28 (PA0)
unnamed: R1.2, RES-IN.1, U$2.13 (A0), U$3.2 (A5)
unnamed: L50.1, R2.2
unnamed: R2.1, U$3.5 (C5)
unnamed: R3.1, U$3.6 (C4)
unnamed: IC1.11 (I2), MODE.1, MODE1.1, U$3.3 (A4)
unnamed: L60.1, R3.2
unnamed: IC1.5 (I2), U$6.34 (PA7)
unnamed: IC2.12 (I7), U$3.7 (C3)
unnamed: U$1.P$1 (1), U$6.56 (CIC_P6)
unnamed: U$2.5 (C5), U$3.10 (C0)
unnamed: IC2.1 (I0), U$6.59 (PA1)
unnamed: IC2.5 (I4), U$6.29 (PA2)
unnamed: IC2.4 (I3), U$6.30 (PA4)
unnamed: CTRL2.1, U$3.11 (A2)
unnamed: CTRL3.1, U$3.12 (A1)
unnamed: CTRL1.1, U$1.P$2 (2), U$2.2 (A5)
unnamed: 74HC(T)125.3 (O), 74HC(T)125.6 (O), 74HC(T)125.8 (O), 74HC(T)125.11 (O), U$6.50 (D4)
unnamed: CTRL4.1, U$3.13 (A0)
unnamed: U$2.10 (C0), U$6.55 (CIC_P2)
unnamed: U$2.9 (C1), U$6.24 (CIC_P1)
unnamed: U$2.8 (C2), U$6.25 (CIC_P7)
unnamed: U$2.6 (C4), U$3.9 (C1)
unnamed: U$2.7 (C3), U$3.8 (C2), U$4.P$2 (2), U$5.P$2 (2)
UIGR: 74HC(T)125.2 (I), 74HC(T)125.5 (I), 74HC(T)125.9 (I), 74HC(T)125.12 (I), U$2.3 (A4), U$3.4 (A3)
VCC: C1.1, C2.1, U$2.1 (VCC), U$3.1 (VCC), U$4.P$1 (1), U$6.27 (VCC)
VCC_2: 74HC(T)125.14 (VCC), C5.1, C6.1, C7.1, IC1.14 (VCC), IC2.14 (VCC), U$6.58 (VCC)

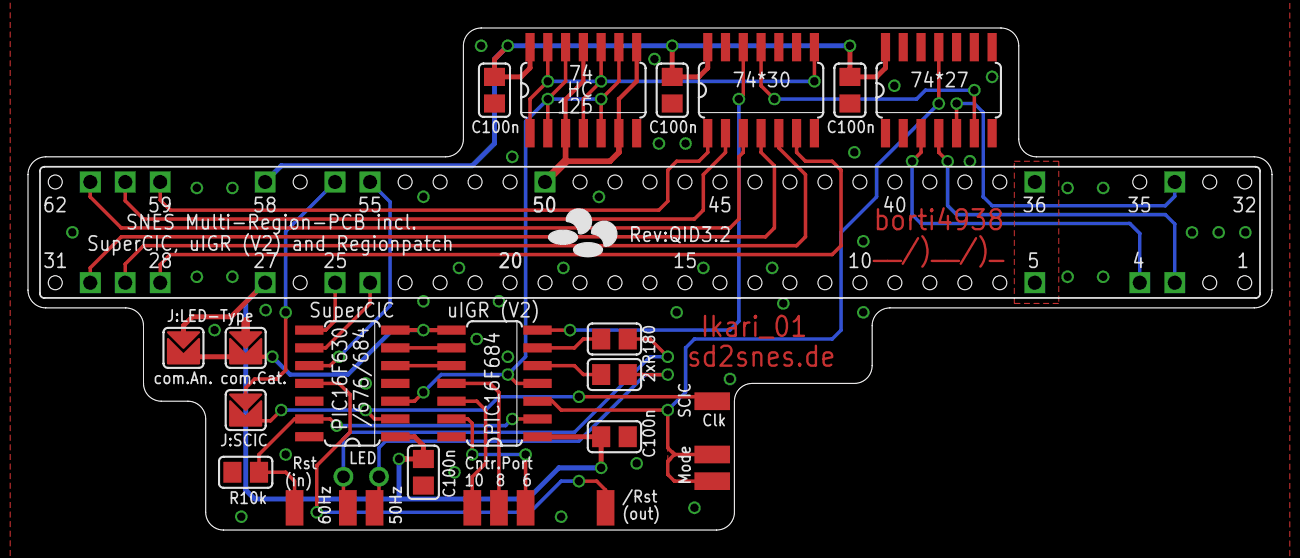
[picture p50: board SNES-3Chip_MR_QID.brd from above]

Board: 2 copper layers, 88.9 x 35.9 mm, 27 parts (0 on the bottom side), 35 nets.

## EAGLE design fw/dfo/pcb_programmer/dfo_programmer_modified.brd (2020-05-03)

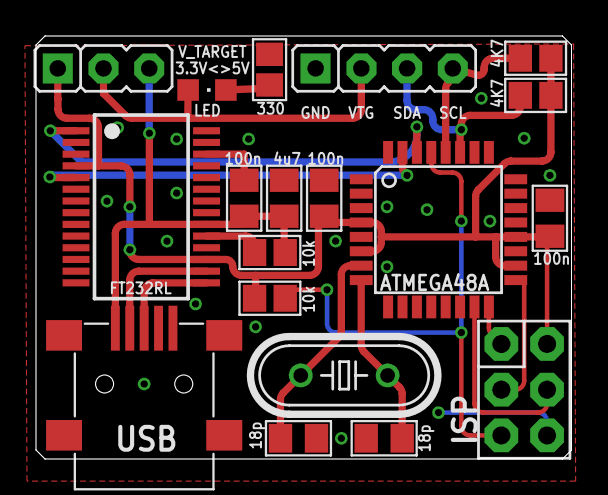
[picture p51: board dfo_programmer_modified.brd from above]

Board: 2 copper layers, 29.8 x 23.5 mm, 19 parts (0 on the bottom side), 18 nets.

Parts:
C1, C5, C6: 100n; C0805K_B
C2: 4u7; C0805K_B
C3, C4: 18p; C0805K_B
E$1: JP2
IC1: FT232RL; SSOP28
IC2: ATMEGA48A; TQFP32-08
JP1: JP3
LED: CHIPLED_0805
Q1: 10M; HC49/S
R1, R2: 10k; R0805_B
R3, R4: 4K7; R0805_B
R5: 330; R0805_B
U$2: ISPBIG_POGO_PINS; 2X3_ISP_BIGPOGO
USB1: LUMBERG2486_01_MINI_USB_B; LUM2486-01

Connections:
!RESET: IC2.29, R1.2, U$2.RESET
+3V3: C5.2, C6.2, E$1.1, IC1.4, IC1.17, IC2.4, IC2.6, IC2.18, IC2.20, R1.1, R3.2, R4.2, U$2.VCC
FT_RX: IC1.5, IC2.31
FT_TX: IC1.1, IC2.30
GND: C1.1, C2.1, C3.1, C4.1, C5.1, C6.1, IC1.7, IC1.18, IC1.21, IC1.25, IC1.26, IC2.3, IC2.5, IC2.21, JP1.1, R5.2, U$2.GND, USB1.5GND
unnamed: LED.C, R5.1
unnamed: C1.2, C2.2, E$1.3, IC1.20, R2.2, USB1.1VBUS
unnamed: IC1.19, R2.1
unnamed: C3.2, IC2.7, Q1.2
unnamed: C4.2, IC2.8, Q1.1
unnamed: IC2.16, U$2.MISO
unnamed: IC2.17, U$2.SCK
unnamed: IC2.15, U$2.MOSI
S$2: IC2.27, JP1.3, R3.1
SCL: IC2.28, JP1.4, R4.1
USB+: IC1.15, USB1.3D+
USB-: IC1.16, USB1.2D-
V_TARGET: E$1.2, JP1.2, LED.A

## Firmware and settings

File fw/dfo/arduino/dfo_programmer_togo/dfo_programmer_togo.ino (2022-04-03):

// Copyright (c) 2020 Peter Bartmann

#include <Wire.h>

#define VERIFY_ONLY   0 // set to 1 if you only want to verify registers
#define WRITE_EEPROM  1 // set to 1 if want to store new register values to EEPROM of CDCE913

// INSERT HERE REGISTER VALUES GENERATED WITH 'generate_byte_buffer.c' PROGRAM
// SNES Multinorm
const byte dfo_regs[32] = {0x01, 0x00, 0xbc, 0x06, 0x01, 0x90, 0x40, 0x00, \
                           0x00, 0x00, 0x00, 0x00, 0x00, 0x00, 0x00, 0x00, \
                           0x00, 0x00, 0x00, 0x01, 0x6b, 0x01, 0x18, 0x05, \
                           0x4f, 0x55, 0x53, 0xec, 0x96, 0xf1, 0x72, 0x69};

// do not edit the following lines
#define I2C_CLOCK_FREQUENCY_KHZ 100

#define BASE_ADDR     0x00
#define NUM_OF_REGS   32

#define I2C_ADDR_REG  0x01
#define EEWRITE_REG   0x06
#define EEWRITE_BIT   0
#define EEPIP_REG     0x01
#define EEPIP_BIT     6

#define LED_PIN 13



const byte CDCE913_I2C_FACADDR = 0x65;
byte serial_available = 0;

void setup() {
  Serial.begin(9600);  // start serial for output
  for (int idx = 0; idx < 500; idx++) {
    if(Serial) {
      serial_available = 1;
      break;
    }
    delay(1);
  };
  Wire.begin(); // join i2c bus (address optional for master)
  Wire.setClock((long int) 1000*I2C_CLOCK_FREQUENCY_KHZ); 
  
  pinMode(LED_PIN, OUTPUT); // sets the digital pin 13 as output (onboard LED)
}


void loop() {
  int idx, jdx;
  byte i2c_cdce913_addr = 0;
  byte bytebuf, compare_byte;
  int error = -1;
  int error_reg = -1;
  
  // Hello
  if (serial_available) Serial.print("Wait for CDCE913: ... ");
  while(error !=0) {
    digitalWrite(LED_PIN, HIGH);
    delay(500);
    digitalWrite(LED_PIN, LOW);
    delay(500);
    for (idx = 0; idx < 4; idx++) {
      Wire.beginTransmission((CDCE913_I2C_FACADDR & 0x7c) | idx);
      error = Wire.endTransmission();
      if (error == 0) break;
    }
  }
  digitalWrite(13, HIGH);
  i2c_cdce913_addr = (byte) (CDCE913_I2C_FACADDR & 0xfc) | idx;
  if (serial_available) {
    Serial.print("Found! (CDCE913 I2C Address: 0x");
    Serial.print(i2c_cdce913_addr, HEX);
    Serial.print(")\n");
  }

  if (serial_available) Serial.print("Write registers: ");

  // write register values
  idx = 0;
  if (!VERIFY_ONLY) {
    for (jdx=0; jdx < 2; jdx++) {
      Wire.beginTransmission(i2c_cdce913_addr);
      Wire.write(BASE_ADDR + jdx*NUM_OF_REGS/2);
      Wire.write(NUM_OF_REGS/2);
      for (idx = 0; idx < NUM_OF_REGS/2; idx++) {
        switch (jdx*NUM_OF_REGS/2 + idx) {
          case I2C_ADDR_REG:
            Wire.write((dfo_regs[jdx*NUM_OF_REGS/2 + idx] & 0xfc) | (i2c_cdce913_addr & 0x03)); // make sure to not overwrite current slave address
            break;
          case EEWRITE_REG:
            Wire.write(dfo_regs[jdx*NUM_OF_REGS/2 + idx] & ~(1<<EEWRITE_BIT));  // do not set the EEWRITE_BIT
            break;
          default:
            Wire.write(dfo_regs[jdx*NUM_OF_REGS/2 + idx]);
        }
        if (serial_available) Serial.print(".");
      }
      Wire.endTransmission();    // stop transmitting
    }
    if (serial_available) Serial.print(" done!\n");
    
    digitalWrite(LED_PIN, LOW);
    delay(100);
    digitalWrite(LED_PIN, HIGH);
  } else {
    if (serial_available) Serial.print("skipped.\n");
  }

  // verify registers
  if (serial_available) Serial.print("Verify registers: ... \n");

  idx = 0;
  error = 0;
  for (jdx=0; jdx < 2; jdx++) {
    Wire.beginTransmission(i2c_cdce913_addr); 
    Wire.write(BASE_ADDR + jdx*NUM_OF_REGS/2);
    Wire.endTransmission();
    
    Wire.requestFrom((int) i2c_cdce913_addr,(int) NUM_OF_REGS/2 + 1);
    (int) Wire.read(); // first value is number of data
    while (Wire.available()) {
      bytebuf = Wire.read(); // receive a byte as character
      if (serial_available) {
          Serial.print(" - Value read at reg 0x");
          Serial.print(idx, HEX);
          Serial.print(": 0x");
          Serial.print(bytebuf, HEX);
      }
      if ((idx != 0) && ((idx < 7) || (idx > 15))) {
        switch (idx) {
          case I2C_ADDR_REG:
            compare_byte = (dfo_regs[idx] & 0xfc) | (i2c_cdce913_addr & 0x03);
            break;
          case EEWRITE_REG:
            compare_byte = (dfo_regs[idx] & ~(1<<EEWRITE_BIT));  // EEWRITE_BIT should not be set, so compare to reg val with cleared bit
            break;
          default: compare_byte = dfo_regs[idx];
        }
        error |= (bytebuf != compare_byte);
        if (serial_available) {
          Serial.print(" (0x");
          Serial.print(compare_byte, HEX);
          Serial.print(" expected)\n");
        }
      } else {
        if (serial_available) Serial.print(" (not evaluated as reg is read only)\n");
      }
      if ((error != 0) && (error_reg < 0)) error_reg = idx;
      idx++;
      delay(10);
      digitalWrite(LED_PIN, LOW);
      delay(10);
      digitalWrite(LED_PIN, HIGH);
    }
  }
  if (error == 0 && idx == NUM_OF_REGS) {
    if (serial_available) Serial.print("... done!\n");
    digitalWrite(13, LOW);
    delay(100);
    digitalWrite(13, HIGH);
  } else {
    if (serial_available) {
      Serial.print("... VERIFICATION ERROR!\n");
      if (idx != NUM_OF_REGS) Serial.print("Number of Bytes not as expected!\n");
      if (error_reg > -1) {
        Serial.print("First register error at 0x");
        Serial.print(error_reg, HEX);
        Serial.print("!\n");
      }
    }
    while(1) {
      digitalWrite(LED_PIN, LOW);
      delay(500);
      digitalWrite(LED_PIN, HIGH);
      delay(500);
    }
  }
  
  // store registers in EEPROM
  if (serial_available) Serial.print("Store registers in EEPROM: ... ");
  
  if (WRITE_EEPROM && !VERIFY_ONLY) {
    // set write bit
    Wire.beginTransmission(i2c_cdce913_addr); 
    Wire.write(EEWRITE_REG);
    Wire.endTransmission();
    
    Wire.requestFrom((int) i2c_cdce913_addr,(int) 2);
    Wire.read();
    bytebuf = Wire.read();
    bytebuf |= (1<<EEWRITE_BIT); // set write bit
    
    Wire.beginTransmission(i2c_cdce913_addr); 
    Wire.write(EEWRITE_REG);
    Wire.write(1);
    Wire.write(bytebuf);
    Wire.endTransmission();

    if (serial_available) Serial.print("requested ... ");

    // wait for completed
    do {
      digitalWrite(LED_PIN, LOW);
      delay(10);
      digitalWrite(LED_PIN, HIGH);
      
      Wire.beginTransmission(i2c_cdce913_addr); 
      Wire.write(EEPIP_REG);
      Wire.endTransmission();
      
      Wire.requestFrom((int) i2c_cdce913_addr,(int) 2);
      Wire.read();
      bytebuf = Wire.read();
    } while (bytebuf & (1<<EEPIP_BIT));
    
    if (serial_available) Serial.print("done!\n");

    // clear write bit
    Wire.beginTransmission(i2c_cdce913_addr); 
    Wire.write(EEWRITE_REG);
    Wire.endTransmission();
    
    Wire.requestFrom((int) i2c_cdce913_addr,(int) 2);
    Wire.read();
    bytebuf = Wire.read();
    bytebuf &= ~(1<<EEWRITE_BIT); // clear write bit
    
    Wire.beginTransmission(i2c_cdce913_addr); 
    Wire.write(EEWRITE_REG);
    Wire.write(1);
    Wire.write(bytebuf);
    Wire.endTransmission();
    
    digitalWrite(LED_PIN, LOW);
    delay(100);
    digitalWrite(LED_PIN, HIGH);
  } else {
    if (serial_available) Serial.print("skipped.\n");
  }

  if (serial_available) Serial.print("SUCCESS!\n");
  while(1) {
    digitalWrite(LED_PIN, LOW);
    delay(2000);
    digitalWrite(LED_PIN, HIGH);
    delay(2000);
  }
}

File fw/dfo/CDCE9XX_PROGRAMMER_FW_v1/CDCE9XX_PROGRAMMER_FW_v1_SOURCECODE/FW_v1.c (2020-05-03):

/*
 * FW_v1.c
 *
 * Created: 15.03.2015 18:32:22
 * Author: Jakob Schäfer
 *
 * Firmware für die CDCE9XX Programmer-Hardware
 *
 * Dieses Programm nutzt die I2C Bibliothek von Peter Fleury
 * http://tinyurl.com/peterfleury 
 *
 * v1.0 - initial release
 *
 * F_CPU muss in der Toolchain deklariert werden mit 8 MHz:
 * Toolchain->AVR/GNU C Compiler->Symbols->Add Symbol->F_CPU=8000000UL 
 *
 * Fuses:
 *		- low byte:		0xFF
 *		- high byte:	0xDF
 */ 

/******************************************************************************
Includes
******************************************************************************/
#include <avr/io.h>
#include <util/delay.h>
#include "i2cmaster.h"

/******************************************************************************
Macros & Defines
******************************************************************************/
#define ID "CDCE9XX_PROGRAMMER"
#define FW_VERSION "1.0"
#define FW_DATE "31.03.2015"
#define ERR_NOERROR 0
#define ERR_PROTOCOL 1
#define ERR_I2C 2
#define ERR_VERIFY 3
#define BAUDRATE 9600UL
#define UBBR0 ( (F_CPU/(16*BAUDRATE)) -1 )

/******************************************************************************
Prototypen
******************************************************************************/
void initUART0(void);
void writeCharToUART0(uint8_t data);
uint8_t readCharFromUART0(void);
void flushRxFIFO(void);
void writeStringToUART0(char* string);
uint8_t readRegisterFromCDCE9XX(uint8_t deviceAddress,
								uint8_t registerAddress,
								uint8_t* error);
void writeRegisterToCDCE9XX(	uint8_t deviceAddress,
								uint8_t registerAddress,
								uint8_t data,
								uint8_t* error);
uint8_t readProgrammingParameters(void);
uint8_t programCDCE9XX(void);
					
/******************************************************************************
Globale Variablen
******************************************************************************/
uint8_t devAddress;			// i2c-Adresse des zu programmierenden CDCE9XX
uint8_t nRegisters;			// Anzahl der zu programmierenden Register
uint8_t registers[80];		// Array für Register, max 80 Register beim CDCE949
uint8_t storeEEPROM;		// sollen Register im EEPROM gespeichert werden?

/******************************************************************************
Main
******************************************************************************/
int main(void)
{
	uint8_t error;				// 0: kein Fehler beim Einlesen/Programmieren
	
	i2c_init();					// i2c-Schnittstelle initialisieren
	initUART0();				// UART0-Schnittstelle initialisieren	
								
    while(1)
    {	
		// Wenn ein Zeichen am UART0 anliegt:
		if ( UCSR0A & (1<<RXC0) ){
			
			error = ERR_NOERROR;
			
			switch (readCharFromUART0()){
				
				case '?':	
					// ID senden
					writeStringToUART0(ID);
					break;
					
				case 'V':
				case 'v':
					// Firmware Version senden
					writeStringToUART0(FW_VERSION);
					break;	
									
				case 'D':	
				case 'd':
					// Firmware Datum senden
					writeStringToUART0(FW_DATE);
					break;	
									
				case 'W':
				case 'w':
					// Registerwerte und weitere Parameter einlesen
					error = readProgrammingParameters();
					// CDCE9XX jetzt programmieren
					if (!error) error = programCDCE9XX();
					// Fehler als Ergebnis zurücksenden
					writeCharToUART0(error);
					break;
				
				default:
					error = ERR_PROTOCOL;
					// Falls weitere Zeichen im UART, alle verwerfen:
					flushRxFIFO();
					// Protokollfehler senden:
					writeCharToUART0(error);					
					break;					
			} // End Switch
			
		} // Ende - Daten am UART0
        
    } // Ende Main-Loop
	
} // Ende Main

uint8_t readProgrammingParameters(void){
// liest die für CDCE9XX-Programmierung nötigen Parameter ein

	uint8_t error = ERR_NOERROR;
	uint8_t i = 0;
	
	// i2c-Adresse des CDCE9XX einlesen
	devAddress = readCharFromUART0();
	if (devAddress > 127) error = ERR_PROTOCOL;
	
	// Register im CDCE9XX-EEPROM speichern?
	// 0: nein; 1: ja 
	storeEEPROM = readCharFromUART0();
	if (storeEEPROM > 1) error = ERR_PROTOCOL;
	
	// Anzahl der zu programmierenden Reg. einlesen 
	if (!error) nRegisters = readCharFromUART0();
	// zulässige Anzahl: 32, 48, 64 oder 80 Register
	if ((nRegisters!=32)&&(nRegisters!=48)&&
		(nRegisters!=64)&&(nRegisters!=80)) error = ERR_PROTOCOL;
		
	// alle Register-Werte einlesen
	if (!error){
		while (i<nRegisters) registers[i++] = readCharFromUART0();
	}
	
	// Danach sollten keine weiteren Daten mehr im Puffer
	// vorliegen. Wenn doch ==> Protokoll-Fehler!
	_delay_ms(20);
	if (UCSR0A & (1<<RXC0)){
		error = ERR_PROTOCOL;
		flushRxFIFO();
	}
	
	return error;
}

uint8_t programCDCE9XX(void){
// programmiert den CDCE9XX und gibt einen Fehlercode zurück

	uint8_t error = ERR_NOERROR;
	uint8_t i, temp, register0x06;	
	
	// zunächst alle Register beschreiben
	i = 0;
	while( (i<nRegisters) && (!error)){
		writeRegisterToCDCE9XX(devAddress, i, registers[i], &error);
		i++;
	}
	
	// storeToEEPROM = 1? => Register im EEPROM abspeichern
	if ( storeEEPROM && (!error) ){
		// dafür zunächst Register 0x06 auslesen
		register0x06 = readRegisterFromCDCE9XX(devAddress, 0x06, &error);
		// dann das EEWRITE-Bit setzen:
		register0x06 |= (1<<0);
		// und den Wert in Register 0x06 zurückschreiben
		if (!error) writeRegisterToCDCE9XX(devAddress, 0x06, register0x06, &error);
		
		// jetzt solange Register 0x01 auslesen bis EEPROM-
		// Schreibvorgang abgeschlossen ist (EEPIP-Bit = 0)
		if (!error){
			do{
				temp = readRegisterFromCDCE9XX(devAddress, 0x01, &error);
			}while( (temp&(1<<6)) && (!error) );
		}		
		// Schreibvorgang beendet, EEWRITE-Bit in Register 0x06 muss wieder gelöscht werden
		register0x06 &= ~(1<<0);
		if (!error) writeRegisterToCDCE9XX(devAddress, 0x06, register0x06, &error);
	}
	
	// Nach erfolgtem Schreiben der Register, nun wieder alle Register auslesen und vergleichen:
	i = 0;
	while ( (i<nRegisters) && !error){
		// i. Register einlesen
		temp = readRegisterFromCDCE9XX(devAddress, i, &error);
		// Register 0x00 und 0x07 bis 0x0F nicht vergleichen, da read-only bzw. unbestimmt
		if (!error && ((i!=0x00) && (i<0x7) && (i>0x0F))){
			// Wenn geschriebener und gelesener Wert unterschiedlich ==> Verify-Fehler
			if (temp != registers[i]) error = ERR_VERIFY;
		}
		i++;
	}

	return error;
}

								
uint8_t readRegisterFromCDCE9XX(uint8_t deviceAddress, 
								uint8_t registerAddress,
								uint8_t* error){
							
	uint8_t data = 0;
	uint8_t err = 0;
		
	err = i2c_start( (deviceAddress<<1) + I2C_WRITE) * ERR_I2C;
	if(!err) err = i2c_write(128 + registerAddress) * ERR_I2C;
	if(!err) err = i2c_rep_start( (deviceAddress<<1) + I2C_READ) * ERR_I2C;
	if(!err) data = i2c_readNak();
	i2c_stop();
	
	*error = err;
	return data;
}
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

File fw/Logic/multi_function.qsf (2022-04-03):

# -------------------------------------------------------------------------- #
#
# Copyright (C) 1991-2013 Altera Corporation
# Your use of Altera Corporation's design tools, logic functions
# and other software and tools, and its AMPP partner logic
# functions, and any output files from any of the foregoing
# (including device programming or simulation files), and any
# associated documentation or information are expressly subject
# to the terms and conditions of the Altera Program License
# Subscription Agreement, Altera MegaCore Function License
# Agreement, or other applicable license agreement, including,
# without limitation, that your use is for the sole purpose of
# programming logic devices manufactured by Altera and sold by
# Altera or its authorized distributors.  Please refer to the
# applicable agreement for further details.
#
# -------------------------------------------------------------------------- #
#
# Quartus II 64-Bit
# Version 13.0.1 Build 232 06/12/2013 Service Pack 1 SJ Web Edition
# Date created = 01:40:55  December 16, 2017
#
# -------------------------------------------------------------------------- #
#
# Notes:
#
# 1) The default values for assignments are stored in the file:
#		multi_function_assignment_defaults.qdf
#    If this file doesn't exist, see file:
#		assignment_defaults.qdf
#
# 2) Altera recommends that you do not modify this file. This
#    file is updated automatically by the Quartus II software
#    and any changes you make may be lost or overwritten.
#
# -------------------------------------------------------------------------- #


set_global_assignment -name FAMILY MAX7000AE
set_global_assignment -name DEVICE "EPM7032AETC44-10"
set_global_assignment -name ORIGINAL_QUARTUS_VERSION "13.0 SP1"
set_global_assignment -name PROJECT_CREATION_TIME_DATE "23:07:46  APRIL 07, 2019"
set_global_assignment -name LAST_QUARTUS_VERSION "13.0 SP1.02"
set_global_assignment -name ERROR_CHECK_FREQUENCY_DIVISOR "-1"

set_location_assignment PIN_28 -to NPARD
set_location_assignment PIN_31 -to ADDRESS_BUS_B[7]
set_location_assignment PIN_30 -to ADDRESS_BUS_B[6]
set_location_assignment PIN_3 -to ADDRESS_BUS_B[5]
set_location_assignment PIN_8 -to ADDRESS_BUS_B[4]
set_location_assignment PIN_2 -to ADDRESS_BUS_B[3]
set_location_assignment PIN_10 -to ADDRESS_BUS_B[2]
set_location_assignment PIN_43 -to ADDRESS_BUS_B[1]
set_location_assignment PIN_11 -to ADDRESS_BUS_B[0]
set_location_assignment PIN_42 -to NDRIVE_D4
set_location_assignment PIN_5 -to EN_REGPATCH

set_location_assignment PIN_20 -to SEL_SNES_1CHIP
set_location_assignment PIN_6 -to PALMODE
set_location_assignment PIN_35 -to NPALMODE[1]
set_location_assignment PIN_12 -to NPALMODE[0]

set_location_assignment PIN_37 -to MCLK_base_i
set_location_assignment PIN_27 -to MCLK_PAL_ext_i
set_location_assignment PIN_22 -to MCLK_o
set_location_assignment PIN_19 -to ColorCarrier_opt_o
set_location_assignment PIN_21 -to ColorCarrier_o

set_location_assignment PIN_44 -to DEJITTER_BYPASS
set_location_assignment PIN_33 -to CSYNC_i
set_location_assignment PIN_34 -to CSYNC_o[1]
set_location_assignment PIN_13 -to CSYNC_o[0]


set_global_assignment -name PROJECT_OUTPUT_DIRECTORY output_files/multi_func
set_global_assignment -name TOP_LEVEL_ENTITY snes_mult_func
set_global_assignment -name VERILOG_FILE rtl/snes_mult_func.v
set_global_assignment -name VERILOG_FILE rtl/snes_dejitter_mod.v
set_global_assignment -name SDC_FILE multi_function.sdc

set_global_assignment -name MAX7000_DEVICE_IO_STANDARD "3.3-V LVTTL"
set_global_assignment -name SYNTH_TIMING_DRIVEN_SYNTHESIS OFF
set_global_assignment -name OPTIMIZE_HOLD_TIMING OFF
set_global_assignment -name OPTIMIZE_MULTI_CORNER_TIMING OFF

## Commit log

2020-05-03 initial commit as stand alone project
    [BOM.xlsx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]
2020-05-03 add older PCB versions
    [SNES-1Chip_MR_QID.brd, SNES-1Chip_MR_QID.sch, SNES-3Chip_MR_QID.brd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]
2020-05-04 color subcarrier fix - initial commit was based on old version here
    [multi_function.qsf]
2020-08-30 resolve inconsistency between schematic and BOM
    [SNES_MR_DeJitter_QID.brd, SNES_MR_DeJitter_QID.sch]
2020-09-07 DFO programmer to go: - Arduino sketch (e.g. for Arduino Nano Every) - tools (to generate const byte regs[], e.g. for other projects)
2020-09-08 replace some magic numbers
    [dfo_programmer_togo.ino]
2020-12-01 write and read registers in bytes (solve issue #2)
    [dfo_programmer_togo.ino]
2022-04-03 add CPLD with 64MCs
    [BOM.xlsx]
2022-04-03 update BOM
    [BOM.xlsx]

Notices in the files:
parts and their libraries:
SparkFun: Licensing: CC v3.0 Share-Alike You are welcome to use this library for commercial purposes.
